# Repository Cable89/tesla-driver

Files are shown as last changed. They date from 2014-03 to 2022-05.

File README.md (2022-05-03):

# tesla-driver
Modular backplane based DRSSTC driver developed in my time as a student at Omega Verksted.

This is a mirror of a self hosted repo. (Sometimes unstable, or security settings change)
This mirror is not always up to date.
Original repo: https://git.omegav.no/teslakom/tesla-driver

Documentation: https://confluence.omegav.no/display/OV/Teslacoil
(Mostly in Norwegian, use google translate)

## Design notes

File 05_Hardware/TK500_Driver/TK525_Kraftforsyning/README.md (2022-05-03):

Ingen kretskort i dette prosjektet. Kun .PcbDoc for å kunne ha det med i multi board project

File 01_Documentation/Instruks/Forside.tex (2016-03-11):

\newgeometry{margin=2cm} %Sentrering av forside og tittelside
\begin{titlepage}
\thispagestyle{empty}
\centering
\textsc{\Huge Instruks for teslacoil} \\[3cm]

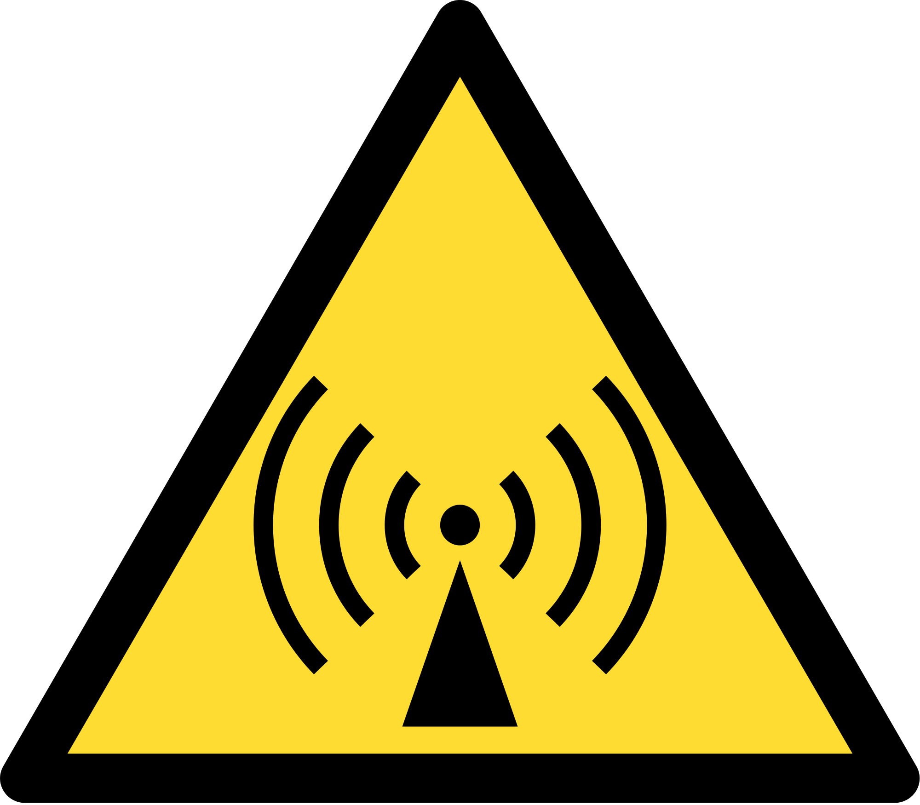
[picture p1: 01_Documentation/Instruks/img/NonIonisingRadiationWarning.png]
 \\[3cm]

\textsc{\Huge Teslakom} \\
\textsc{\Huge Omega Verksted} 

\end{titlepage}

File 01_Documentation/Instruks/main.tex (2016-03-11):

\documentclass[12pt,Norwegian,a4paper,twoside,openright,titlepage]{article}
\title{Autopilot}
\usepackage[utf8]{inputenc}
\usepackage[a4paper, bottom=4.0cm]{geometry}
\usepackage{amsmath,amsfonts,amssymb}
\usepackage{amsthm}                   
\usepackage{graphicx}  
\usepackage{subfig}         
\usepackage{listings}             
\usepackage{float}
\usepackage{lastpage}
\usepackage{fancyhdr}
\usepackage[]{natbib} %referanser
\usepackage{cleveref}
\pagestyle{fancy}
\usepackage{makeidx}  
\usepackage{ulem}
\usepackage{pdfpages}
\usepackage{url}
\usepackage[utf8]{inputenc}
\usepackage[T1]{fontenc}
\usepackage[english]{babel}
\usepackage{graphicx}			%Figurer
\usepackage{fancyhdr}			%Fancy headere
 
\makeindex
\fancyhf{}
\chead{Teslacoilinstruks}
\setlength{\oddsidemargin}{5mm}
\setlength{\evensidemargin}{5mm}

\begin{document}

  \input{forside}
  \cleardoublepage

  \cfoot{page \thepage}  
	\newpage
  \tableofcontents

  \newpage

  \pagenumbering{arabic}
  \cfoot{page \thepage\ of \pageref{LastPage}} 
  
  \input{overordnet}

  \newpage
  \bibliographystyle{plain}
  \bibliography{ref}

\end{document}

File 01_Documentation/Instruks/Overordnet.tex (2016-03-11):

Arbeidsoppgaver:
Overtesler
Hanskeholder
Fuckoperatør
Driveroperatør
Nødstopper
Vakter

I utgangspunktet en person pr. arbeidsoppgave, men overtesler kan ha to arbeidsoppgaver.

Overtesler skal ikke være samme person som Hanskeholder.

Overtesler velges først.

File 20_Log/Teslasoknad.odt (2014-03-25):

Søknad om penger til oppgradering av teslacoil

Omega Verksted søker med dette dokumentet om kr 6000,- til oppgradering av teslacoilen (til bruk blant annet på phaestum). Oppgraderingene består i å vikle ny sekundærspole, lage ny primærspole og stativ, og lage en ny driver og en reservedriver. Samt forbedre muligheter til input. Blant annet midi-inngang som muliggjør at Omega Bano kan spille gitar på teslacoil. Beløpet som søkes om er spesifisert i vedlagte busjett.

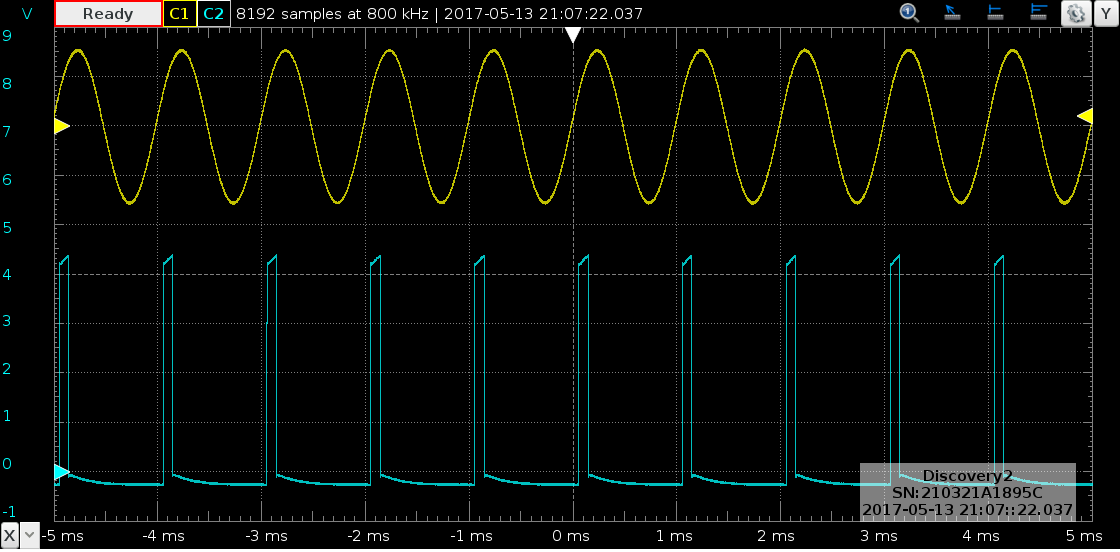
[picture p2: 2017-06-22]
01_Documentation/Målinger/Tesla/2017-05-13_X1-X2_2_1kHz.png

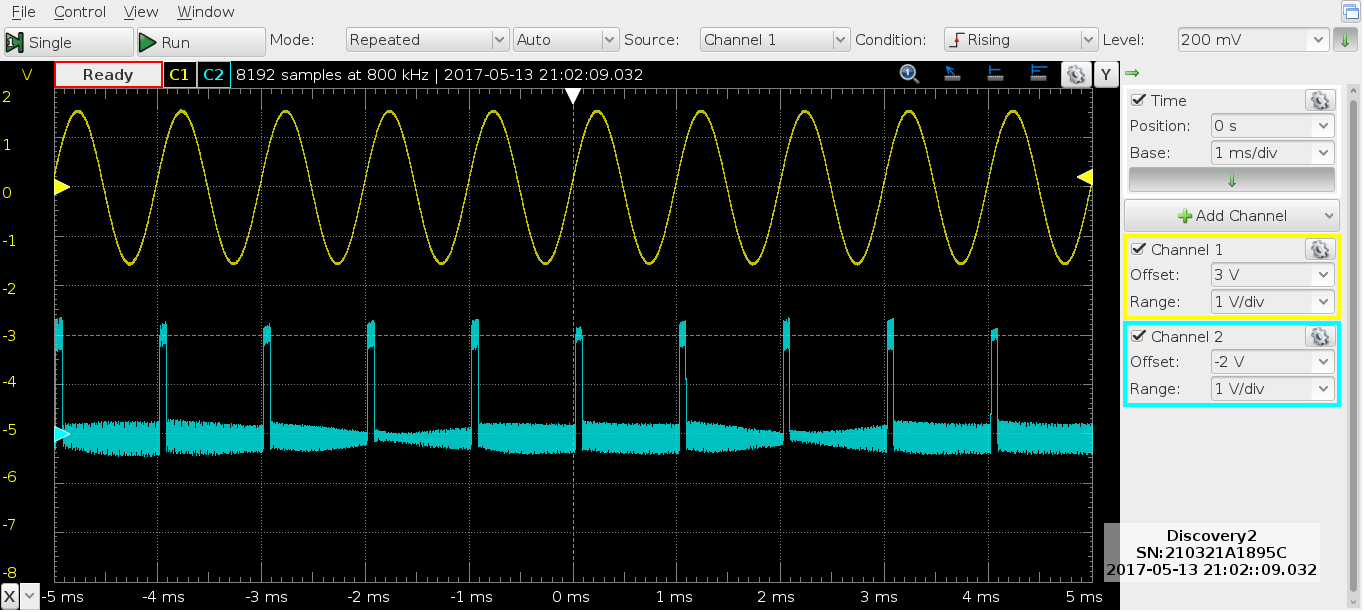
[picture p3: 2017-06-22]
01_Documentation/Målinger/Tesla/2017-05-13_X1-X2_1kHz.png

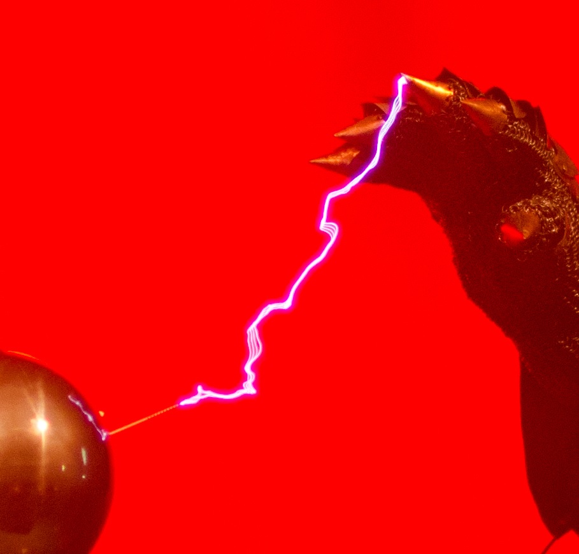
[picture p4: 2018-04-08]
01_Documentation/Figurer/Streamer.jpg

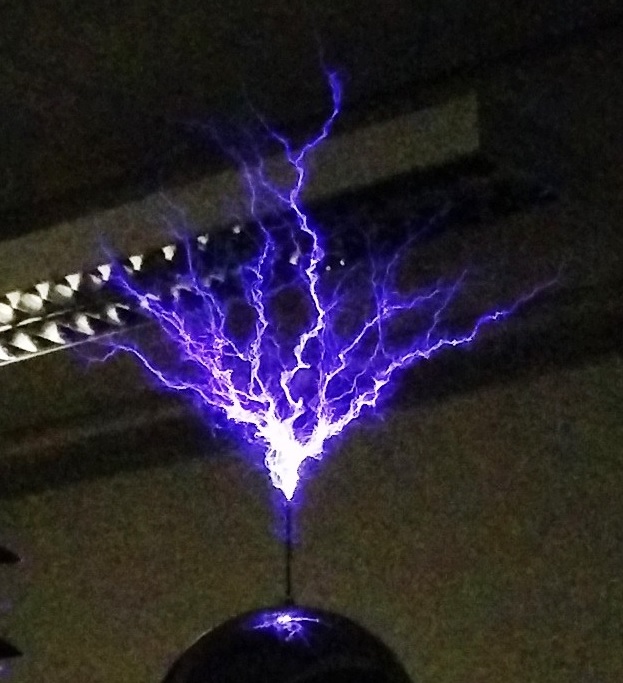
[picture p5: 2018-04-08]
01_Documentation/Figurer/Corona.jpg

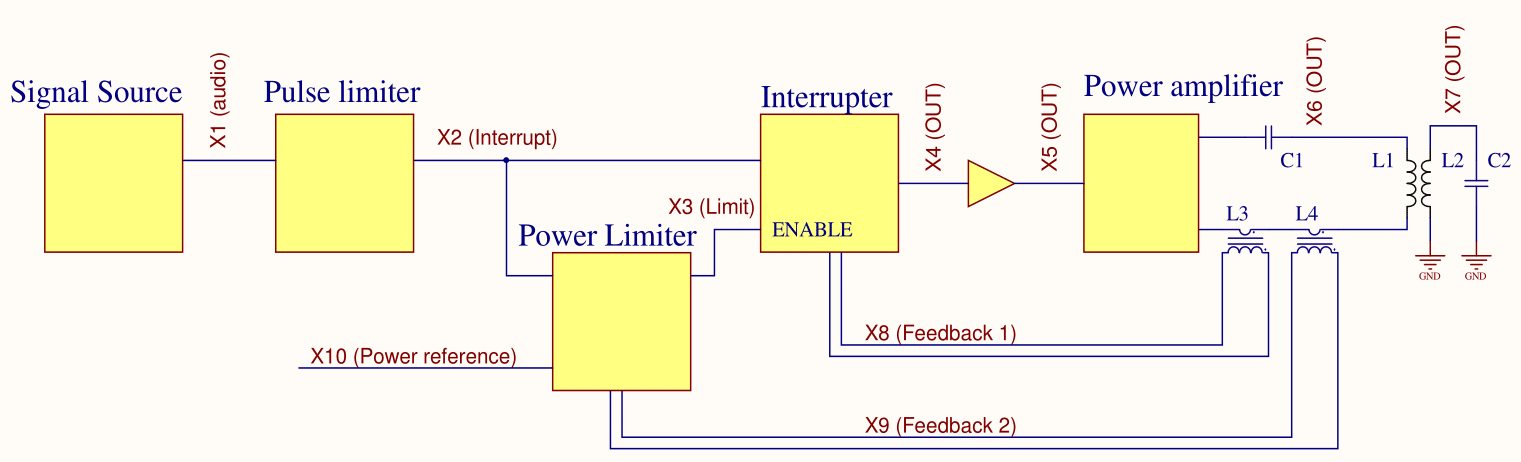
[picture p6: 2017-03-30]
01_Documentation/Figurer/FunksjonsBlokkskjema.png

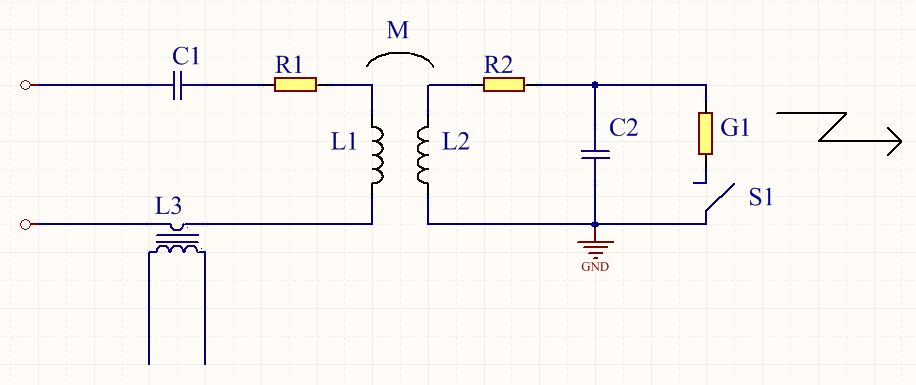
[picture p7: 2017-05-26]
01_Documentation/Forenklet skjema/Teslamodell_1.PNG

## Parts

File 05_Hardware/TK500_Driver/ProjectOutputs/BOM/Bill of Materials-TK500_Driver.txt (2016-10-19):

Designator	navn	beskrivelse	pris

"Q53002"	"TSM2314"	"N-Channel MOSFET"	"-1"
"Q53001"	"TSM2314"	"N-Channel MOSFET"	"-1"
"Q53000"	"TSM2314"	"N-Channel MOSFET"	"-1"
"Q51012"	"TSM2314"	"N-Channel MOSFET"	"-1"
"Q51008"	"TSM2314"	"N-Channel MOSFET"	"-1"
"Q51007"	"TSM2314"	"N-Channel MOSFET"	"-1"
"Q51006"	"TSM2314"	"N-Channel MOSFET"	"-1"
"Q51002"	"TSM2314"	"N-Channel MOSFET"	"-1"
"Q51001"	"TSM2314"	"N-Channel MOSFET"	"-1"
"Q51000"	"TSM2314"	"N-Channel MOSFET"	"-1"
"L52501"	"Skilletrafo 2:1"	""	"500"
"D53002"	"SMD LED Red"	"SMD"	"1"
"D53001"	"SMD LED Red"	"SMD"	"1"
"D53000"	"SMD LED Red"	"SMD"	"1"
"D52501"	"SMD LED Red"	""	"1"
"D51006"	"SMD LED Red"	"SMD"	"1"
"D51201"	"SMD LED Red"	"SMD"	"1"
"D51005"	"SMD LED Red"	"SMD"	"1"
"D51004"	"SMD LED Red"	"SMD"	"1"
"D51000"	"SMD LED Red"	"SMD"	"1"
"D51008"	"SMD LED Red"	"SMD"	"1"
"D51007"	"SMD LED Red"	"SMD"	"1"
"D53003"	"SMBJ5.0A-TR"	"Transient Voltage Suppressor, TVS, Transil SMBJ Series, Unidirectional, 5 V, SMD, 2, 6.4 V"	"1"
"M53100_TK531_2"	"SK-454-75-SA"	""	"14"
"M53100_TK531_1"	"SK-454-75-SA"	""	"14"
"T52001"	"SD250-3"	"Dual Gate Drive Transformer"	"-1"
"T52000"	"SD250-3"	"Dual Gate Drive Transformer"	"-1"
"D50213"	"Rød LED 5mm"	"LED, Red, 5mm, 643 nm, 1.8 V, 20 mA, 400 mcd"	"3"
"D50210"	"Rød LED 5mm"	"LED, Red, 5mm, 643 nm, 1.8 V, 20 mA, 400 mcd"	"3"
"D50207"	"Rød LED 5mm"	"LED, Red, 5mm, 643 nm, 1.8 V, 20 mA, 400 mcd"	"3"
"D50204"	"Rød LED 5mm"	"LED, Red, 5mm, 643 nm, 1.8 V, 20 mA, 400 mcd"	"3"
"D50201"	"Rød LED 5mm"	"LED, Red, 5mm, 643 nm, 1.8 V, 20 mA, 400 mcd"	"3"
"D50216"	"Rød LED 5mm"	"LED, Red, 5mm, 643 nm, 1.8 V, 20 mA, 400 mcd"	"3"
"J51400"	"PCIeX1-GF-2D-1000-1K-O36"	""	"0"
"J51100_TK511"	"PCIeX1-GF-2D-1000-1K-O36"	""	"0"
"J51100_TK511_2"	"PCIeX1-GF-2D-1000-1K-O36"	""	"0"
"J51005"	"PCI_Express-36P"	"PCI_Express-36P"	"16"
"J51004"	"PCI_Express-36P"	"PCI_Express-36P"	"16"
"J51003"	"PCI_Express-36P"	"PCI_Express-36P"	"16"
"J51002"	"PCI_Express-36P"	"PCI_Express-36P"	"16"
"J51001"	"PCI_Express-36P"	"PCI_Express-36P"	"16"
"J51000"	"PCI_Express-36P"	"PCI_Express-36P"	"16"
"J53100_TK531_1"	"MPTC-02-16-02-01-03-L-RA-SD"	""	"30"
"J53100_TK531_2"	"MPTC-02-16-02-01-03-L-RA-SD"	""	"30"
"J53002"	"MPSC-02-16-02-7.70-03-L-V-LC"	"SAMTEC Connector"	"30"
"J53001"	"MPSC-02-16-02-7.70-03-L-V-LC"	"SAMTEC Connector"	"30"
"J53000"	"MPSC-02-16-02-7.70-03-L-V-LC"	""	"30"
"U51000"	"MOCD207R2M"	""	"4"
"F53001"	"MC36214"	""	"2"
"F53000"	"MC36214"	""	"2"
"C52500"	"MAL209636222E3"	""	"340"
"L52501"	"Lampe"	""	"0"
"L52500"	"Lampe"	""	"0"
"M53005"	"KortStøtte"	"Støtter kort i bakplan"	"5"
"M53004"	"KortStøtte"	"Støtter kort i bakplan"	"5"
"M53003"	"KortStøtte"	"Støtter kort i bakplan"	"5"
"M53002"	"KortStøtte"	"Støtter kort i bakplan"	"5"
"M53001"	"KortStøtte"	"Støtter kort i bakplan"	"5"
"M53000"	"KortStøtte"	"Støtter kort i bakplan"	"5"
"M51017"	"KortStøtte"	"Støtter kort i bakplan"	"5"
"M51016"	"KortStøtte"	"Støtter kort i bakplan"	"5"
"M51015"	"KortStøtte"	"Støtter kort i bakplan"	"5"
"M51014"	"KortStøtte"	"Støtter kort i bakplan"	"5"
"M51013"	"KortStøtte"	"Støtter kort i bakplan"	"5"
"M51012"	"KortStøtte"	"Støtter kort i bakplan"	"5"
"M51011"	"KortStøtte"	"Støtter kort i bakplan"	"5"
"M51010"	"KortStøtte"	"Støtter kort i bakplan"	"5"
"M51009"	"KortStøtte"	"Støtter kort i bakplan"	"5"
"M51008"	"KortStøtte"	"Støtter kort i bakplan"	"5"
"M51007"	"KortStøtte"	"Støtter kort i bakplan"	"5"
"M51006"	"KortStøtte"	"Støtter kort i bakplan"	"5"
"M51005"	"KortStøtte"	"Støtter kort i bakplan"	"5"
"M51004"	"KortStøtte"	"Støtter kort i bakplan"	"5"
"M51003"	"KortStøtte"	"Støtter kort i bakplan"	"5"
"M51002"	"KortStøtte"	"Støtter kort i bakplan"	"5"
"M51001"	"KortStøtte"	"Støtter kort i bakplan"	"5"
"M51000"	"KortStøtte"	"Støtter kort i bakplan"	"5"
"K52501"	"Kontaktor"	""	"50"
"K52500"	"Kontaktor"	""	"50"
"K52500"	"Kontaktor"	""	"50"
"J53005"	"JST 4pin"	""	"2"
"J53004"	"JST 4pin"	""	"2"
"J53003"	"JST 4pin"	""	"2"
"J50203"	"JST 3pin"	""	"2"
"J50202"	"JST 3pin"	""	"2"
"J50201"	"JST 3pin"	""	"2"
"J50200"	"JST 3pin"	""	"2"
"J50205"	"JST 3pin"	""	"2"
"J50204"	"JST 3pin"	""	"2"
"J51025"	"JST 2pin"	"pris pr. stk."	"2"
"J51406"	"JST 2pin"	""	"2"
"J51017"	"JST 2pin"	"pris pr. stk."	"2"
"J51024"	"JST 2pin"	"pris pr. stk."	"2"
"J51023"	"JST 2pin"	"pris pr. stk."	"2"
"J51202"	"JST 2pin"	""	"2"
"J51201"	"JST 2pin"	""	"2"
"J51200"	"JST 2pin"	""	"2"
"J51016"	"JST 2pin"	"pris pr. stk."	"2"
"J51022"	"JST 2pin"	"pris pr. stk."	"2"
"J51021"	"JST 2pin"	"pris pr. stk."	"2"
"J51015"	"JST 2pin"	"pris pr. stk."	"2"
"J53006"	"JST 2pin"	""	"2"
"J51014"	"JST 2pin"	"pris pr. stk."	"2"
"J51013"	"JST 2pin"	"pris pr. stk."	"2"
"J51012"	"JST 2pin"	"pris pr. stk."	"2"
"J51006"	"JST 2pin"	""	"2"
"J51026"	"JST 2pin"	"pris pr. stk."	"2"
"J51203"	"JST 2pin"	""	"2"
"J51407"	"JST 2pin"	""	"2"
"J53008"	"JST 2pin"	""	"2"
"Q53005"	"IRLML6402"	"P-ch. MOSFET. -30V, -3.7A continuous,RDS(ON)=0.05Ohm@VGS=-4,5V, RDS(ON)=0.08Ohm@VGS=-2.5V"	"3"
"Q53004"	"IRLML6402"	"P-ch. MOSFET. -30V, -3.7A continuous,RDS(ON)=0.05Ohm@VGS=-4,5V, RDS(ON)=0.08Ohm@VGS=-2.5V"	"3"
"Q53003"	"IRLML6402"	"P-ch. MOSFET. -30V, -3.7A continuous,RDS(ON)=0.05Ohm@VGS=-4,5V, RDS(ON)=0.08Ohm@VGS=-2.5V"	"3"
"Q51011"	"IRLML6402"	"P-ch. MOSFET. -30V, -3.7A continuous,RDS(ON)=0.05Ohm@VGS=-4,5V, RDS(ON)=0.08Ohm@VGS=-2.5V"	"3"
"Q51010"	"IRLML6402"	"P-ch. MOSFET. -30V, -3.7A continuous,RDS(ON)=0.05Ohm@VGS=-4,5V, RDS(ON)=0.08Ohm@VGS=-2.5V"	"3"
"Q51009"	"IRLML6402"	"P-ch. MOSFET. -30V, -3.7A continuous,RDS(ON)=0.05Ohm@VGS=-4,5V, RDS(ON)=0.08Ohm@VGS=-2.5V"	"3"
"Q51005"	"IRLML6402"	"P-ch. MOSFET. -30V, -3.7A continuous,RDS(ON)=0.05Ohm@VGS=-4,5V, RDS(ON)=0.08Ohm@VGS=-2.5V"	"3"
"Q51004"	"IRLML6402"	"P-ch. MOSFET. -30V, -3.7A continuous,RDS(ON)=0.05Ohm@VGS=-4,5V, RDS(ON)=0.08Ohm@VGS=-2.5V"	"3"
"Q51003"	"IRLML6402"	"P-ch. MOSFET. -30V, -3.7A continuous,RDS(ON)=0.05Ohm@VGS=-4,5V, RDS(ON)=0.08Ohm@VGS=-2.5V"	"3"
"J51101_TK511_2"	"Header Shrouded 2X17P"	""	"10"
"J51027"	"Header Shrouded 2X17P"	""	"10"
"J50206"	"Header Shrouded 2X17P"	""	"10"
"J51101_TK511"	"Header Shrouded 2X17P"	""	"10"
"J51019"	"Header Shrouded 2X5P"	"Header"	"5"
"J51018"	"Header Shrouded 2X5P"	"Header"	"5"
"J53007"	"Header Shrouded 2X5P"	""	"5"
"J51011"	"Header Shrouded 2X5P"	"Header"	"5"
"J51010"	"Header Shrouded 2X5P"	"Header"	"5"
"J51009"	"Header Shrouded 2X5P"	"Header"	"5"
"J51020"	"Header Shrouded 2X5P"	"Header"	"5"
"J51106_TK511_2"	"Header 1x3"	""	"2"
"J51106_TK511"	"Header 1x3"	""	"2"
"J51105_TK511_2"	"Header 1x3"	""	"2"
"J51104_TK511"	"Header 1x3"	""	"2"
"J51105_TK511"	"Header 1x3"	""	"2"
"J51103_TK511_2"	"Header 1x3"	""	"2"
"J51104_TK511_2"	"Header 1x3"	""	"2"
"J51103_TK511"	"Header 1x3"	""	"2"
"J51102_TK511_2"	"Header 1x3"	""	"2"
"J51102_TK511"	"Header 1x3"	""	"2"
"D50212"	"Grønn LED 5mm"	"LED, Green, 5mm, 572 nm, 2.1 V, 20 mA, 150 mcd"	"3"
"D50211"	"Grønn LED 5mm"	"LED, Green, 5mm, 572 nm, 2.1 V, 20 mA, 150 mcd"	"3"
"D50209"	"Grønn LED 5mm"	"LED, Green, 5mm, 572 nm, 2.1 V, 20 mA, 150 mcd"	"3"
"D50208"	"Grønn LED 5mm"	"LED, Green, 5mm, 572 nm, 2.1 V, 20 mA, 150 mcd"	"3"
"D50206"	"Grønn LED 5mm"	"LED, Green, 5mm, 572 nm, 2.1 V, 20 mA, 150 mcd"	"3"
"D50205"	"Grønn LED 5mm"	"LED, Green, 5mm, 572 nm, 2.1 V, 20 mA, 150 mcd"	"3"
"D50203"	"Grønn LED 5mm"	"LED, Green, 5mm, 572 nm, 2.1 V, 20 mA, 150 mcd"	"3"
"D50202"	"Grønn LED 5mm"	"LED, Green, 5mm, 572 nm, 2.1 V, 20 mA, 150 mcd"	"3"
"D50200"	"Grønn LED 5mm"	"LED, Green, 5mm, 572 nm, 2.1 V, 20 mA, 150 mcd"	"3"
"D50217"	"Grønn LED 5mm"	"LED, Green, 5mm, 572 nm, 2.1 V, 20 mA, 150 mcd"	"3"
"D50215"	"Grønn LED 5mm"	"LED, Green, 5mm, 572 nm, 2.1 V, 20 mA, 150 mcd"	"3"
"D50214"	"Grønn LED 5mm"	"LED, Green, 5mm, 572 nm, 2.1 V, 20 mA, 150 mcd"	"3"
"U51200"	"GP1FAV50RK"	""	"12"
"D52500"	"GBJ2504"	""	"15"
"Q53101_TK531_2"	"G4PC50W"	""	"77"
"Q53101_TK531_1"	"G4PC50W"	""	"77"
"Q53100_TK531_2"	"G4PC50W"	""	"77"
"Q53100_TK531_1"	"G4PC50W"	""	"77"
"F52500"	"Automatsikring"	""	"0"
"S52512"	"Automasjonsbryter"	""	"0"
"S52504"	"Automasjonsbryter"	""	"0"
"S52503"	"Automasjonsbryter"	""	"0"
"S52502"	"Automasjonsbryter"	""	"0"
"S52501"	"Automasjonsbryter"	""	"0"
"S52500"	"Automasjonsbryter"	""	"0"
"R50223"	"330R"	""	"0"
"R50222"	"330R"	""	"0"
"R50221"	"330R"	""	"0"
"R50220"	"330R"	""	"0"
"R50219"	"330R"	""	"0"
"R50218"	"330R"	""	"0"
"R50215"	"330R"	""	"0"
"R50214"	"330R"	""	"0"
"R50213"	"330R"	""	"0"
"R50212"	"330R"	""	"0"
"R50211"	"330R"	""	"0"
"R50210"	"330R"	""	"0"
"R50207"	"330R"	""	"0"
"R50206"	"330R"	""	"0"
"R50205"	"330R"	""	"0"
"R50204"	"330R"	""	"0"
"R50203"	"330R"	""	"0"
"R50202"	"330R"	""	"0"
"R51200"	"300R"	""	"0"
"R52500"	"100 ohm"	""	"0"
"R1"	"100 ohm"	""	"0"
"C53000"	"100nF"	""	"1"
"R53006"	"100k"	""	"0"
"R53002"	"100k"	"100k 0.1W 5% Thick film resistor"	"0"
"R53001"	"100k"	"100k 0.1W 5% Thick film resistor"	"0"
"R53000"	"100k"	"100k 0.1W 5% Thick film resistor"	"0"
"R51040"	"100k"	"100k 0.1W 5% Thick film resistor"	"0"
"R51039"	"100k"	"100k 0.1W 5% Thick film resistor"	"0"
"R51038"	"100k"	"100k 0.1W 5% Thick film resistor"	"0"
"R51037"	"100k"	"100k 0.1W 5% Thick film resistor"	"0"
"R51036"	"100k"	"100k 0.1W 5% Thick film resistor"	"0"
"R51035"	"100k"	"100k 0.1W 5% Thick film resistor"	"0"
"R51034"	"100k"	"100k 0.1W 5% Thick film resistor"	"0"
"R51033"	"100k"	"100k 0.1W 5% Thick film resistor"	"0"
"R51032"	"100k"	"100k 0.1W 5% Thick film resistor"	"0"
"R51031"	"100k"	"100k 0.1W 5% Thick film resistor"	"0"
"R51030"	"100k"	"100k 0.1W 5% Thick film resistor"	"0"
"R51029"	"100k"	"100k 0.1W 5% Thick film resistor"	"0"
"R51028"	"100k"	"100k 0.1W 5% Thick film resistor"	"0"
"R51027"	"100k"	"100k 0.1W 5% Thick film resistor"	"0"
"R51026"	"100k"	"100k 0.1W 5% Thick film resistor"	"0"
"R51025"	"100k"	"100k 0.1W 5% Thick film resistor"	"0"
"R51024"	"100k"	"100k 0.1W 5% Thick film resistor"	"0"
"R51023"	"100k"	"100k 0.1W 5% Thick film resistor"	"0"
"R51022"	"100k"	"100k 0.1W 5% Thick film resistor"	"0"
"R51021"	"100k"	"100k 0.1W 5% Thick film resistor"	"0"
"R51017"	"100k"	"100k 0.1W 5% Thick film resistor"	"0"
"R51016"	"100k"	"100k 0.1W 5% Thick film resistor"	"0"
"R51015"	"100k"	"100k 0.1W 5% Thick film resistor"	"0"
"R51014"	"100k"	"100k 0.1W 5% Thick film resistor"	"0"
"R51013"	"100k"	"100k 0.1W 5% Thick film resistor"	"0"
"R51012"	"100k"	"100k 0.1W 5% Thick film resistor"	"0"
"R51011"	"100k"	"100k 0.1W 5% Thick film resistor"	"0"
"R51010"	"100k"	"100k 0.1W 5% Thick film resistor"	"0"
"R51006"	"100k"	"100k 0.1W 5% Thick film resistor"	"0"
"R51005"	"100k"	"100k 0.1W 5% Thick film resistor"	"0"
"R51004"	"100k"	"100k 0.1W 5% Thick film resistor"	"0"
"R51003"	"100k"	"100k 0.1W 5% Thick film resistor"	"0"
"R51002"	"100k"	"100k 0.1W 5% Thick film resistor"	"0"
"R51001"	"100k"	"100k 0.1W 5% Thick film resistor"	"0"
"R51000"	"100k"	"100k 0.1W 5% Thick film resistor"	"0"
"U51201"	"74HC14"	"Hex Schmitt trigger"	"4"
"R53005"	"47R"	"47R 0.1W 5% Thick film resistor"	"0"
"R53004"	"47R"	"47R 0.1W 5% Thick film resistor"	"0"
"R53003"	"47R"	"47R 0.1W 5% Thick film resistor"	"0"
"R51205"	"47R"	"47R 0.1W 5% Thick film resistor"	"0"
"R51020"	"47R"	"47R 0.1W 5% Thick film resistor"	"0"
"R51019"	"47R"	"47R 0.1W 5% Thick film resistor"	"0"
"R51018"	"47R"	"47R 0.1W 5% Thick film resistor"	"0"
"R51009"	"47R"	"47R 0.1W 5% Thick film resistor"	"0"
"R51008"	"47R"	"47R 0.1W 5% Thick film resistor"	"0"
"R51007"	"47R"	"47R 0.1W 5% Thick film resistor"	"0"
"R52502"	"16k"	""	"0"
"D53105_TK531_2"	"15ETX06"	"DIODE, HYPERFAST, 15A, 600V"	"26"
"D53105_TK531_1"	"15ETX06"	"DIODE, HYPERFAST, 15A, 600V"	"26"
"D53101_TK531_2"	"15ETX06"	"DIODE, HYPERFAST, 15A, 600V"	"26"
"D53101_TK531_1"	"15ETX06"	"DIODE, HYPERFAST, 15A, 600V"	"26"
"R50217"	"10k"	""	"0"
"R50216"	"10k"	""	"0"
"R50209"	"10k"	""	"0"
"R50208"	"10k"	""	"0"
"R50201"	"10k"	""	"0"
"R50200"	"10k"	""	"0"
"R53101_TK531_2"	"10"	""	"0"
"R53101_TK531_1"	"10"	""	"0"
"R53100_TK531_2"	"10"	""	"0"
"R53100_TK531_1"	"10"	""	"0"
"D53100_TK531_2"	"1V5KE400A"	"TVSdiode,  400V, 1500W"	"7"
"D53100_TK531_1"	"1V5KE400A"	"TVSdiode,  400V, 1500W"	"7"
"D53104_TK531_2"	"1V5KE400A"	"TVSdiode,  400V, 1500W"	"7"
"D53104_TK531_1"	"1V5KE400A"	"TVSdiode,  400V, 1500W"	"7"
"D53103_TK531_2"	"1N4744A"	"Zenerdiode 15V 1.3W"	"2"
"D53103_TK531_1"	"1N4744A"	"Zenerdiode 15V 1.3W"	"2"
"D53102_TK531_2"	"1N4744A"	"Zenerdiode 15V 1.3W"	"2"
"D53102_TK531_1"	"1N4744A"	"Zenerdiode 15V 1.3W"	"2"
"D53107_TK531_2"	"1N4744A"	"Zenerdiode 15V 1.3W"	"2"
"D53107_TK531_1"	"1N4744A"	"Zenerdiode 15V 1.3W"	"2"
"D53106_TK531_2"	"1N4744A"	"Zenerdiode 15V 1.3W"	"2"
"D53106_TK531_1"	"1N4744A"	"Zenerdiode 15V 1.3W"	"2"
"R50229"	"0R"	""	"0"
"R50228"	"0R"	""	"0"
"R50227"	"0R"	""	"0"
"R50226"	"0R"	""	"0"
"R50225"	"0R"	""	"0"
"R50224"	"0R"	""	"0"
"U51406"	""	""	""
"U51404"	""	""	""
"U51403"	""	""	""
"U51402"	""	""	""
"U51401"	""	""	""
"U51400"	""	""	""
"U51303"	""	""	""
"U51302"	""	""	""
"U51301"	""	""	""
"U51300"	""	""	""
"U51201"	""	""	""
"R51406"	""	""	""
"R51401"	""	""	""
"R51400"	""	""	""
"R51306"	""	""	""
"R51305"	""	""	""
"R51304"	""	""	""
"R51303"	""	""	""
"R51302"	""	""	""
"R51301"	""	""	""
"R51300"	""	""	""
"R51204"	""	""	""
"R51203"	""	""	""
"R51202"	""	""	""
"R51201"	""	""	""
"L51200"	""	""	""
"D51400"	""	""	""
"J51305"	""	""	""
"J51304"	""	""	""
"J51303"	""	""	""
"D51406"	""	""	""
"D51405"	""	""	""
"J51302"	""	""	""
"D51404"	""	""	""
"D51403"	""	""	""
"C51415"	""	""	""
"D51303"	""	""	""
"J51301"	""	""	""
"J51300"	""	""	""
"D51302"	""	""	""
"C51414"	""	""	""
"C51413"	""	""	""
"C51412"	""	""	""
"C51411"	""	""	""
"C51410"	""	""	""
"C51409"	""	""	""
"C51408"	""	""	""
"C51407"	""	""	""
"C51406"	""	""	""
"C51405"	""	""	""
"C51404"	""	""	""
"C51403"	""	""	""
"C51402"	""	""	""
"C51401"	""	""	""
"C51400"	""	""	""
"C51305"	""	""	""
"D51401"	""	""	""
"C51304"	""	""	""
"C51303"	""	""	""
"C51302"	""	""	""
"C51301"	""	""	""
"C51300"	""	""	""
"C51205"	""	""	""
"C51204"	""	""	""
"C51203"	""	""	""
"D51402"	""	""	""
"J52002"	""	""	""
"J52001"	""	""	""
"C51202"	""	""	""
"C51201"	""	""	""
"J52000"	""	""	""
"D51200"	""	""	""
"D51301"	""	""	""
"D51300"	""	""	""
"C51200"	""	""	""

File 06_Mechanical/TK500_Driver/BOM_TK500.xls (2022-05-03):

ITEM NO. | Filename | QTY.
1 | HFS5-2020-500 | 4
2 | HFS5-2020-135 | 8
3 | HFS5-2020-400 | 11
4 | HBLFSNF5_b | 40
5 | HFS5-2020-60 | 1
6 | Front | 1
7 | 3SU1000-1HB20-0AA0 | 1
8 | 3SU1000-0AB20-0AA0 | 1
9 | 3SU1002-2BF60-0AA0 | 1
10 | 19mm_vandal_alu | 6
11 | TK530_Kraftbakplan | 1
12 | TK531_Utgangstrinn | 2
13 | TK532_Kondensatorkort | 1
14 | 3SU1000-0AB40-0AA0 | 2
15 | NAC3MPB-1 | 1
16 | Innerbunn | 1
17 | Bakside | 1
18 | IEC-C14 | 1
19 | TK521_Optisk-plugg | 1
20 | Optical_bracket | 2
21 | TK510_Signalbakplan | 1
22 | TK511_Blindkort | 3
23 | TK512_Optisk_Mottaker | 1
24 | TK514_Interrupter | 1
25 | TK513_Limiter | 1
26 | TK520_GDT-Trafo | 1
27 | 1182N117 | 1
28 | TK502_Frontpanel_LEDs | 1
29 | Bottom | 1
30 | 3590P-1-103L | 1
31 | 22S-2D | 1
32 | DIN-Rail_180mm | 1
33 | DIN-Rail_220mm | 1
34 | WH100-100RJI | 2
35 | DIN-Rele | 1
36 | ABB Circuit Breaker | 2
37 | G_NSB0_XX_90459V | 1

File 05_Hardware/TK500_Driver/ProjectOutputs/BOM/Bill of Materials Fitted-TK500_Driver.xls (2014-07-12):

Designator | Quantity | Value | Description
C51200, C51400, C51402 | 3 | 10uF | CAP 10uF 25V ±10% 1206 (3216 Metric) Thickness 1.9mm SMD
C51201, C51202, C51203, C51205, C51404, C51405, C51406, C51407, C51409, C51410, C51412, C51413 | 12 | 100nF | CAP 100nF 25V ±5% 0805 (2012 Metric) Thickness 1.45mm SMD
C51204, C51303, C51408, C51415 | 4
C51300, C51301 | 2 | 100nF | CAP 100nF 50V ±5% 0805 (2012 Metric) Thickness 1mm SMD
C51302, C51304, C51305 | 3 | 100nF | CAP 100nF 50V ±5% 0805 (2012 Metric) Thickness 1mm SMD
C51401 | 1 | 100nF | CAP 100nF 25V ±10% 0805 (2012 Metric) Thickness 1.45mm SMD
C51403 | 1 | 22nF | CAP 22nF 25V ±5% 0805 (2012 Metric) Thickness 1.45mm SMD
C51411, C51414 | 2 | 1uF | CAP 1uF 25V ±5% 0805 (2012 Metric) Thickness 1.45mm SMD
D51000, D51001, D51002, D51003, D51004, D51005, D51006, D51007, D51008, D51009, D51010, D51011 | 12
D51200, D51400, D51403, D51406 | 4
D51300, D51301, D51302, D51303, D51402, D51405 | 6
D51401, D51404 | 2
D53100_TK531_1, D53100_TK531_2, D53104_TK531_1, D53104_TK531_2 | 4
D53101_TK531_1, D53101_TK531_2, D53105_TK531_1, D53105_TK531_2 | 4
D53102_TK531_1, D53102_TK531_2, D53103_TK531_1, D53103_TK531_2, D53106_TK531_1, D53106_TK531_2, D53107_TK531_1, D53107_TK531_2 | 8
J51000, J51001, J51002, J51003, J51004, J51005, J51006, J51007, J51008 | 9 |  | Board-to-Board Connector, PTH, Vertical, Pitch 1.00mm, 36-Position
J51009, J51010, J51011, J51018, J51019, J51020 | 6
J51012, J51013, J51014, J51015, J51016, J51017, J51021, J51022, J51023, J51024, J51025, J51026 | 12
J51027 | 1
J51028, J51029, J51030 | 3
J51200, J51201, J51202, J51203, J51300, J51301, J51302, J51304, J51305, J51400, J51401, J51402, J51403, J51404, J51405, J51406, J51407, J52001 | 18
J51303 | 1
J52000, J52002 | 2
L51200 | 1 | 15u
M1, M2, M3, M4, M5, M6, M7, M8, M9, M10, M11, M12, M13, M14, M15, M16, M17, M18 | 18
Q51000, Q51001, Q51002, Q51006, Q51007, Q51008, Q51012, Q51013, Q51014 | 9
Q51003, Q51004, Q51005, Q51009, Q51010, Q51011, Q51015, Q51016, Q51017 | 9
Q53100_TK531_1, Q53100_TK531_2, Q53101_TK531_1, Q53101_TK531_2 | 4
R51000, R51001, R51005, R51006, R51010, R51011, R51015, R51016, R51017, R51021 | 10
R51002, R51003, R51004, R51012, R51013, R51014, R51022, R51023, R51024 | 9
R51007, R51008, R51009, R51018, R51019, R51020, R51025, R51026, R51027, R51028, R51029, R51030 | 12
R51200, R51201, R51202, R51203, R51204 | 5 | 330.00 Ohm | 330R 0.125W 5% 0805 (2012 Metric) SMD
R51300, R51302 | 2 | 1K | 330R 0.125W 5% 0805 (2012 Metric) SMD
R51301 | 1 | 10R | 330R 0.125W 5% 0805 (2012 Metric) SMD
R51303, R51305, R51405, R51408, R51410 | 5 | 330R | 330R 0.125W 5% 0805 (2012 Metric) SMD
R51304, R51402, R51404, R51407, R51409 | 5 | 1k | 1K 0.125W 5% 0805 (2012 Metric) SMD
R51306 | 1 | 100k | 330R 0.125W 5% 0805 (2012 Metric) SMD
R51400 | 1 | 1k | 1K 0.125W 1% 0805 (2012 Metric) SMD
R51401 | 1 | 10R | 10R 0.125W 5% 0805 (2012 Metric) SMD
R51403 | 1 | 330R | 330R 0.125W 5% 0805 (2012 Metric) SMD
R51406 | 1 | 20k | 20K 0.125W 1% 0805 (2012 Metric) SMD
R53100_TK531_1, R53100_TK531_2, R53101_TK531_1, R53101_TK531_2 | 4 | 10R
T52000, T52001 | 2
U51200 | 1
U51201, U51302, U51401, U51406 | 4
U51300, U51404 | 2
U51301 | 1
U51303, U51405, U51407 | 3
U51400, U51403 | 2
U51402 | 1

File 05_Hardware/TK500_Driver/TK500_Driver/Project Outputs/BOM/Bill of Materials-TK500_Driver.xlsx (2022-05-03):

Line # | id | navn | Description | Designator | ModuleAssembly | Quantity | produsent | leverandor | leverandor_varenr | Manufacturer 1 | Manufacturer Part Number 1 | Manufacturer Lifecycle 1 | Supplier 1 | Supplier Part Number 1 | Supplier Unit Price 1 | Supplier Subtotal 1
 | 4153 | 100nF | 2kV(kanskje) polypropylene film capacitor, D22, L50 | C1, C2, C3, C4 | TK532_Kondensatorkort.PcbDoc | 4 | Cornell Dubilier | Farnell | 2347676
 | 5152 | 100nF | X7R 50V 5% | C1, C2, C3, C4, C5, C6, C7, C8, C9, C10, C11, C12, C53000 | TK513_Limiter.PcbDoc, TK514_Interrupter.PcbDoc, TK516_LINREG-PSU.PcbDoc, TK512_Optisk_Mottaker.PcbDoc, TK530_Kraftbakplan.PcbDoc | 22 | Multicomp | Farnell | 1759122
 | 3290 | 330uF | 25V elektrolytt | C1, C6 | TK516_LINREG-PSU.PcbDoc | 6 | Rubycon | Farnell | 2346202
 | 3687 | 1nF | X7R 50V 5% | C2, C3, C4 | TK513_Limiter.PcbDoc, TK512_Optisk_Mottaker.PcbDoc | 3 | Multicomp | Farnell | 2310598
 | 3316 | 220nF | X7R 25V 10% | C2, C8 | TK516_LINREG-PSU.PcbDoc | 6 | Samsung | Farnell | 3013426
 | 5154 | 1uF | X7R 50V | C2, C10, C11 | TK512_Optisk_Mottaker.PcbDoc, TK514_Interrupter.PcbDoc | 3 | Multicomp | Farnell | 1759454
 | 5155 | 47pF | NP0 50V 5% | C3 | TK512_Optisk_Mottaker.PcbDoc | 1 | WALSIN | Farnell | 2496905
 | 4164 | 4.7uF | X5R 10V 10% | C4 | TK516_LINREG-PSU.PcbDoc | 3 | Samsung | Farnell | 3013462
 | 3114 | 10uF | X5R 6.3V 10% | C5 | TK516_LINREG-PSU.PcbDoc | 3 |  | Farnell | 2320852
 | 5303 | 1uF | X7R 50V 10% | C5 | TK512_Optisk_Mottaker.PcbDoc | 1 | Murata | Farnell | 1735541
 | 4858 | 100uF | 25V 2.5mm pitch | C6 | TK512_Optisk_Mottaker.PcbDoc, TK513_Limiter.PcbDoc | 2 | Panasonic | Farnell | 1848439
 | 4844 | 2200uF | 6.3V, Elektrolytt, 5mm lead spacing | C7 | TK516_LINREG-PSU.PcbDoc | 3 | Multicomp | Farnell | 2627680
 | 5192 | 22uF | 10V 10% Tantalum | C7 | TK512_Optisk_Mottaker.PcbDoc, TK513_Limiter.PcbDoc | 2 | Kemet | Farnell | 1457420
 | 5059 | 10uF | X5R 50V 10% | C13, C14 | TK514_Interrupter.PcbDoc | 2 | Murata | Farnell | 2672214
 | 3491 | 22nF | X7R 50V | C15 | TK514_Interrupter.PcbDoc | 1 | Multicomp | Farnell | 1414682
 | 3076 | MAL209636222E3 | CAP, ALU ELEC, 2200UF, 400V | C52500 | dummy.PcbDoc | 1 | Vishay | Farnell | 2342176 | Vishay BCcomponents | MAL209636222E3 | Volume Production | Farnell | 2342176 | 59.86 | 59.86
 | 4891 | 15ETX06 | DIODE, HYPERFAST, 15A, 600V | D1, D2 | TK531_Utgangstrinn.PcbDoc | 4 | Vishay | Farnell | 8656991 | Vishay Semiconductors | 15ETX06 | Obsolete
 | 5238 | 1N5819 | Schottkydiode, 1A, 40V | D1, D2, D3, D4, D6 | TK513_Limiter.PcbDoc, TK514_Interrupter.PcbDoc | 6 | Multicomp | Farnell | 7429304, 1336533 | Multicomp | 1N5819 | Volume Production
 | 4485 | 1N4148 SMD | SMD signaldiode | D1, D2, D7 | TK514_Interrupter.PcbDoc, TK512_Optisk_Mottaker.PcbDoc | 4 | Taiwan Semiconductor | Farnell | 8150206
 | 5138 | Grønn LED 5mm | LED, Green, 5mm, 572 nm, 2.1 V, 20 mA, 150 mcd | D1, D3, D4, D6, D7, D9, D10, D12, D13, D15, D16, D18 | TK502_Frontpanel_LEDs.PcbDoc | 12 | Multicomp | Farnell | 2112108
 | 5143 | SMD LED Red | SMD | D1, D3, D51000, D51001, D51002, D51003, D51004, D51005, D51006, D51007, D51008, D51009, D51010, D53000, D53001, D53002 | TK512_Optisk_Mottaker.PcbDoc, TK516_LINREG-PSU.PcbDoc, TK510_Signalbakplan.PcbDoc, TK530_Kraftbakplan.PcbDoc | 19 | Avago | Farnell | 8554641
 | 5305 | Rød LED 5mm | LED, Red, 5mm, 643 nm, 1.8 V, 20 mA, 400 mcd | D2, D5, D8, D11, D14, D17 | TK502_Frontpanel_LEDs.PcbDoc | 6 | Multicomp | Farnell | 2112111
 | 3261 | 1V5KE400A | TVS diode, 400V, 1500W | D3, D4 | TK531_Utgangstrinn.PcbDoc | 4 | Fairchild | Farnell | 1017630 | ON Semiconductor / Fairchild | 1V5KE400A | Volume Production
 | 3264 | 1N5337 | Zenerdiode 4.7V 5W | D4, D5 | TK514_Interrupter.PcbDoc | 2 | ON Semiconductor | Farnell | 9557946
 | 4876 | 1N4744A | Zenerdiode 15V 1.3W | D5, D6, D7, D8 | TK531_Utgangstrinn.PcbDoc | 8 | Vishay | Farnell | 1612369 | Vishay Semiconductors | 1N4744A | Volume Production | Farnell | 1612368 | 0.12722 | 1.02
 | 3322 | GBJ2504 | diodebro/Likeretterbro 400V 25A | D52500 | dummy.PcbDoc | 1 |  | Farnell | 1651042
 | 3117 | LED Rød | Farget LED, 5mm | D52501 | dummy.PcbDoc | 1 | -
 | 5314 | SMBJ5.0A-TR | Transient Voltage Suppressor, TVS, Transil SMBJ Series, Unidirectional, 5 V, SMD, 2, 6.4 V | D53003 | TK530_Kraftbakplan.PcbDoc | 1 | ST Microelectronics | Farnell | 9886311 | STMicroelectronics | SMBJ5.0A-TR | Volume Production | Farnell | 9886311 | 0.52175 | 2.61
 | 2977 | Automatsikring | 2-Pol | F1 | dummy.PcbDoc | 1 | ABB | Farnell | 2492800
 | 5311 | MC36214 | FUSE, PTC RESET, SMD, 16V, 500MA | F53000, F53001 | TK530_Kraftbakplan.PcbDoc | 2 | Multicomp | Farnell | 1861181 | Multicomp | MC36214 | Volume Production
 | 3037 | PCIeX1-GF-2D-1000-1K-O36 | PCI express PCB kortkankonnektor | J1 | TK511_Blindkort.PcbDoc, TK512_Optisk_Mottaker.PcbDoc, TK513_Limiter.PcbDoc, TK514_Interrupter.PcbDoc, TK516_LINREG-PSU.PcbDoc | 8 | PCB feature
 | 3221 | MPTC-02-16-02-01-03-L-RA-SD | SAMTEC Connector | J1 | TK531_Utgangstrinn.PcbDoc, TK532_Kondensatorkort.PcbDoc | 3 | SAMTEC | Mouser | MPTC-02-16-02-01-03-L-RA-SD | Samtec | MPTC-02-16-02-01-03-L-RA-SD |  | Mouser | 200-MPTC0216213LRASD | 8.62 | 25.86
 | 4473 | B3B-XH-A (LF)(SN) | JST 3pin (pris pr. stk.) | J1, J2, J3, J4, J5, J6 | TK502_Frontpanel_LEDs.PcbDoc | 6 | JST | Farnell | 1516277 | JST | B3B-XH-A(LF)(SN) | Volume Production | RSComponents | 8201557 | 0.388 | 2.33
 | 3259 | Header 2X17 Shrouded | Header | J2, J7, J51027 | TK511_Blindkort.PcbDoc, TK502_Frontpanel_LEDs.PcbDoc, TK510_Signalbakplan.PcbDoc | 4 | Amphenol | Farnell | 2215313
 | 5095 | Header 1x3 | 2,54mm pitch | J3, J4, J5, J6, J7 | TK511_Blindkort.PcbDoc | 10 | SAMTEC | Farnell | 3690124
 | 3222 | PCI_Express-36P | PCI_Express-36P | J51000, J51001, J51002, J51003, J51004, J51005, J51007, J51008, J51028 | TK510_Signalbakplan.PcbDoc | 9 | FCI | Farnell | 1144435
 | 4043 | B2B-XH-A (LF)(SN) | JST 2pin (pris pr. stk.) | J51006, J51012, J51013, J51014, J51015, J51016, J51017, J51021, J51022, J51023, J51024, J51025, J51026, J51029, J51030, J51031, J51032, J51033, J51034, J51035, J51036, J51037, J51038, J51039, J51040, J51041, J51042, J51043, J51044, J51045, J51046, J51047, J51048, J51049, J51050, J52001, J53006, J53008 | TK510_Signalbakplan.PcbDoc, TK520_GDT-Trafo.PcbDoc, TK530_Kraftbakplan.PcbDoc | 38 | JST | Farnell | 1516276 | JST | B2B-XH-A(LF)(SN) | Volume Production | RSComponents | 8201554 | 0.204 | 7.75
 | 3224 | Header 2X5 Shrouded | Header | J51009, J51010, J51011, J51018, J51019, J51020, J53007 | TK510_Signalbakplan.PcbDoc, TK530_Kraftbakplan.PcbDoc | 7 | Amphenol | Farnell | 2215304
 | 3046 | B4B-XH-A (LF)(SN) | JST 4pin (pris pr. stk.) | J52000, J52002, J53003, J53004, J53005 | TK520_GDT-Trafo.PcbDoc, TK530_Kraftbakplan.PcbDoc | 5 | JST | Farnell | 1516278 | JST | B4B-XH-A -LF-SN
 | 3220 | MPSC-02-16-02-7.70-03-L-V-LC | SAMTEC Connector | J53000, J53001, J53002 | TK530_Kraftbakplan.PcbDoc | 3 | SAMTEC | Mouser | MPSC-02-16-02-7.70-03-L-V-LC | Samtec | MPSC-02-16-02-7.70-03-L-V-LC |  | Mouser | 200-C02160277003LVLC | 9.91 | 29.73
 | 3646 | 0R | 0.1W 1% Thick film resistor, Jumper | JP1, R3, R4, R13, R14, R23, R24 | TK516_LINREG-PSU.PcbDoc, TK502_Frontpanel_LEDs.PcbDoc, TK512_Optisk_Mottaker.PcbDoc | 10 | multicomp | Farnell | 2447060
 | 3272 | DIN-Rele 5V | Coil: 5VDC, Contact: 250VAC 6A, DIN mount | K1, K52501 | dummy.PcbDoc | 2 | ABB | Farnell | 1895933
 | 2948 | Kontaktor | Industriellt rele | K2 | dummy.PcbDoc | 1 | IMO | Farnell | 9940480
 | 6201 | Spole 15H | Wirewound Inductor, 15 µH, 2.8 ohm, 20 MHz, 130 mA | L1 | TK512_Optisk_Mottaker.PcbDoc, TK514_Interrupter.PcbDoc | 2 | TDK | Farnell | 2747875
 | 3842 | Skilletrafo 2:1 | Skilletrafo Ringkjerne | L52501 | dummy.PcbDoc | 1 | Hammond | Farnell | 2546942
 | 4718 | SK-454-75-SA | Heatsink | M1 | TK531_Utgangstrinn.PcbDoc | 2 | FischerElektronik | Farnell | 1850030
 | 3273 | Lask til 2.5mm2 Rekkeklemme 10way | Jumper (Busbar), Cross Jumper, DIN Rail Screw Clamp Terminal Blocks, 10 Ways | M1, M2 | dummy.PcbDoc | 2 | Multicomp | Farnell | 2061384
 | 6258 | Automasjonsbryter holder | Assembly Hardware, Siemens 3-Way Modules, Holder, SIRIUS ACT 3SU Series | M3, M4, M5, M6, M7 | dummy.PcbDoc | 5 | Siemens | Farnell | 2695729
 | 3242 | KortStøtte 84mm | Støtter kort i bakplan | M51000, M51001, M51002, M51003, M51004, M51005, M51006, M51007, M51008, M51009, M51010, M51011, M51012, M51013, M51014, M51015, M51016, M51017 | TK510_Signalbakplan.PcbDoc | 18
 | 4028 | KortStøtte 50mm | Støtter kort i bakplan | M53000, M53001, M53002, M53003, M53004, M53005 | TK530_Kraftbakplan.PcbDoc | 6
 | 4877 | G4PC50W | IGBT, 600V, 55A | Q1, Q2 | TK531_Utgangstrinn.PcbDoc | 4 | International Rectifier | Farnell | 8650632 | International Rectifier | G4PC50W
 | 3085 | BSH201 | P-Channel MOSFET 300mA | Q1, Q2, Q3, Q5, Q51003, Q51004, Q51005, Q51009, Q51010, Q51011, Q51016, Q51017, Q51018, Q51020, Q51021, Q53003, Q53004, Q53005 | TK514_Interrupter.PcbDoc, TK513_Limiter.PcbDoc, TK512_Optisk_Mottaker.PcbDoc, TK510_Signalbakplan.PcbDoc, TK530_Kraftbakplan.PcbDoc | 19 | NXP Semiconductors | Farnell | 1758073 | NXP Semiconductors | BSH201
 | 3075 | 2N7002 | N-Channel MOSFET 300mA | Q1, Q4, Q51000, Q51001, Q51002, Q51006, Q51007, Q51008, Q51012, Q51013, Q51014, Q51015, Q51019, Q53000, Q53001, Q53002 | TK513_Limiter.PcbDoc, TK512_Optisk_Mottaker.PcbDoc, TK510_Signalbakplan.PcbDoc, TK530_Kraftbakplan.PcbDoc | 16 | Nexperia, [NoParam] | Farnell | 1829184 | NXP Semiconductors | 2N7002
 | 5228 | 560R | 0.1W 1% Thick film resistor | R1 | TK516_LINREG-PSU.PcbDoc | 3 | Multicomp | Farnell | 2447397
 | 3890 | 10 | 0.25W 1% Generic resistor | R1, R2 | TK531_Utgangstrinn.PcbDoc | 4 | Multicomp | Farnell | 9341145
 | 6251 | 100R | 100 Ohm, 100W Resistor, Solder Lug, Wirewound +-5% 1.9kV | R1, R2 | dummy.PcbDoc | 2 | TT electronics | Farnell | 1768214
 | 5264 | 10k | 0.1W 1% Thick film resistor | R1, R2, R11, R12, R21, R22, R51000, R51001, R51002, R51003, R51004, R51005, R51006, R51010, R51011, R51012, R51013, R51014, R51015, R51016, R51017, R51021, R51022, R51023, R51024, R51025, R51026, R51027, R51028, R51029, R51030, R51031, R51032, R51033, R51034, R51035, R51036, R51037, R51038, R51039, R51040, R51041, R51042, R51043, R53000, R53001, R53002, R53006 | TK502_Frontpanel_LEDs.PcbDoc, TK512_Optisk_Mottaker.PcbDoc, TK510_Signalbakplan.PcbDoc, TK530_Kraftbakplan.PcbDoc | 49 | Multicomp | Farnell | 2447230
 | 5339 | 1k | 0.1W 1% Thick film resistor | R1, R3 | TK513_Limiter.PcbDoc, TK514_Interrupter.PcbDoc | 3 | Multicomp | Farnell | 2447272
 | 5040 | 10R | 0.1W 1% Thick film resistor | R2 | TK514_Interrupter.PcbDoc | 1 | Multicomp | Farnell | 2447556
 | 5657 | 10R | 0.1W 1% Thick film resistor | R2 | TK513_Limiter.PcbDoc | 1 | Multicomp | Farnell | 2447233
 | 5343 | 330R | 0.1W 1% Thick film resistor | R2, R5, R6, R7, R8, R9, R10, R15, R16, R17, R18, R19, R20, R25, R26, R27, R28, R29, R30, R51007, R51008, R51009, R51018, R51019, R51020, R51044, R51045, R51046, R51047, R51048, R51049 | TK512_Optisk_Mottaker.PcbDoc, TK502_Frontpanel_LEDs.PcbDoc, TK510_Signalbakplan.PcbDoc | 32 | Multicomp | Farnell | 2447339
 | 5336 | 910R | 0.1W 1% Thick film resistor | R3 | TK512_Optisk_Mottaker.PcbDoc | 1 | Multicomp | Farnell | 2447448
 | 5340 | 1M | 0.1W 1% Thick film resistor | R3, R4, R6, R7, R8, R9 | TK531_Utgangstrinn.PcbDoc, TK514_Interrupter.PcbDoc | 8 | Multicomp | Farnell | 2073358
 | 5357 | 20k | 0.1W 1% Thick film resistor | R3, R6 | TK514_Interrupter.PcbDoc, TK512_Optisk_Mottaker.PcbDoc | 2 | Multicomp | Farnell | 2447293
 | 3778 | 100k | 0.1W 1% Thick film resistor | R4 | TK513_Limiter.PcbDoc | 1 | Multicomp | Farnell | 2447226
 | 3823 | Trimmepot 100ohm | 15 turn, horizontal | R4, R5 | TK514_Interrupter.PcbDoc, TK513_Limiter.PcbDoc | 2 | Bourns | Farnell | 9352279
 | 5347 | 15k | 0.1W 1% Thick film resistor | R5 | TK512_Optisk_Mottaker.PcbDoc | 1 | Multicomp | Farnell | 2447226
 | 3759 | 16k | 0.25W 1% Generic resistor | R52502 | dummy.PcbDoc | 1
 | 4889 | 47R | 0.1W 1% Thick film resistor | R53003, R53004, R53005 | TK530_Kraftbakplan.PcbDoc | 3 | Multicomp | Farnell | 2447378
 | 6252 | Automasjonsvelger Grønn | Switch Actuator, Siemens 22mm Pushbutton Switches | S1, S3 | dummy.PcbDoc | 2 | Siemens | Farnell | 2695623
 | 6257 | Automasjonsbryter NO | Contact Block, SPST-NO, 10 A, 500 V, 1 Pole, 3SU Series, Screw | S1, S3, S3B, S3C | dummy.PcbDoc | 4 | Siemens | Farnell | 2695771
 | 6253 | Automasjonsvelger Rød | Switch Actuator, Siemens 22mm Pushbutton Switches | S2 | dummy.PcbDoc | 1 | Siemens | Farnell | 2695622
 | 6256 | Automasjonsbryter NC | Contact Block, SPST-NC, 10 A, 500 V, 1 Pole, 3SU Series, Screw | S2, S3B, S4, S4B, S5, S5B | dummy.PcbDoc | 6 | Siemens | Farnell | 2695772
 | 6255 | Automasjonsvelger Nødstopp | Switch Actuator, Siemens 22mm Emergency Stop Mushroom Pushbutton Switches | S4 | dummy.PcbDoc | 1 | Siemens | Farnell | 2695631
 | 6254 | Automasjonsvelger Vrider bistabil | Switch Actuator, Siemens 22mm Selector Switches | S5 | dummy.PcbDoc | 1 | Siemens | Farnell | 2695653
 | 3215 | SD250-3 | Dual gate drive transformer | T52000, T52001 | TK520_GDT-Trafo.PcbDoc | 2 | Coilcraft |  |  | Coilcraft | SD250-3
 | 5093 | Header 1x1 | 2,54mm pitch | TP1, TP2, TP3, TP4, TP5, TP6, TP7, TP8 | TK512_Optisk_Mottaker.PcbDoc, TK513_Limiter.PcbDoc, TK514_Interrupter.PcbDoc | 19
 | 3211 | 74HC74 | Dual D flip flop | U1 | TK513_Limiter.PcbDoc, TK514_Interrupter.PcbDoc | 2 | Texas Instruments | Farnell | 9591680 | Texas Instruments | 74HC74
 | 4338 | LM7812 | Voltage Regulator | U1 | TK516_LINREG-PSU.PcbDoc | 3 | Fairchild | Farnell | 1467365
 | 4400 | 74HC14 | Hex Schmitt trigger | U1, U2, U7 | TK512_Optisk_Mottaker.PcbDoc, TK514_Interrupter.PcbDoc | 3 | ON Semiconductor | Farnell | 1607772
 | 3241 | LM311 | Comparator, High Speed | U2 | TK513_Limiter.PcbDoc | 1 | Texas Instruments | Farnell | 2293183 | Texas Instruments | LM311 | Volume Production
 | 3342 | LM78L05 | Voltage Regulator | U2 | TK516_LINREG-PSU.PcbDoc | 3 | Onsemi | Farnell | 9666095
 | 3665 | 74HCT1G125GW-Q100H | Buffer / Line Driver, 74HCT1G125, 4.5 V to 5.5 V, TSSOP-5 | U2, U3 | TK512_Optisk_Mottaker.PcbDoc | 2 | NXP Semiconductors | Farnell | 1105927 | Nexperia | 74HCT1G125GW-Q100H |  | Mouser | 77174HCT1G125GWQ100H | 0.47 | 0.94
 | 6202 | DBLS207G RDG | Bridge Rectifier, Dual-In-Line, Single Phase, 1 kV, 2 A | U3 | TK516_LINREG-PSU.PcbDoc | 3 | Taiwan Semiconductor | Farnell | 3519283 | Taiwan Semiconductor | DBLS207G RDG |  | Farnell | 3519283 | 1.09 | 3.27
 | 3238 | 74HC08 | Quad And Gate | U3, U4 | TK514_Interrupter.PcbDoc | 2 | Toshiba | Farnell | 9590986 | Toshiba | 74HC08
 | 3223 | MIC4422YM | Mosfet Driver | U5, U6 | TK514_Interrupter.PcbDoc | 2 | Microchip | Farnell | 2510119 | Microchip | MIC4422YM | Volume Production | RSComponents | 1770411 | 1.96 | 186.58
 | 3444 | MOCD207R2M | Dual Optocoupler | U51000 | TK510_Signalbakplan.PcbDoc | 1 | Fairchild | Farnell | 1086672 | ON Semiconductor / Fairchild | MOCD207R2M | Volume Production
 | 3304 | Rekkeklemme 2.5mm2 | DIN Rail mount terminal block | X1.1, X1.10, X1.11, X1.12, X1.13, X1.14, X1.15, X1.16, X1.17, X1.18, X1.19, X1.2, X1.20, X1.21, X1.22, X1.26, X1.27, X1.3, X1.4, X1.5, X1.6, X1.7, X1.8, X1.9 | dummy.PcbDoc | 24 | Multicomp | Farnell | 2061376

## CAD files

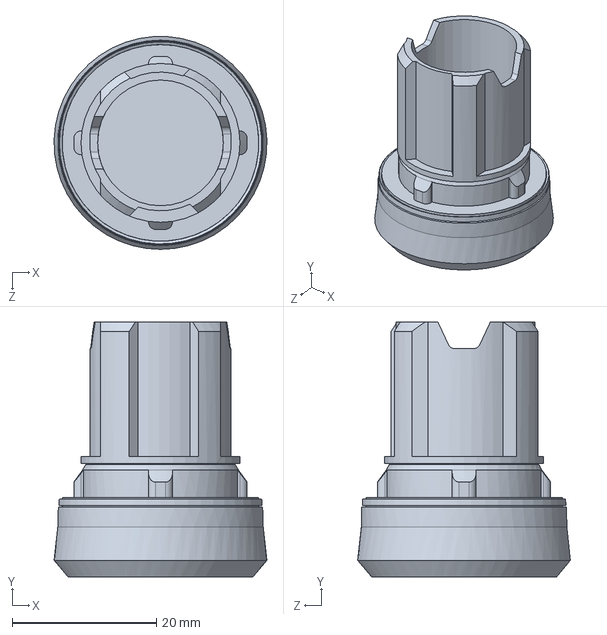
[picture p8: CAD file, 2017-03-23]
06_Mechanical/TK500_Driver/Siemens/3SU1000-0AB40-0AA0.SLDASM
29.5 x 35.3 x 29.5 mm

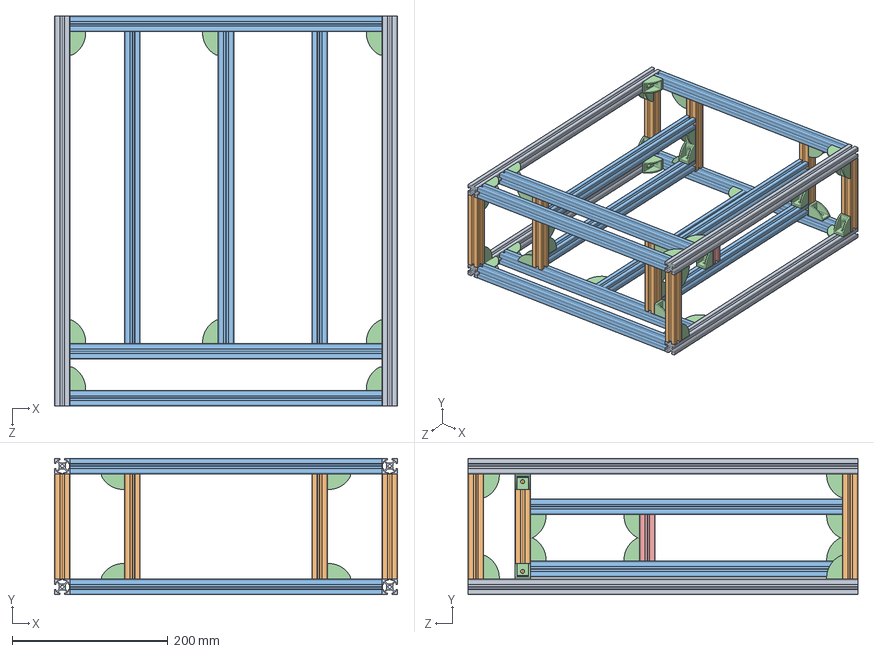
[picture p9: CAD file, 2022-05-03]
06_Mechanical/TK500_Driver/Chassis.SLDASM
440.0 x 175.0 x 500.0 mm
HFS5-2020-500 x 4
HFS5-2020-135 x 8
HFS5-2020-400 x 11
HBLFSNF5_b x 40
HFS5-2020-60

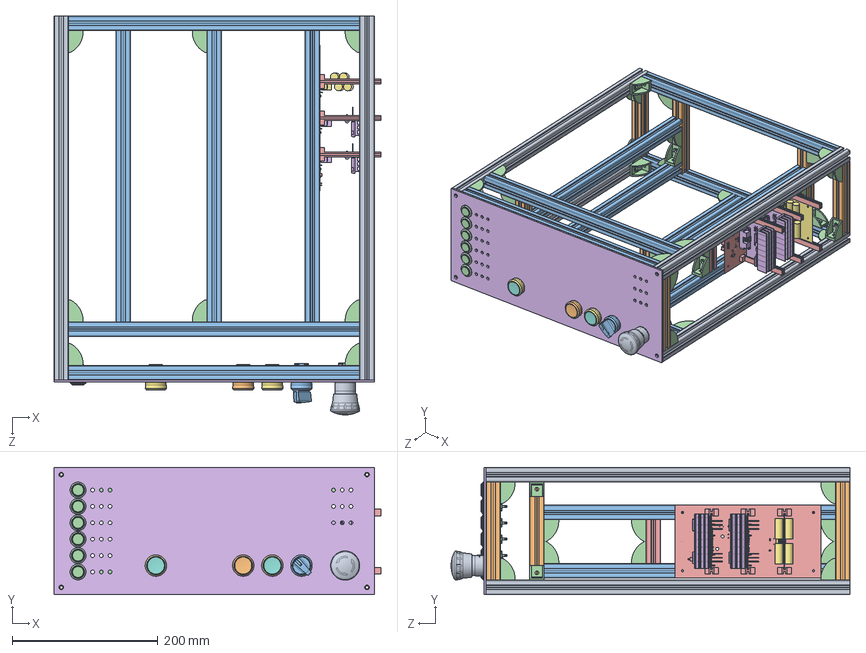
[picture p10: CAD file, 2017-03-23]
06_Mechanical/TK500_Driver/TK500.SLDASM
449.2 x 175.0 x 548.0 mm
HFS5-2020-500 x 4
HFS5-2020-135 x 8
HFS5-2020-400 x 11
HBLFSNF5_b x 40
HFS5-2020-60
Front
3SU1000-1HB20-0AA0
3SU1000-0AB20-0AA0
3SU1002-2BF60-0AA0
19mm_vandal_alu x 6
TK530_Kraftbakplan
TK531_Utgangstrinn x 2
TK532_Kondensatorkort

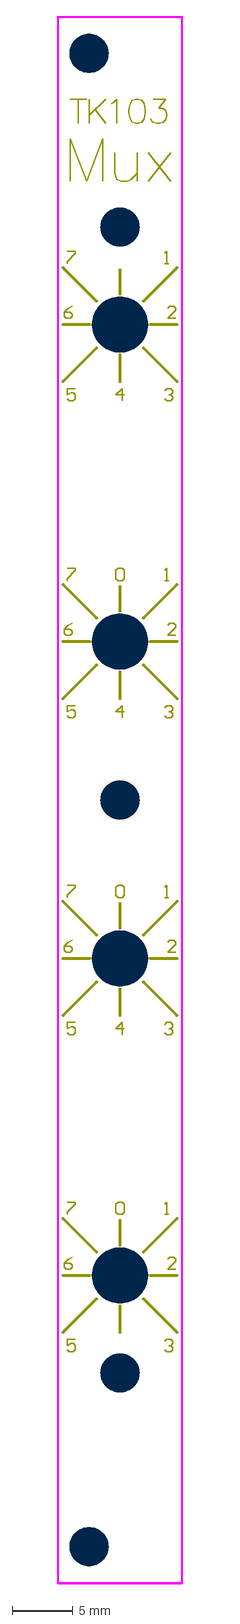
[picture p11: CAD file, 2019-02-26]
05_Hardware/TK100_Tonegenerator/TK103_Multiplexer/Project Outputs/TK103_Multiplexer_frontpanel.DXF
10.3 x 128.6 mm

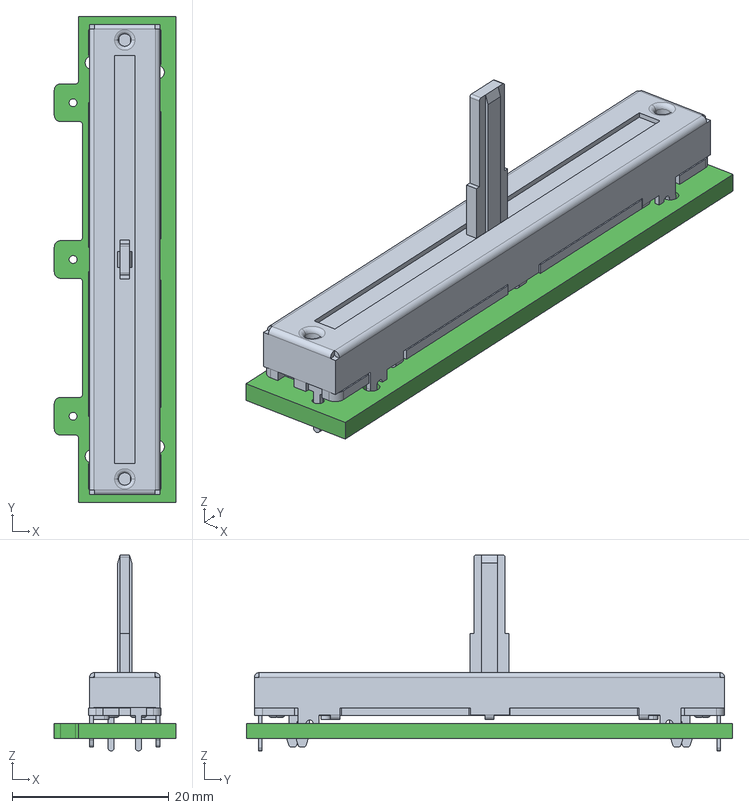
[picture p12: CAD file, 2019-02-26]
05_Hardware/TK100_Tonegenerator/TK104_Pulsbegrenser_Eurorack/TK104_Pulsbegrenser_Eurorack_faderboard.step
15.5 x 62.0 x 25.0 mm
Board
User_Library-pta4543-2x15cpxxxx

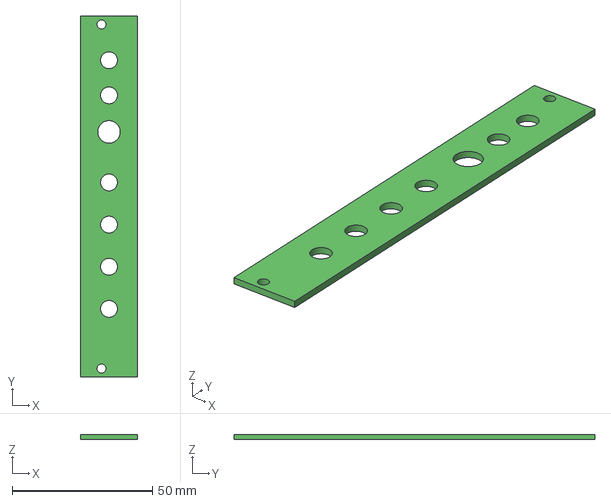
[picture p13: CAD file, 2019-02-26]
05_Hardware/TK100_Tonegenerator/TK105_Hodetelefonforsterker/TK105_Frontpanel.step
20.3 x 128.5 x 1.89 mm

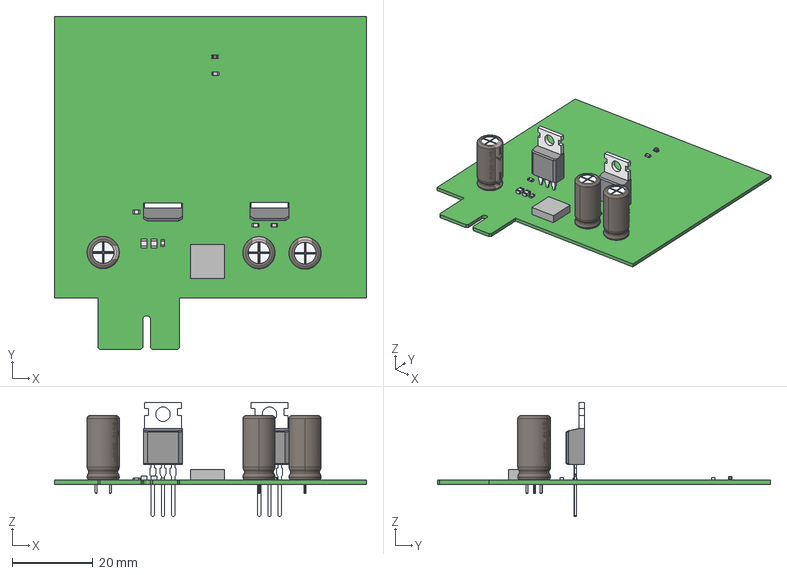
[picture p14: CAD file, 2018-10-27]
05_Hardware/TK500_Driver/TK516_LINREG-PSU/Project Outputs/TK516_LINREG-PSU.step
77.5 x 82.8 x 28.4 mm
Board
Extruded x 22
User_Library-LTST-C190EKT_Pad
User_Library-LTST-C190EKT_Pad005
User_Library-LTST-C190EKT_Pad001
User_Library-LTST-C190EKT_Pad004
User_Library-LTST-C190EKT_Pad003
User_Library-LTST-C190EKT_Lens
User_Library-Cap-EL(8x16-3_5) x 3
User_Library-POWER_MOSFET__NON-SURFACE-MOUNT x 2

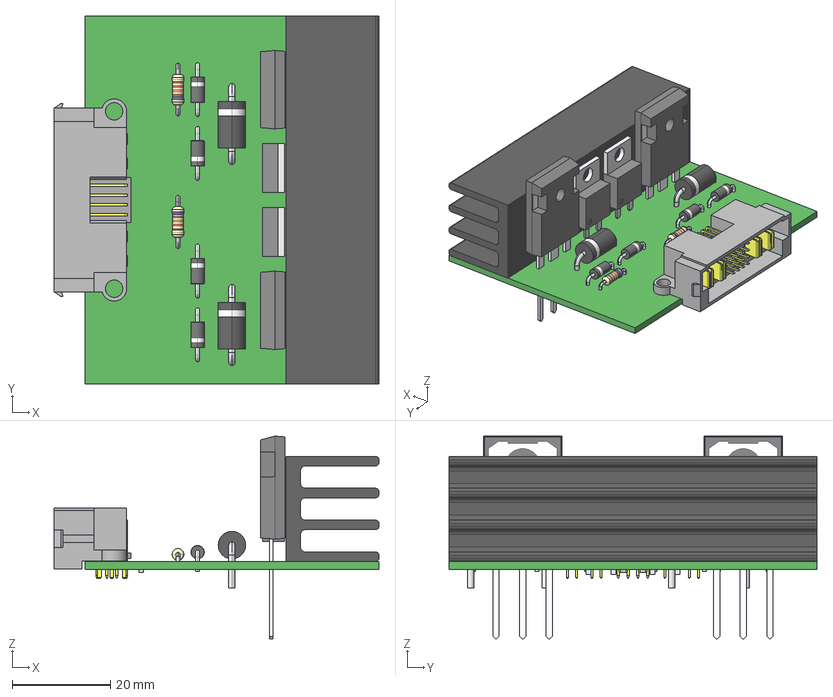
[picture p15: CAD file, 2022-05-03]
05_Hardware/TK500_Driver/TK531_Utgangstrinn/Project Outputs/ExportSTEP/TK531_Utgangstrinn.step
66.3 x 75.0 x 41.4 mm
Extruded x 6
User_Library-TO220-2_V-S_Fusion x 2
User_Library-TO220-2_V-S_TO220_3_V_S004 x 2
User_Library-AXIAL_RESISTOR(0_25W) x 2
User_Library-DO-201AD_Cylinder x 2
User_Library-DO-201AD_Cylinder001 x 2
User_Library-DO-201AD_Cylinder002 x 2
User_Library-DO-201AD_Cylinder003 x 2
User_Library-DO-201AD_Torus x 2
User_Library-DO-201AD_Cylinder004 x 2
User_Library-DO-201AD_Torus001 x 2
User_Library-DO-201AD_Cylinder005 x 2
User_Library-DO-201AD_Cylinder006 x 2
User_Library-TO-247_CASE_340L-02_Vertical_1 x 2
User_Library-TO-247_CASE_340L-02_Vertical_2 x 2
User_Library-TO-247_CASE_340L-02_Vertical_3 x 2
User_Library-TO-247_CASE_340L-02_Vertical_4 x 2
User_Library-DO-41-2 x 4
_MPTC_02_16_02_01_RA_SD_t_2
_MPTC_02_16_02_01_03_L_RA_p_4
_MPTC_16_plate_6
_MPTC_03_RA_pp_8 x 4
SK-454-75-SA

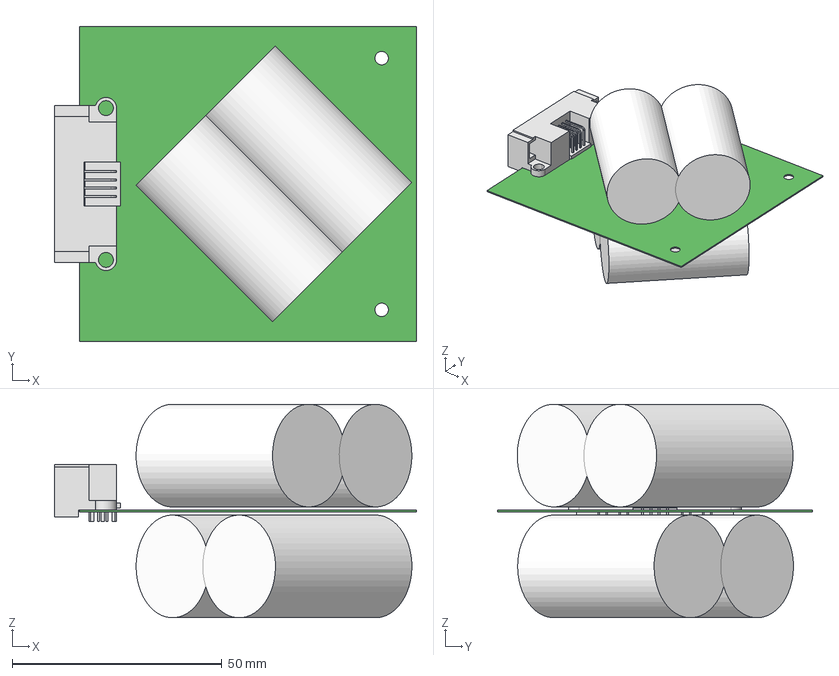
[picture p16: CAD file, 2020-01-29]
05_Hardware/TK500_Driver/TK532_Kondensatorkort/Project Outputs/ExportSTEP/TK532_Kondensatorkort.step
86.3 x 75.0 x 50.9 mm
Board
Samtec-MPTC-02-16-02-01-01-L-RA-SD

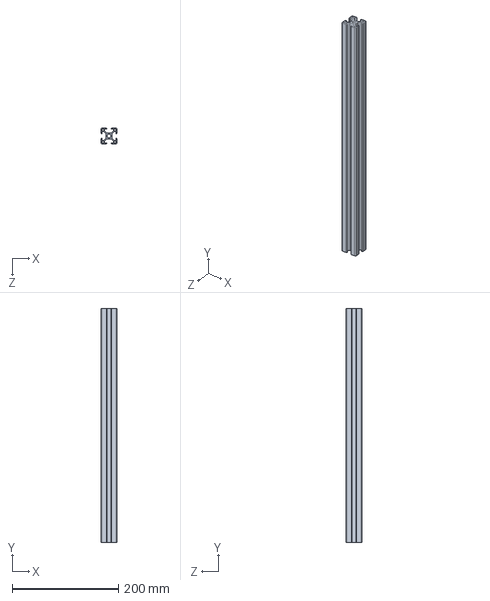
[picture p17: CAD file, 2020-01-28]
06_Mechanical/3030_Profile.SLDPRT
30.0 x 440.0 x 30.0 mm

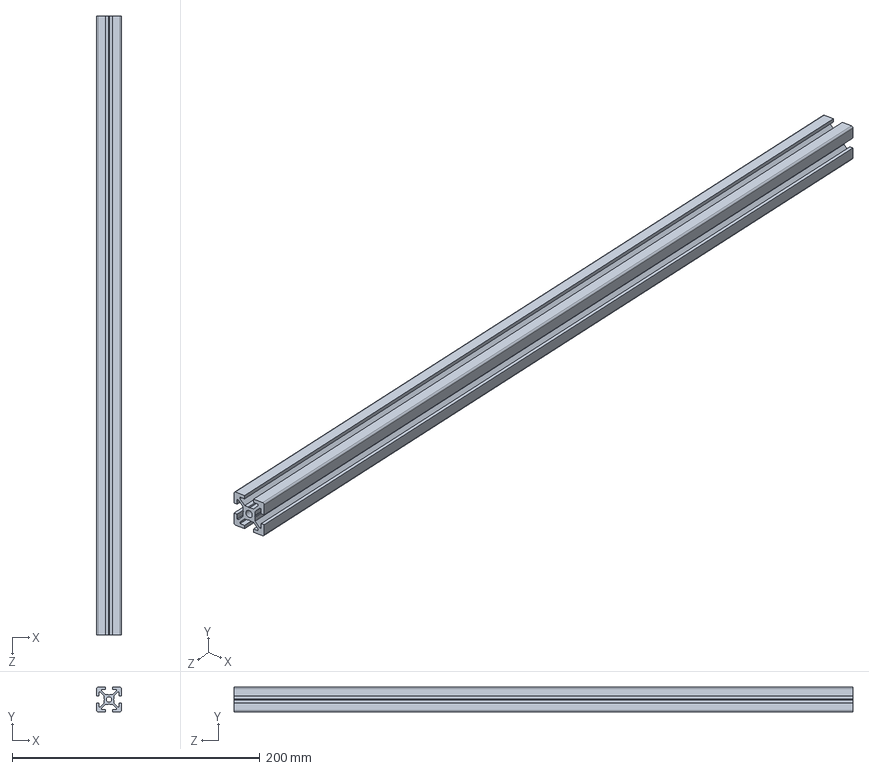
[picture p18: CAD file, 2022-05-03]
06_Mechanical/TK500_Driver/HFS5-2020-500.sldprt
20.0 x 20.0 x 500.0 mm

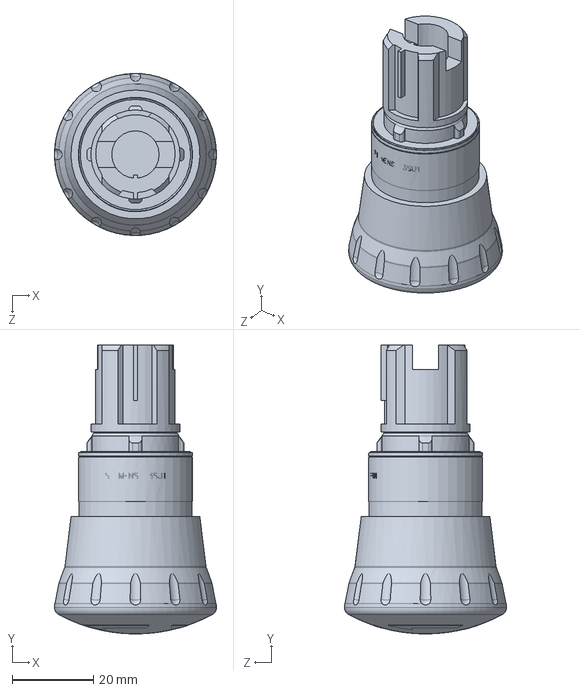
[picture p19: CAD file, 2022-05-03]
06_Mechanical/TK500_Driver/Siemens/3SU1000-1HB20-0AA0.SLDPRT
40.0 x 71.3 x 40.0 mm

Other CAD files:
06_Mechanical/TK500_Driver/Siemens/3SU1000-0AB20-0AA0.SLDASM
05_Hardware/TK1000_Spolerigg/Spolekasse/Kortende.SLDPRT
05_Hardware/TK500_Driver/TK510_Signalbakplan/Project Outputs/AutoCAD PCB/TK510_Signalbakplan.DWG
05_Hardware/TK500_Driver/TK510_Signalbakplan/Project Outputs/TK510.dwg
05_Hardware/TK500_Driver/TK530_Kraftbakplan/Project Outputs/TK530.dwg
06_Mechanical/TK100_Tonegenerator/3U-2HP_Blind.SLDPRT
05_Hardware/TK1000_Spolerigg/Spolekasse/Kortende.DXF
05_Hardware/TK1000_Spolerigg/Spolekasse/Spoleholder.DXF
05_Hardware/TK1000_Spolerigg/Spolekasse/Spoleholder.SLDPRT
05_Hardware/TK100_Tonegenerator/TK104_Pulsbegrenser_Eurorack/19885.stp
05_Hardware/TK100_Tonegenerator/TK104_Pulsbegrenser_Eurorack/PTA4543-PANEL.DWG
05_Hardware/TK100_Tonegenerator/TK104_Pulsbegrenser_Eurorack/PTA4543-PANEL.DXF
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

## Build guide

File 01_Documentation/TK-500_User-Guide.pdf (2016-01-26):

# TK500 Teslacoildriver

# Features

## - Input voltage 230VAC - 160VDC output - Optical input (Toslink connector)

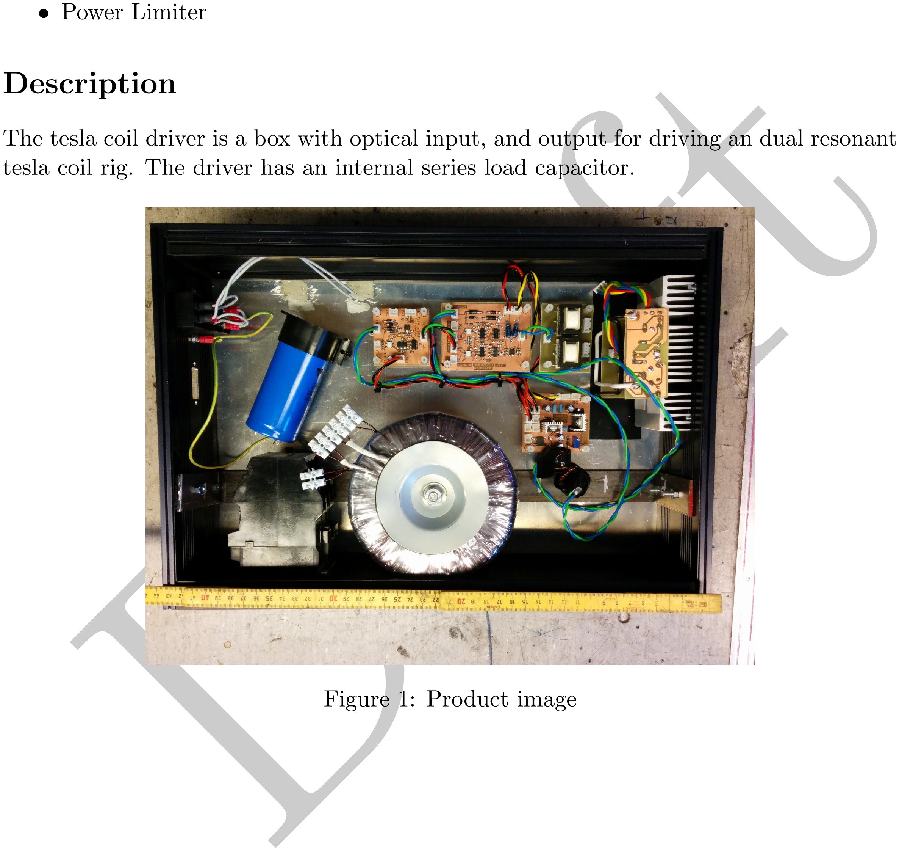
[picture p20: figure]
Draft; • Power Limiter; Description; Figure 1: Product image

The tesla coil driver is a box with optical input, and output for driving an dual resonant tesla coil rig. The driver has an internal series load capacitor.

## Teslakom 2014 Omega Verksted

# Draft

## TK500 User Guide

# Contents

1 Connections | 3
2 Powersupplies | 5
3 Schematics | 6

## page 2

# Draft

## TK500 User Guide

# 1 Connections

Table 1 contains an overview of the available connections on the controller card.

Designator | Connector name | Description
J500XX | AC in | Connector for 230V in.
J500XX | Tesla out 2 | Connector for connecting coil rig.
J500XX | Optical | Connector for input control signal.

## Table 1: Connections on controller card

# 1.1 Optical interface

The tesla coil driver has a optical connector (TOSLINK) for the input control signal.

The input control signal should be pulse width modulated (PWM) with a 2MHz carrier wave. The signal should have an maximal pulse width (high) of 680µS. The tesla coil fires as long as the control signal is active. To adjust the length of the spark the pulse width can be adjusted. Shorter pulse width equals shorter spark. See fig. 2 for a graphical representation. In the figure ’CW’ is the clock signal, ’Control Signal’ is the control signal, and ’PWM’ is the signal on the optical cable. Note that the aspects and pulse widths are not exact. A pulse widht of 80% for active and 10% for inactive should

be sufficent.

## CW (2MHz)

## Control Signal

## PWM

## Figure 2: Control signal timing diagram

# 1.2 Tesla out

## The tesla out connector connects to the coil rig. The coil rig schematic is shown in

fig. 3. C1 is physically small and contained inside the driver enclosure. L1 is physically large and encloses L2 with a large air gap in between. L2 is physically large and contains

significantly more windings than L1 (typ. 1000 times more). C2 is a capacitor consisting of the top load, and the enviroment around the top load. One plate can i.e. be a steel sphere, and the other plate can be the walls, roof, and floor of the room. Or something closer like a chain mail glove. The relationships between C1, L1, L2, C2 is given by

eq. (1) and eq. (1). f0 should be around 120kHz.

f0 =

1
√
L1 · C1

(1)

f0 =

1
√
L2 · C2

(2)

## page 3 of 25

## TK500 User Guide

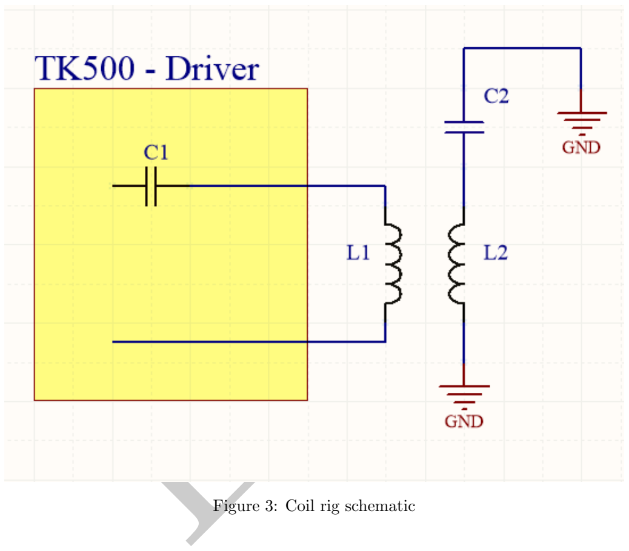
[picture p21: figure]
Draft; Figure 3: Coil rig schematic

## page 4 of 25

# Draft

## TK500 User Guide

# 2 Powersupplies

2.1 5V

## page 5 of 25

# Draft

## TK500 User Guide

# 3 Schematics

This page is intentionally left (almost) blank.

## page 6 of 25

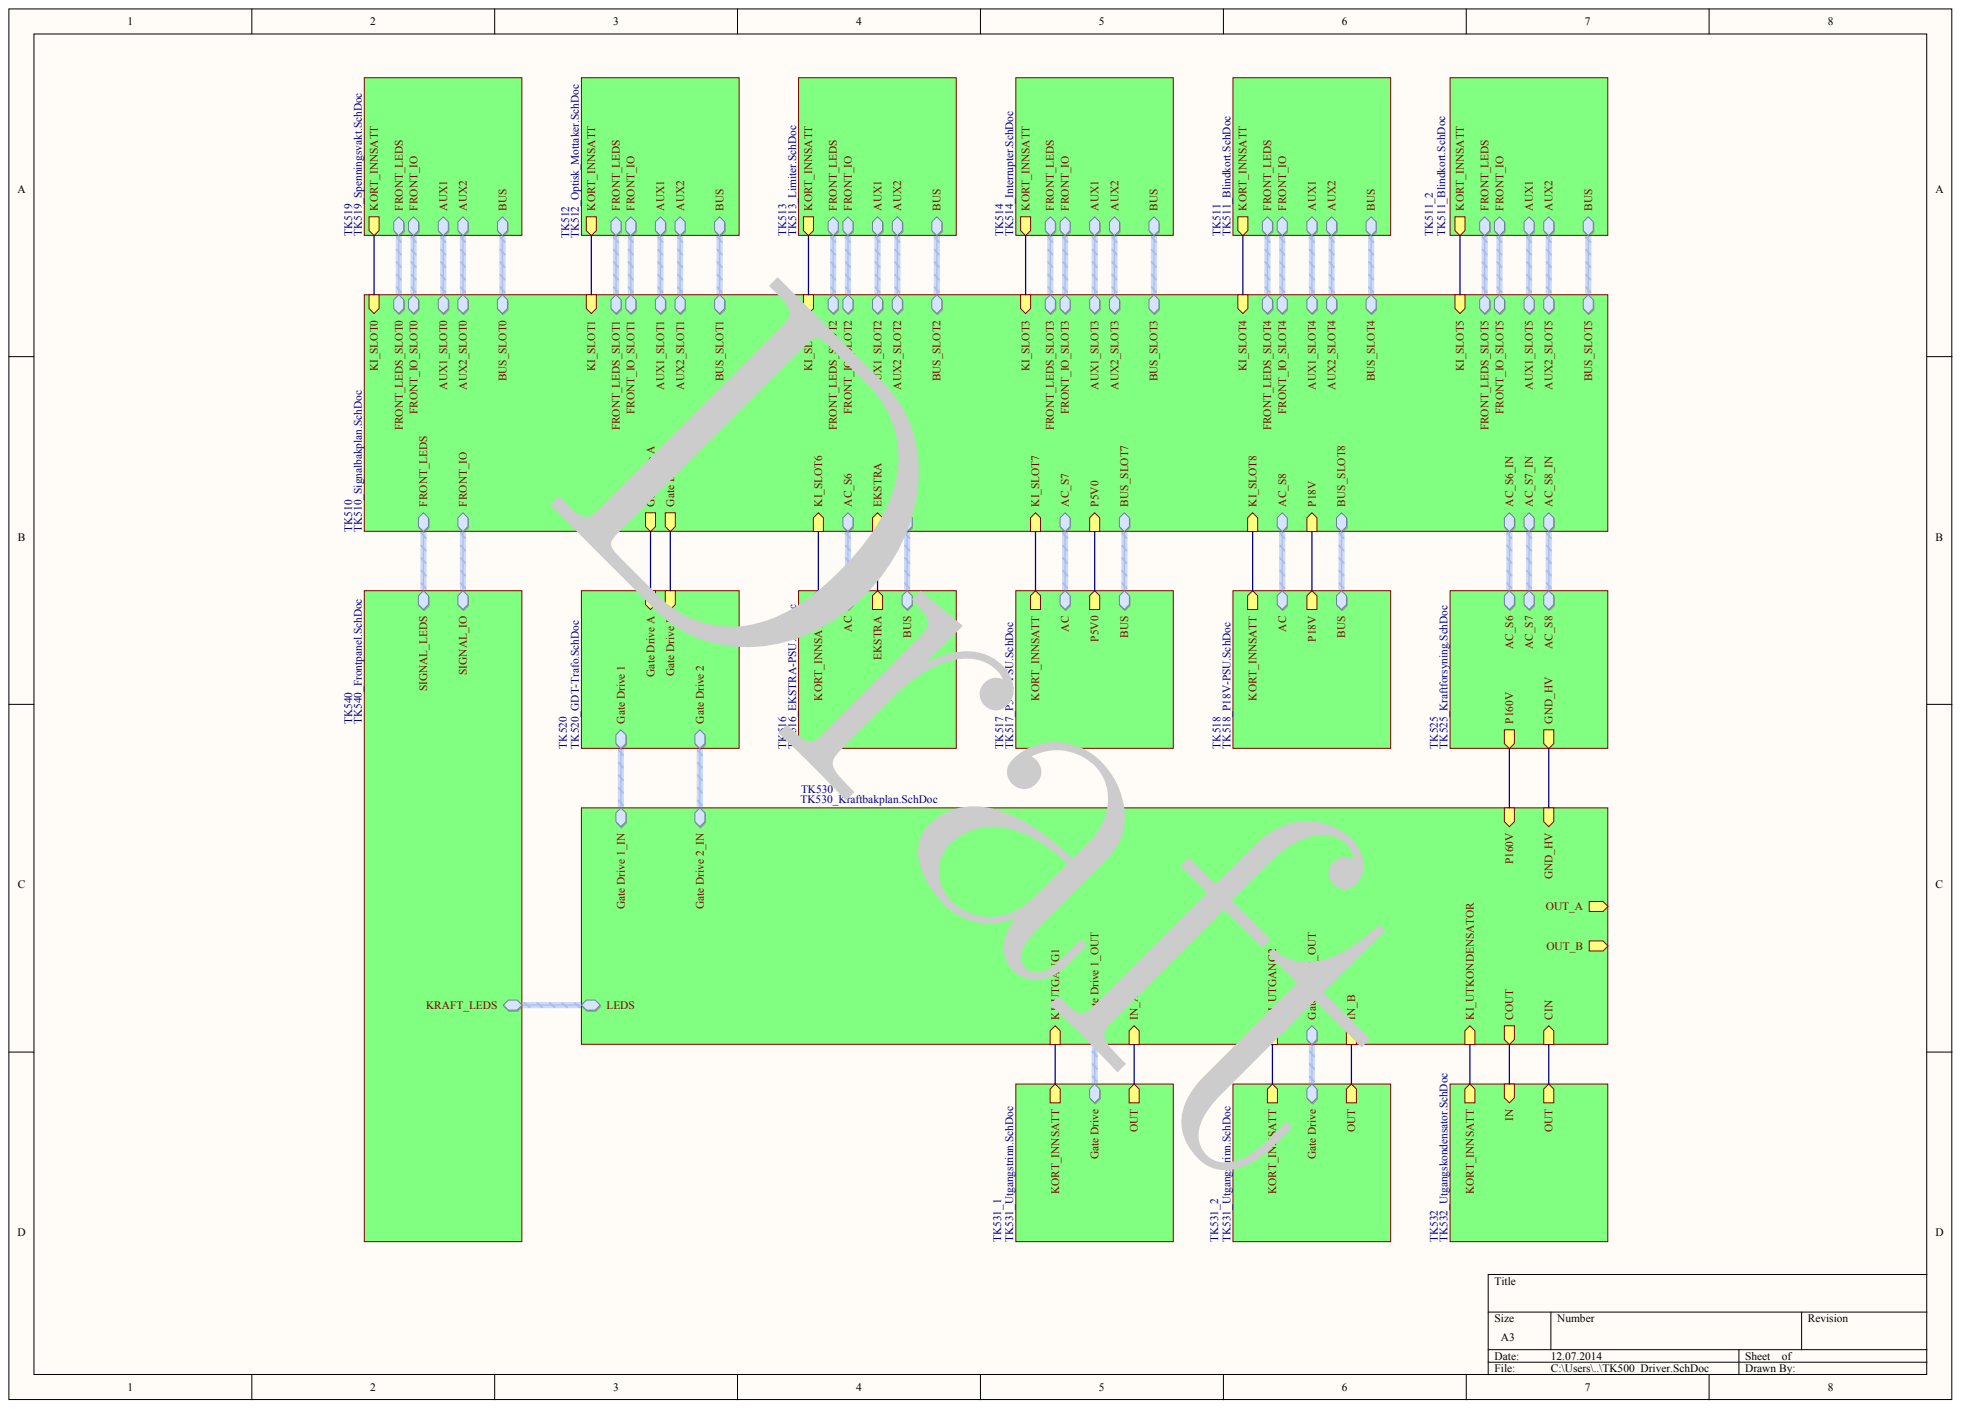
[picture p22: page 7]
Title; Size; Number; Revision; Date:; Sheet of; File:; C:\Users\..\TK500_Driver.SchDoc; Drawn By:; FRONT_LEDS_SLOT0; AUX2_SLOT0; AUX1_SLOT0; FRONT_IO_SLOT0; BUS_SLOT0; FRONT_LEDS_SLOT1; AUX2_SLOT1; AUX1_SLOT1; FRONT_IO_SLOT1; BUS_SLOT1; FRONT_LEDS_SLOT2; AUX2_SLOT2; AUX1_SLOT2; FRONT_IO_SLOT2; BUS_SLOT2; FRONT_LEDS_SLOT3; AUX2_SLOT3; AUX1_SLOT3; FRONT_IO_SLOT3; BUS_SLOT3; FRONT_LEDS_SLOT4; AUX2_SLOT4; AUX1_SLOT4; FRONT_IO_SLOT4; BUS_SLOT4; FRONT_LEDS_SLOT5; AUX2_SLOT5; AUX1_SLOT5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

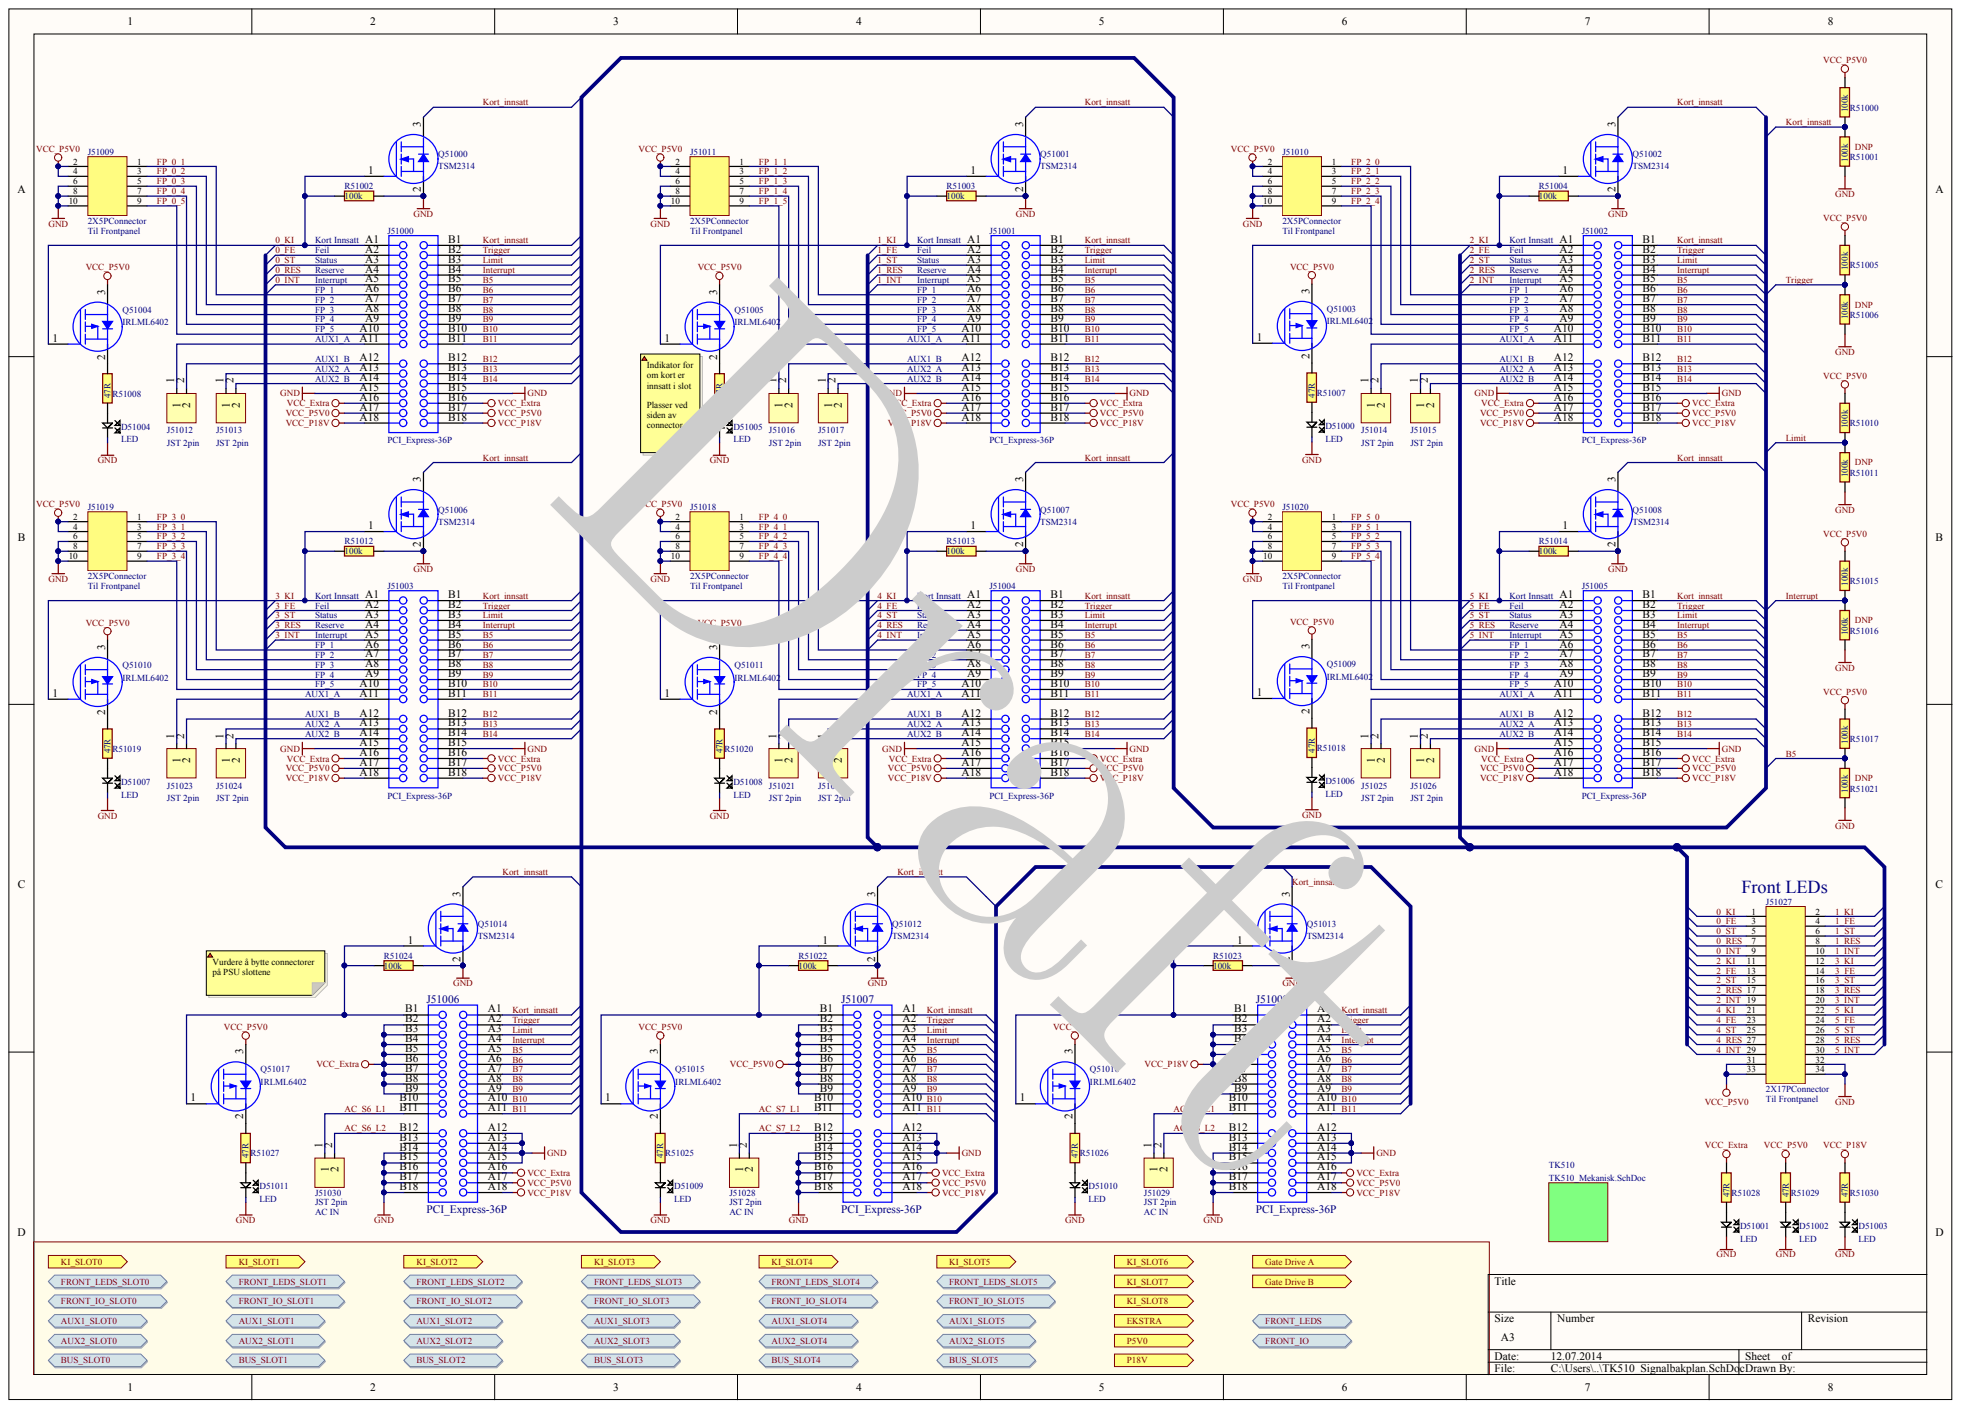
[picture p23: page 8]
Title; Size; Number; Revision; File:; C:\Users\..\TK510_Signalbakplan.SchDocDrawn By:; LED; VCC_P5V0; VCC_P18V; GND; FRONT_IO; KI_SLOT6; KI_SLOT7; FRONT_LEDS; Gate Drive B; EKSTRA; Gate Drive A; KI_SLOT8; PCI_Express-36P; VCC_Extra; BUS_SLOT0; FRONT_IO_SLOT5; BUS_SLOT1; BUS_SLOT3; FRONT_LEDS_SLOT0; AUX2_SLOT0; AUX2_SLOT2; FRONT_LEDS_SLOT3; KI_SLOT1; AUX2_SLOT4; FRONT_IO_SLOT4; AUX1_SLOT5; AUX2_SLOT5; FRONT_IO_SLOT0; KI_SLOT2; FRONT_IO_SLOT1; FRONT_LEDS_SLOT1; FRONT_LEDS_SLOT2; AUX1_SLOT1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

Indikator for
om kort er
innsatt i slot

Vurdere å bytte connectorer
på PSU slottene

D | D
C | C
B | B
A | A

Title

Size | Number | Revision

A3

File: | C:\Users\..\TK510_Mekanisk.SchDoc | Drawn By:

M1

CardHolder

M2

CardHolder

M3

CardHolder

M4

CardHolder

M14

CardHolder

M15

CardHolder

M10

CardHolder

M11

CardHolder

M12

CardHolder

M13

CardHolder

M17

CardHolder

M8

CardHolder

M5

CardHolder

M6

CardHolder

M7

CardHolder

M9

CardHolder

M18

CardHolder

M16

CardHolder

COM1 | COM2 | COM3 | COM4 | COM5 | COM6 | COM7 | COM8 | COM9
COM10 | COM11 | COM12 | COM13 | COM14 | COM15 | COM16 | COM17 | COM18

# Draft

### POA8

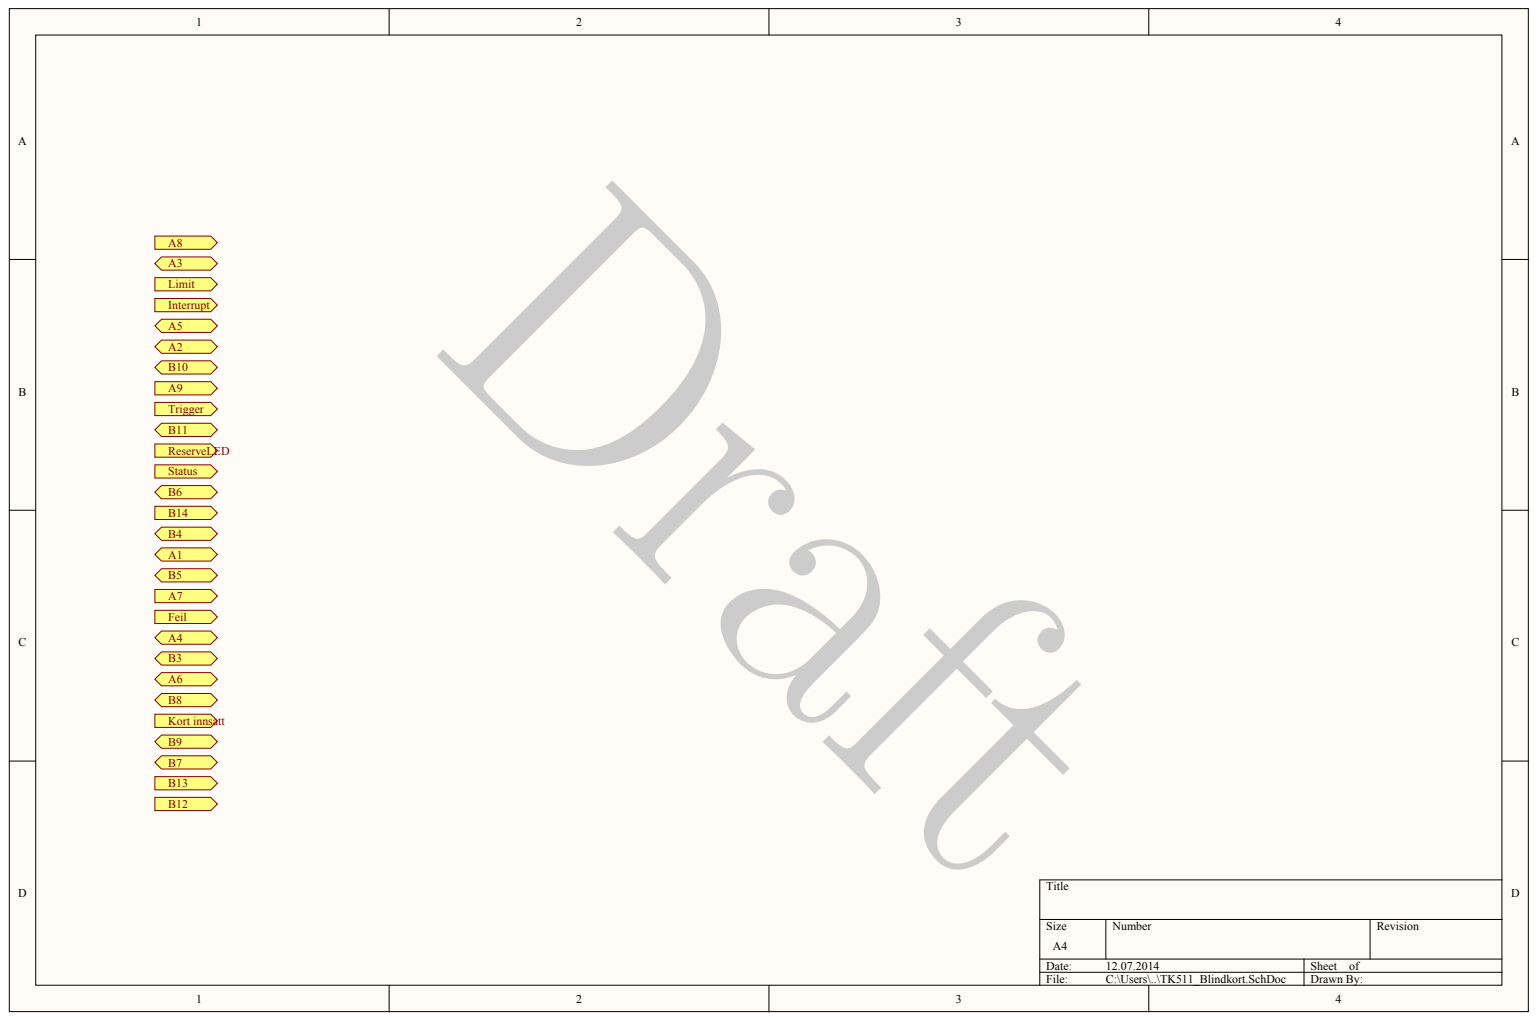
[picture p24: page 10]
Title; Size; Number; Revision; File:; C:\Users\..\TK511_Blindkort.SchDoc; Drawn By:; Kort innsatt; Feil; Status; ReserveLED; Trigger; Interrupt; Limit; POA1; POA2; POA3; POA4; POA5; POA6; POA7; POA9; POB3; POB4; POB5; POB6; POB7; POB8; POB9; POB10; POB11; POB12; POB13; POB14; POFEIL; POINTERRUPT; POKORT INNSATT; POLIMIT; PORESERVELED POSTATUS; POTRIGGER; Draft

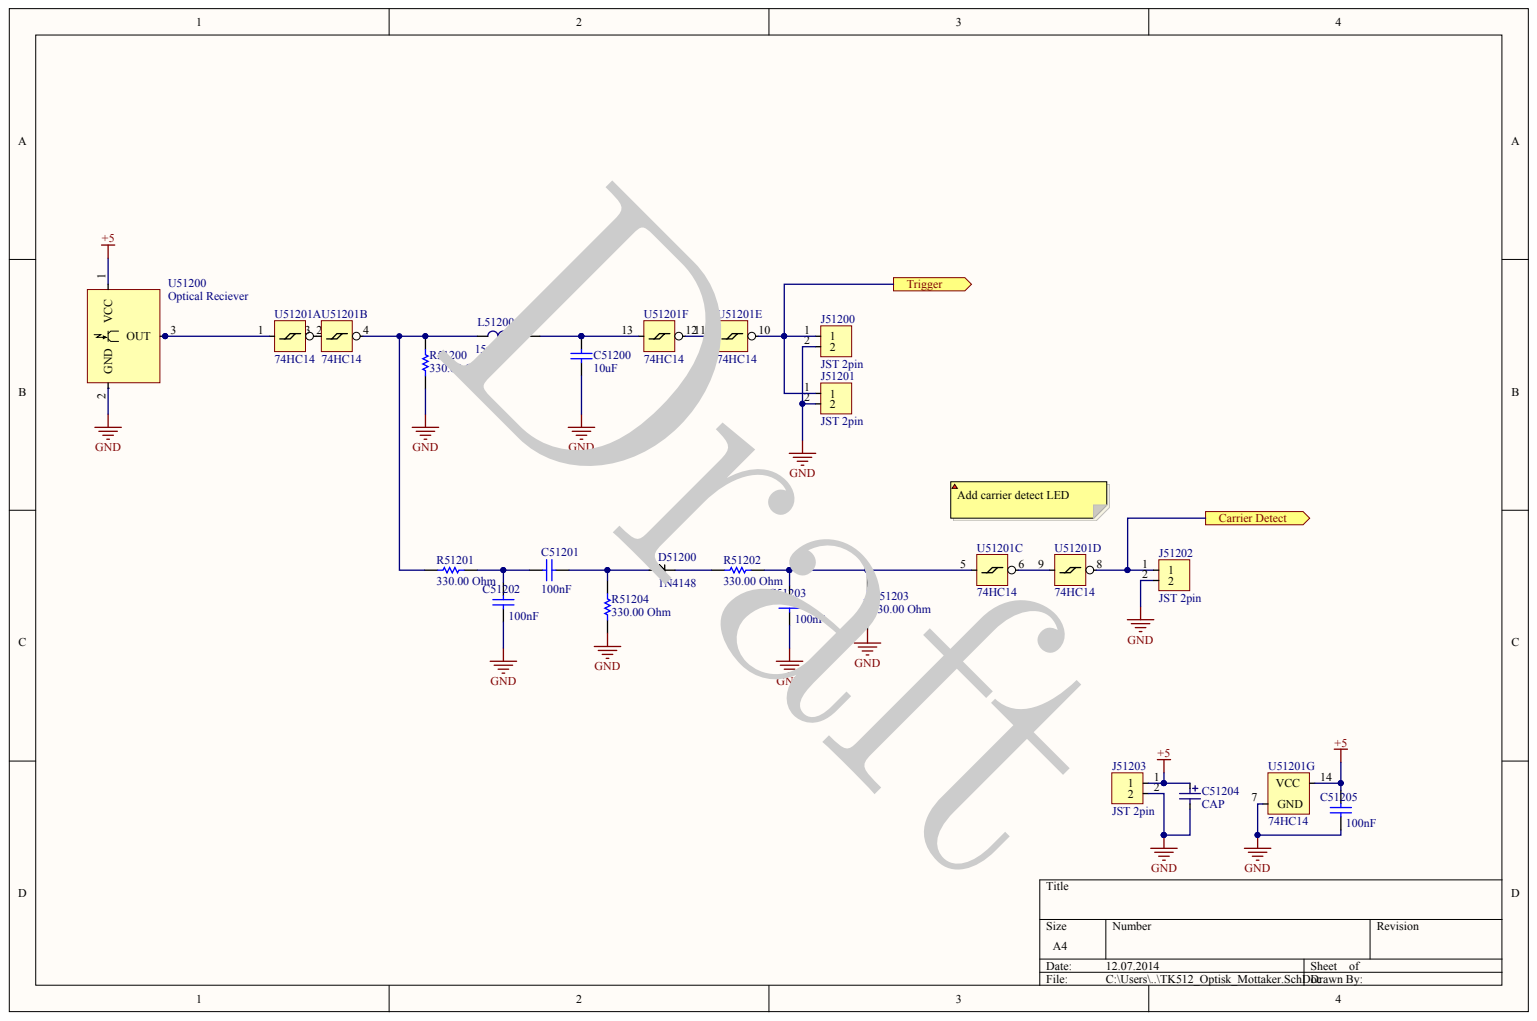
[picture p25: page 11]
Title; Size; Number; Revision; File:; C:\Users\..\TK512_Optisk_Mottaker.SchDocDrawn By:; 330.00 Ohm; GND 7; VCC; GND; C51204 CAP; JST 2pin; GND 2 VCC 1; OUT; U51200 Optical Reciever; Trigger; Carrier Detect; Draft

Add carrier detect LED

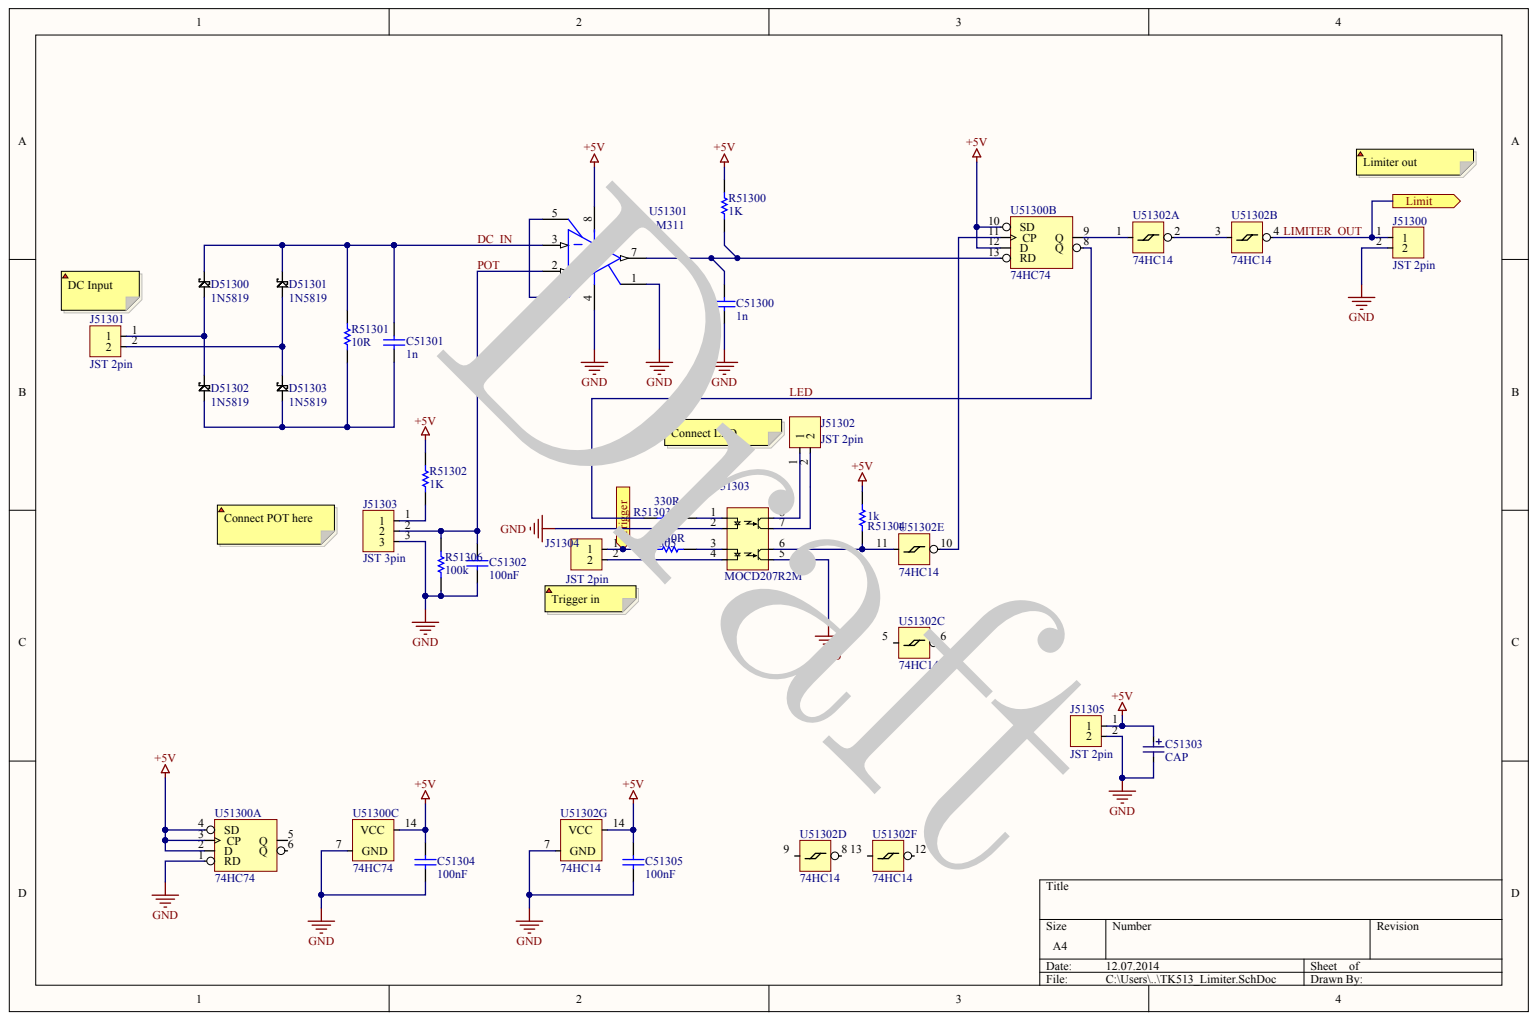
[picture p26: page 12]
Title; Size; Number; Revision; File:; C:\Users\..\TK513_Limiter.SchDoc; Drawn By:; JST 2pin; GND; JST 3pin; GND 7; VCC; MOCD207R2M; J51302 JST 2pin; POT; LIMITER_OUT; LED; C51303 CAP; Limit; Trigger; Connect LED; Trigger in; Limiter out; DC Input; Draft

Connect POT here

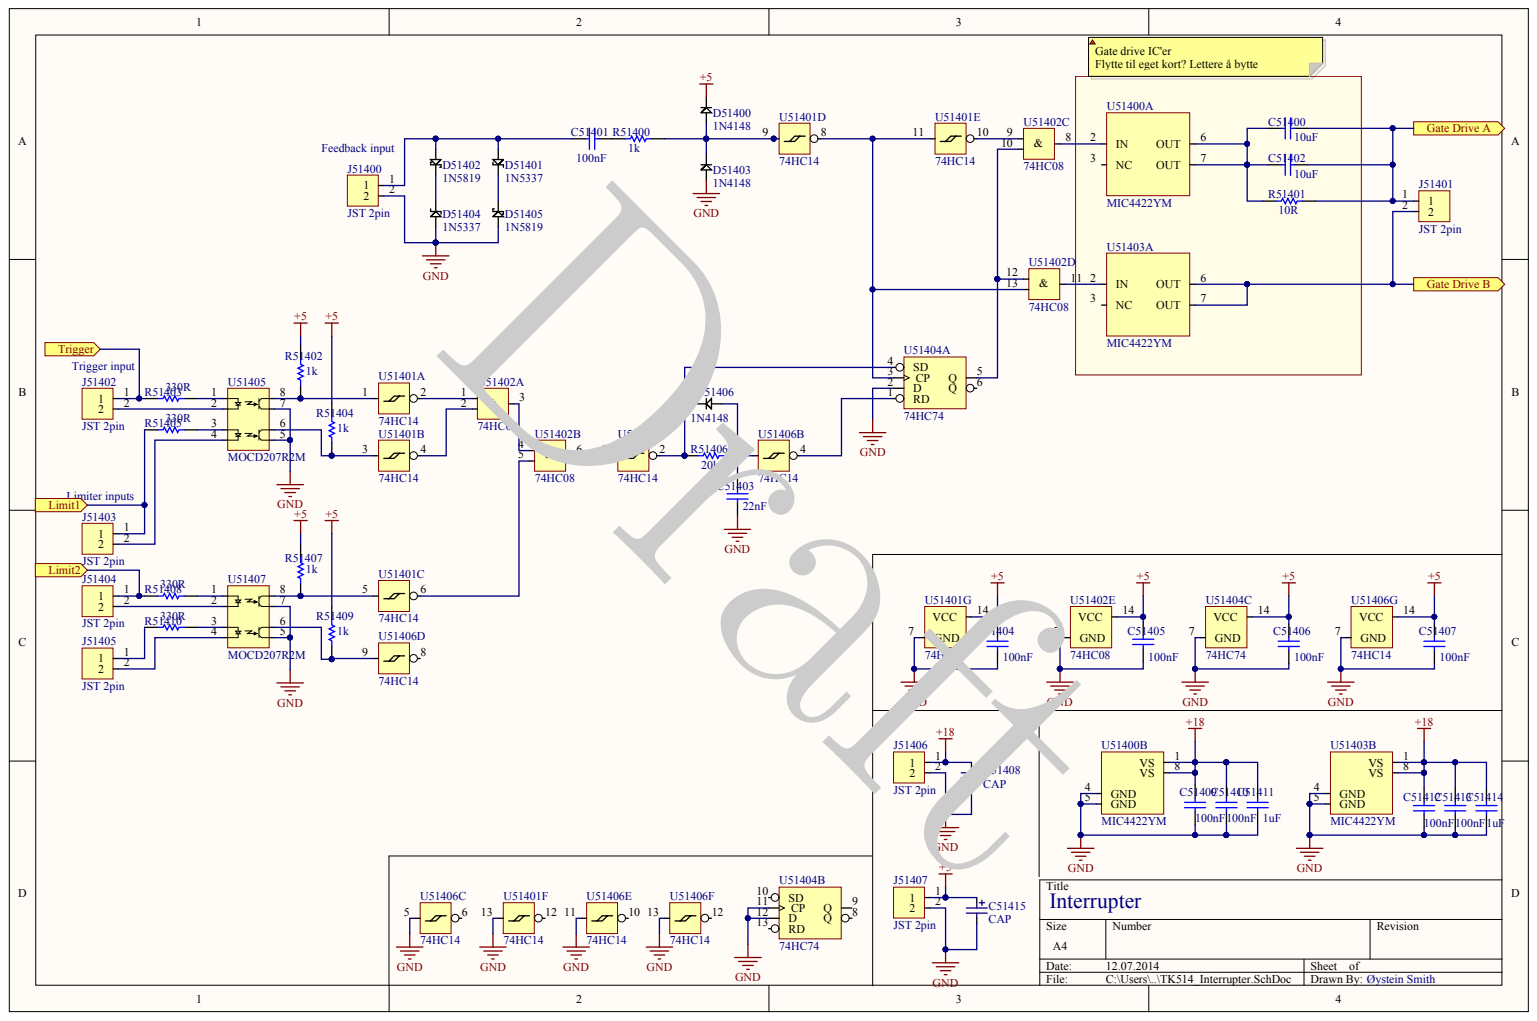
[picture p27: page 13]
Title; Size; Number; Revision; File:; C:\Users\..\TK514_Interrupter.SchDoc; Drawn By:; GND 7; VCC; JST 2pin; GND; MOCD207R2M; OUT; MIC4422YM; GND 5; GND 4; Feedback input; Trigger input; Limiter inputs; Interrupter; Øystein Smith; C51408 CAP; C51415 CAP; Limit1; Limit2; Trigger; Gate Drive A; Gate Drive B; Draft

Gate drive IC'er
Flytte til eget kort? Lettere å bytte

D | D
C | C
B | B
A | A

Title

Size | Number | Revision

A4

File: | C:\Users\..\TK516_EKSTRA-PSU.SchDocDrawn By:

# Draft

D | D
C | C
B | B
A | A

Title

Size | Number | Revision

A4

File: | C:\Users\..\TK517_P5V0-PSU.SchDoc | Drawn By:

# Draft

D | D
C | C
B | B
A | A

Title

Size | Number | Revision

A4

File: | C:\Users\..\TK518_P18V-PSU.SchDoc | Drawn By:

# Draft

D | D
C | C
B | B
A | A

Title

Size | Number | Revision

A4

File: | C:\Users\..\TK519_Spenningsvakt.SchDocDrawn By:

# Draft

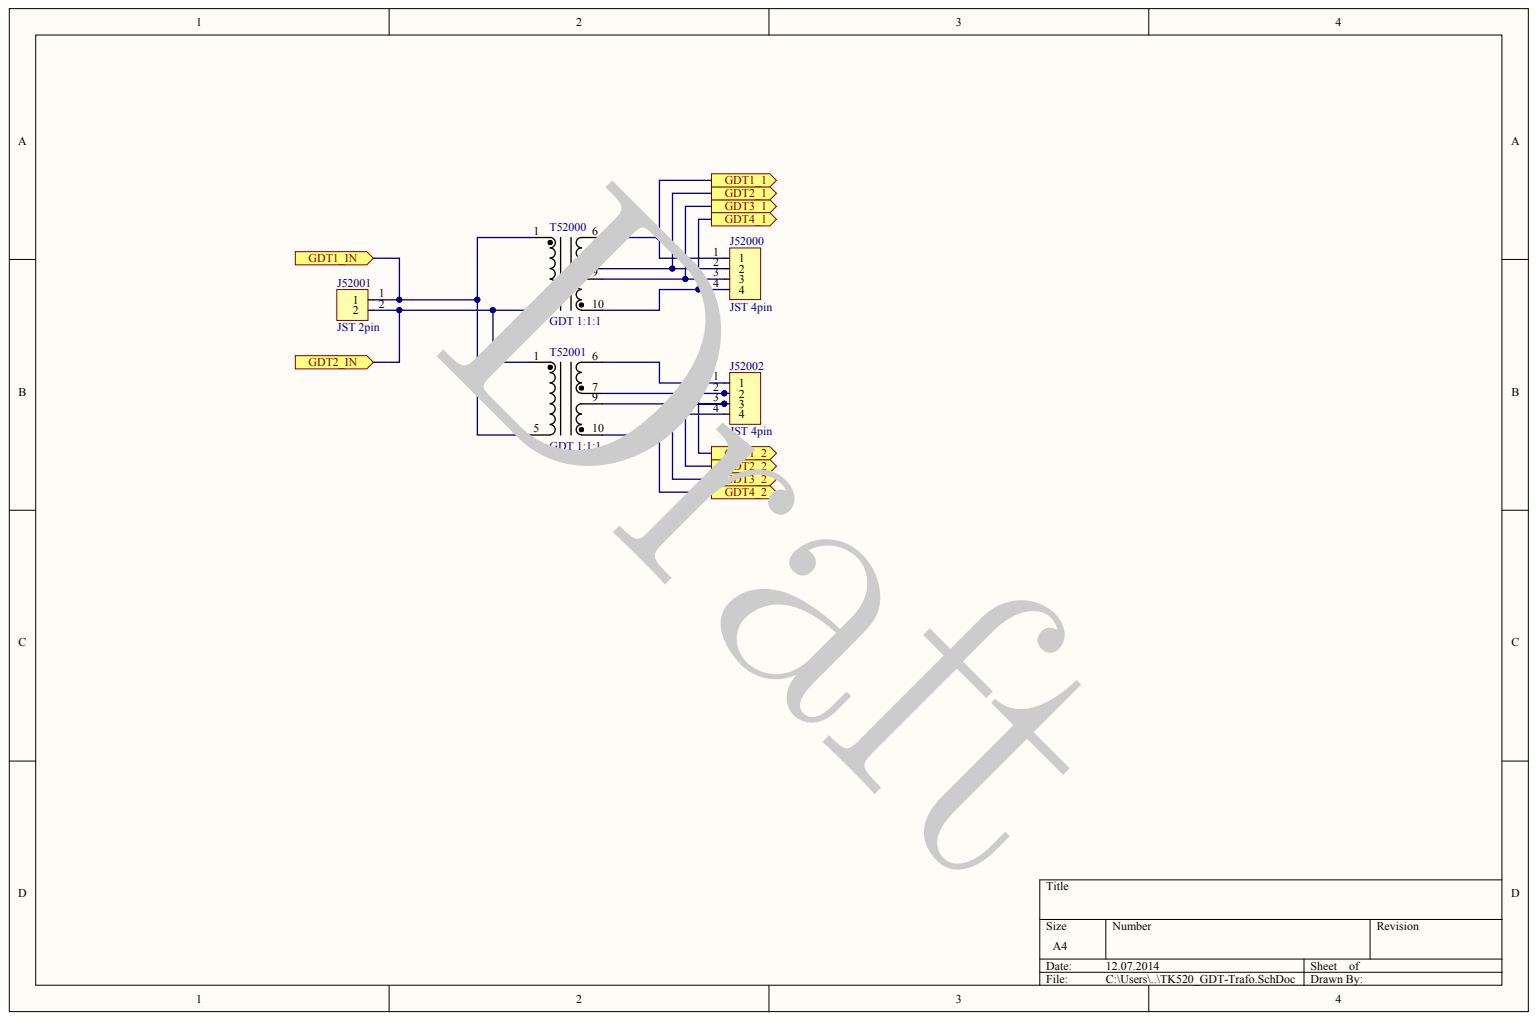
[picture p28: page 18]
Title; Size; Number; Revision; File:; C:\Users\..\TK520_GDT-Trafo.SchDoc; Drawn By:; JST 2pin; JST 4pin; GDT 1:1:1; GDT4_2; GDT3_2; GDT1_IN; GDT2_IN; GDT2_2; GDT3_1; GDT2_1; GDT1_2; GDT4_1; GDT1_1; Draft

D | D
C | C
B | B
A | A

Title

Size | Number | Revision

A4

File: | C:\Users\..\TK525_Kraftforsyning.SchDocDrawn By:

# Draft

### POGDT101

### POGDT102

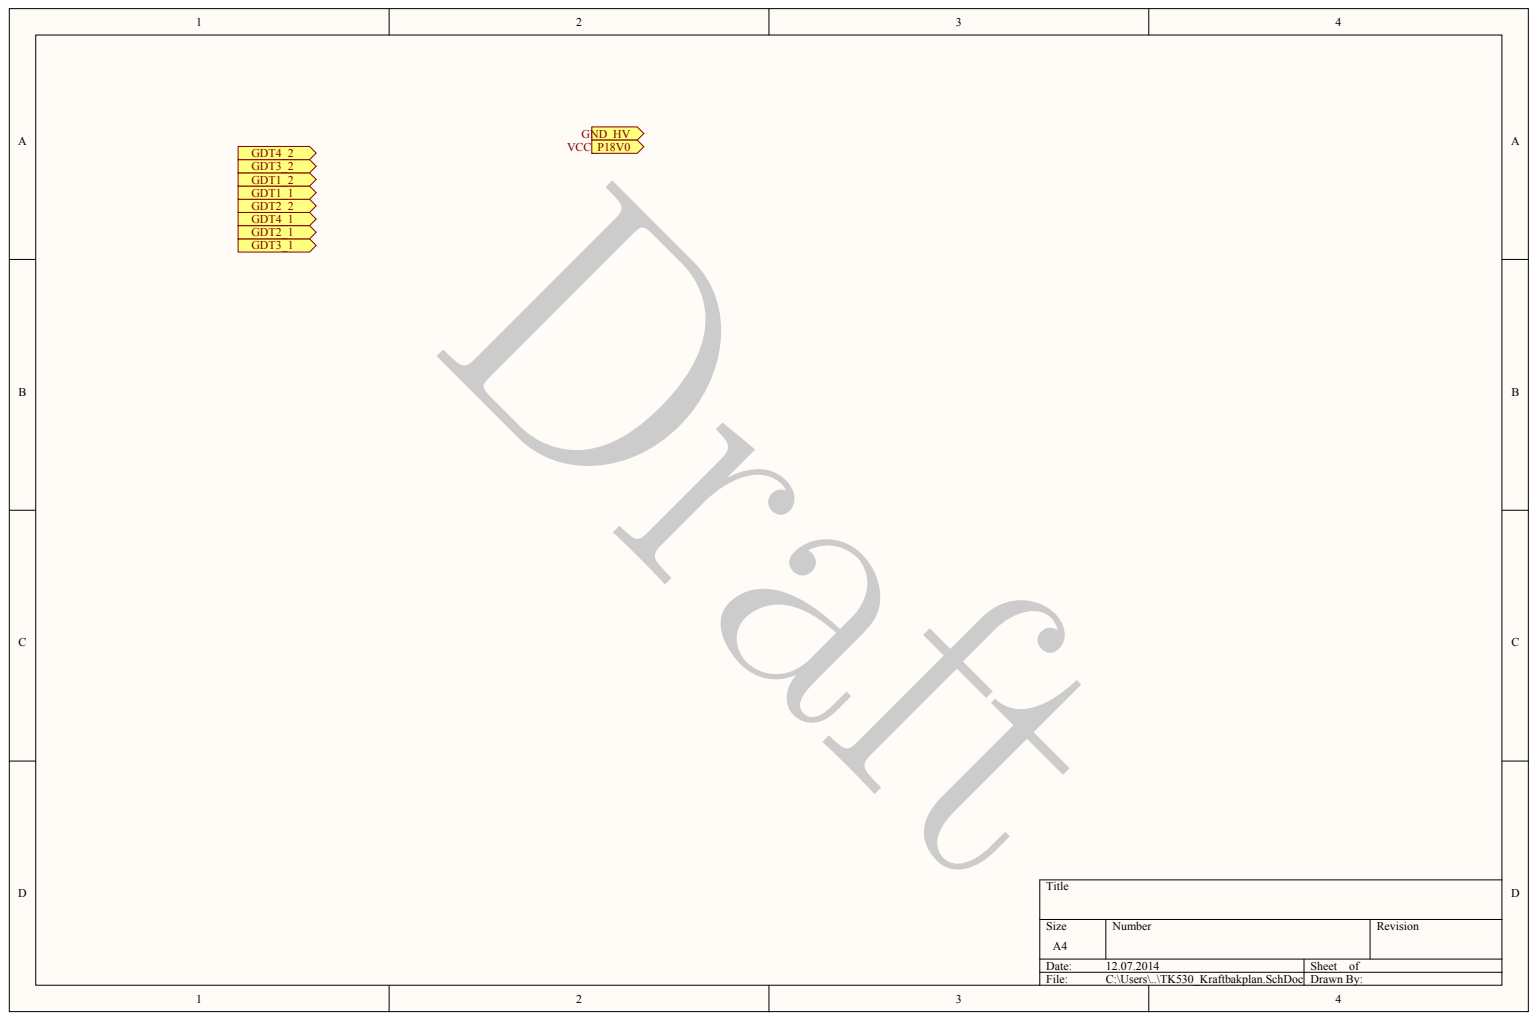
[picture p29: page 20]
Title; Size; Number; Revision; File:; C:\Users\..\TK530_Kraftbakplan.SchDoc; Drawn By:; GDT3_1; GDT2_1; GDT4_1; GDT2_2; GDT1_1; GDT1_2; GDT3_2; GDT4_2; GND_HV VCC_P18V0; POGDT201; POGDT202; POGDT301; POGDT302; POGDT401; POGDT402; POGND0HV POVCC0P18V0 Draft

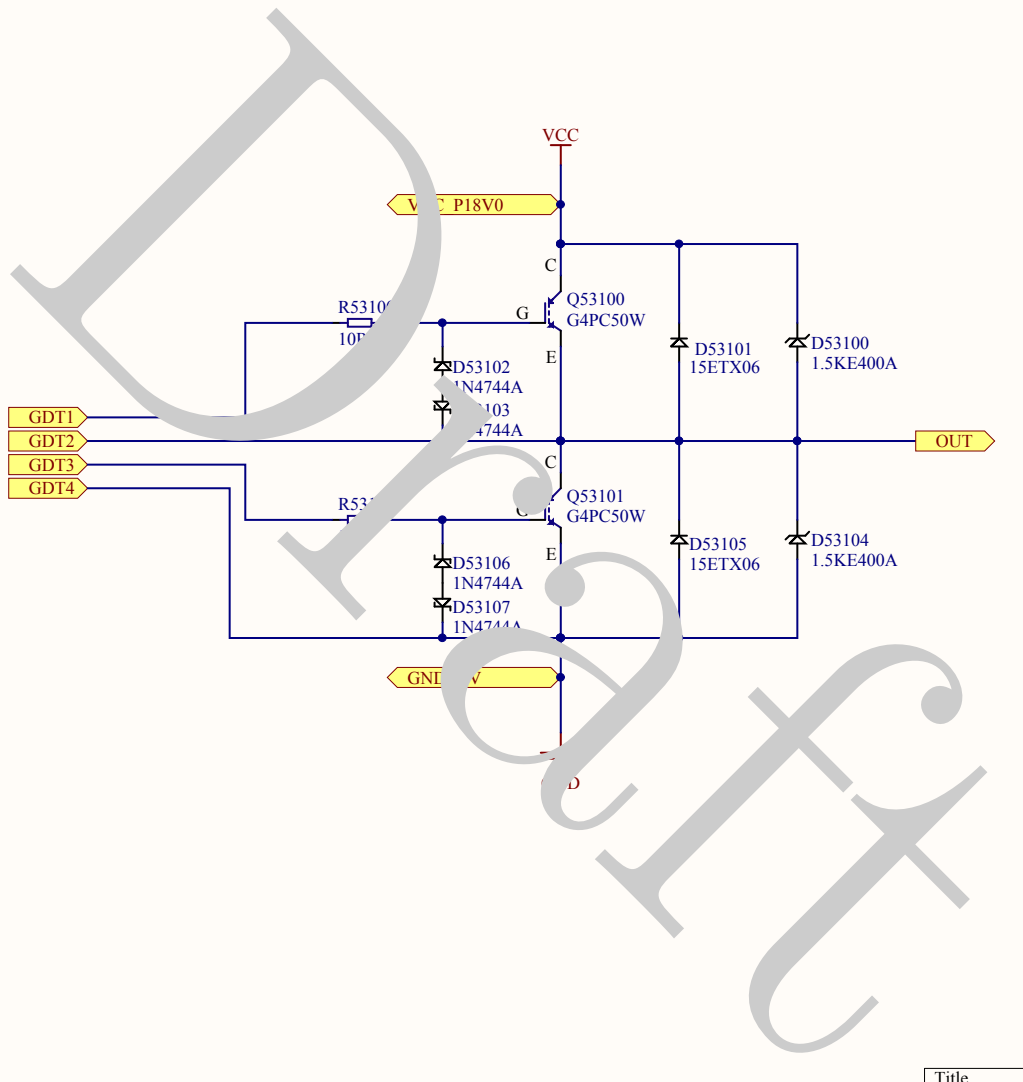
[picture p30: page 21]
Title; Size; Number; Revision; File:; C:\Users\..\TK531_Utgangstrinn.SchDoc; Drawn By:; VCC; GND; D53101 15ETX06; D53105 15ETX06; GDT4; GDT2; GDT1; GDT3; VCC_P18V0; OUT; GND_HV; Draft

D | D
C | C
B | B
A | A

Title

Size | Number | Revision

A4

File: | C:\Users\..\TK532_Utgangskondensator.SchDoc Drawn By:

# Draft

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
TK540_Frontpanel.SchDoc

12.07.2014 | 23:24:03 | 17 | 17

*

ATMEL Norway

Vestre Rosten 79

N-7075 TILLER

NORWAY

PAGE: | of

TITLE:

Document number: | Revision: A

Date:

*

*

*

# Draft

Designator | Quantity | Value | Description
C51200, C51400, C51402 | 3 10uF | | CAP 10uF 25V ±10% 1206 (3216 Metric) Thickness 1.9mm SMD C51201, C51202, C51203, C51205,
C51404, C51405, C51406, C51407, C51409, C51410, C51412, C51413 | 12 100nF | | CAP 100nF 25V ±5% 0805 (2012 Metric) Thickness 1.45mm SMD
C51204, C51303, C51408, C51415 | 4
C51300, C51301 | 2 100nF | | CAP 100nF 50V ±5% 0805 (2012 Metric) Thickness 1mm SMD
C51302, C51304, C51305 | 3 100nF | | CAP 100nF 50V ±5% 0805 (2012 Metric) Thickness 1mm SMD
C51401 | 1 100nF | | CAP 100nF 25V ±10% 0805 (2012 Metric) Thickness 1.45mm SMD
C51403 | 1 22nF | | CAP 22nF 25V ±5% 0805 (2012 Metric) Thickness 1.45mm SMD
C51411, C51414 | 2 1uF | | CAP 1uF 25V ±5% 0805 (2012 Metric) Thickness 1.45mm SMD D51000, D51001, D51002, D51003,
D51004, D51005, D51006, D51007, D51008, D51009, D51010, D51011 | 12
D51200, D51400, D51403, D51406 | 4
D51300, D51301, D51302, D51303, D51402, D51405 | 6
D51401, D51404 | 2
D53100_TK531_1, D53100_TK531_2, D53104_TK531_1, D53104_TK531_2 | 4
D53101_TK531_1, D53101_TK531_2, D53105_TK531_1, D53105_TK531_2 | 4 D53102_TK531_1, D53102_TK531_2,
D53103_TK531_1, D53103_TK531_2, D53106_TK531_1, D53106_TK531_2, D53107_TK531_1, D53107_TK531_2 | 8
J51000, J51001, J51002, J51003, J51004, J51005, J51006, J51007, J51008 | 9 | | Pitch 1.00mm, 36-Position
J51009, J51010, J51011, J51018, J51019, J51020 | 6 J51012, J51013, J51014, J51015, J51016,
J51017, J51021, J51022, J51023, J51024, J51025, J51026 | 12
J51027 | 1
J51028, J51029, J51030 | 3
J51200, J51201, J51202, J51203, J51300, J51301, J51302, J51304, J51305, J51400, J51401, J51402, J51403, J51404, J51405, J51406, J51407, J52001 | 18
J51303 | 1
J52000, J52002 | 2
L51200 | 1 15u M1, M2, M3, M4, M5, M6, M7, M8, M9,
M10, M11, M12, M13, M14, M15, M16, M17, M18 | 18 Q51000, Q51001, Q51002, Q51006,
Q51007, Q51008, Q51012, Q51013, Q51014 | 9 Q51003, Q51004, Q51005, Q51009,
Q51010, Q51011, Q51015, Q51016, Q51017 | 9
Q53100_TK531_1, Q53100_TK531_2, Q53101_TK531_1, Q53101_TK531_2 | 4 R51000, R51001, R51005, R51006,
R51010, R51011, R51015, R51016, R51017, R51021 | 10
R51002, R51003, R51004, R51012, R51013, R51014, R51022, R51023, R51024 | 9 R51007, R51008, R51009, R51018,
R51019, R51020, R51025, R51026, R51027, R51028, R51029, R51030 | 12
R51200, R51201, R51202, R51203, R51204 | 5 330.00 Ohm | | 330R 0.125W 5% 0805 (2012 Metric) SMD
R51300, R51302 | 2 1K | | 330R 0.125W 5% 0805 (2012 Metric) SMD
R51301 | 1 10R | | 330R 0.125W 5% 0805 (2012 Metric) SMD
R51303, R51305, R51405, R51408, R51410 | 5 330R | | 330R 0.125W 5% 0805 (2012 Metric) SMD

Board-to-Board Connector, PTH, Vertical,

R51304, R51402, R51404, R51407, R51409 | 5 1k | 1K 0.125W 5% 0805 (2012 Metric) SMD
R51306 | 1 100k | 330R 0.125W 5% 0805 (2012 Metric) SMD
R51400 | 1 1k | 1K 0.125W 1% 0805 (2012 Metric) SMD
R51401 | 1 10R | 10R 0.125W 5% 0805 (2012 Metric) SMD
R51403 | 1 330R | 330R 0.125W 5% 0805 (2012 Metric) SMD
R51406 | 1 20k | 20K 0.125W 1% 0805 (2012 Metric) SMD
R53100_TK531_1, R53100_TK531_2, R53101_TK531_1, R53101_TK531_2 | 4 10R
T52000, T52001 | 2
U51200 | 1
U51201, U51302, U51401, U51406 | 4
U51300, U51404 | 2
U51301 | 1
U51303, U51405, U51407 | 3
U51400, U51403 | 2
U51402 | 1

# Draft

# Draft

## TK500 User Guide

# References

## page 25 of 25

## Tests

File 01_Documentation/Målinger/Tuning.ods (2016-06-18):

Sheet: Primærspole
Karakterisering av primærspole
 | 11 | [nF] | 22 | [nF] | 30 | [nF] | 44 | [nF]
Målt | Målt | Beregnet | Målt | Beregnet | Målt | Beregnet | Målt | Beregnet | Beregnet snitt | 2,71
viklinger | f0 [kHz] | Induktans [µH] | f0 [kHz] | Induktans [µH] | f0 [kHz] | Induktans [µH] | f0 [kHz] | Induktans [µH] | Induktans [µH] | [µH/vikling] | Estimert Induktans [µH] | Estimeringsfeil[%]
2,50 |  | #DIV/0! | 415 | 6,69 |  | #DIV/0! |  | #DIV/0! | 6,69 | 2,67 | 6,77 | 1,3
3,00 |  | #DIV/0! | 391 | 7,53 |  | #DIV/0! |  | #DIV/0! | 7,53 | 2,51 | 8,13 | 7,3
3,50 |  | #DIV/0! | 361 | 8,83 | 313 | 8,62 | 267 | 8,08 | 8,51 | 2,43 | 9,48 | 10,2
4,00 |  | #DIV/0! |  | #DIV/0! | 295 | 9,70 | 250 | 9,21 | 9,46 | 2,36 | 10,84 | 12,7
4,50 | 451 | 11,32 | 320 | 11,24 | 274 | 11,25 | 230 | 10,88 | 11,17 | 2,48 | 12,19 | 8,3
5,00 | 422 | 12,93 | 300 | 12,79 | 259 | 12,59 | 216 | 12,34 | 12,66 | 2,53 | 13,54 | 6,5
5,25 | 408 | 13,83 |  | #DIV/0! |  | #DIV/0! |  | #DIV/0! | 13,83 | 2,63 | 14,22 | 2,7
5,33 | 403 | 14,18 |  | #DIV/0! |  | #DIV/0! |  | #DIV/0! | 14,18 | 2,66 | 14,44 | 1,8
5,4 | 396 | 14,68 |  | #DIV/0! |  | #DIV/0! |  | #DIV/0! | 14,68 | 2,72 | 14,63 | -0,4
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

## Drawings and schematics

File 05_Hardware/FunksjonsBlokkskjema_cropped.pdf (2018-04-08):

## Power amplifier Interrupter Signal Source Pulse shaper

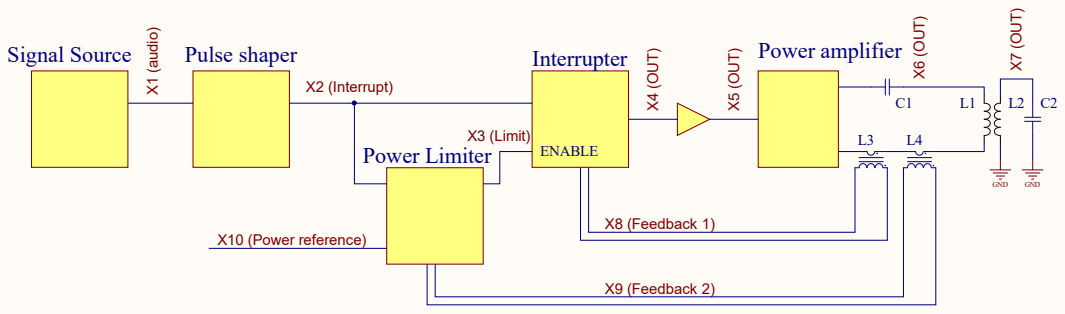
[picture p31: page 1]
GND; Power Limiter; ENABLE; X1 (audio); X2 (Interrupt); X3 (Limit); X4 (OUT); X5 (OUT); X6 (OUT); X8 (Feedback 1); X9 (Feedback 2); X7 (OUT); X10 (Power reference)

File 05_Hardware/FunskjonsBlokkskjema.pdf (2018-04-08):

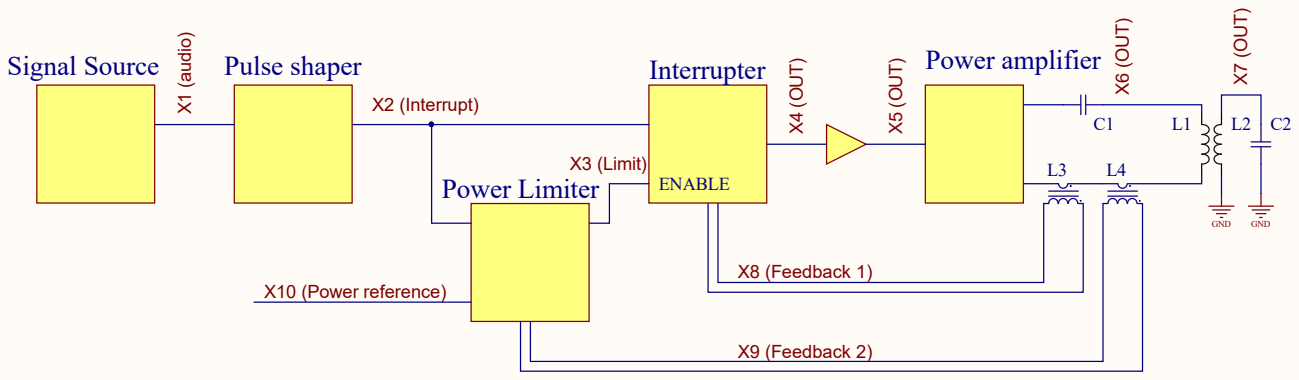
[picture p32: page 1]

Title: *

Size: A3 | Revision: * | Author: *

Date: 29.06.2017 | Sheet * of * | *

C:\git\tesla-driver\05_Hardware\FunskjonsBlokkskjema.SchDoc
File:

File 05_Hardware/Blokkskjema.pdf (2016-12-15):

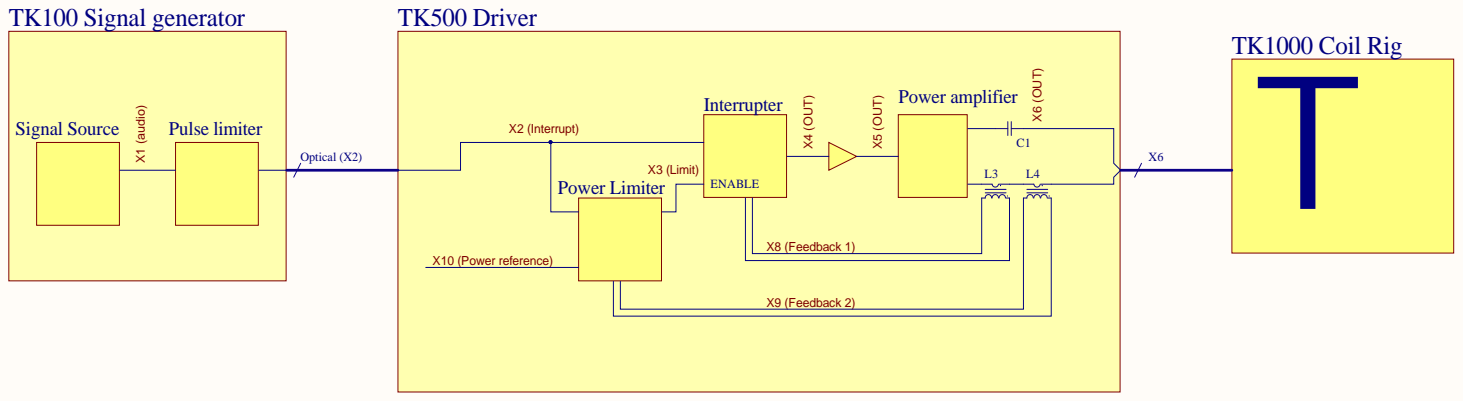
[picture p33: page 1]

* Title | * * * * *

Size: A2 | Number: * | Revision: *

Date: 15.12.2016 Time: 18.46.19 | | Sheet * of *

C:\git\tesla-driver\05_Hardware\Blokkskjema.SchDoc

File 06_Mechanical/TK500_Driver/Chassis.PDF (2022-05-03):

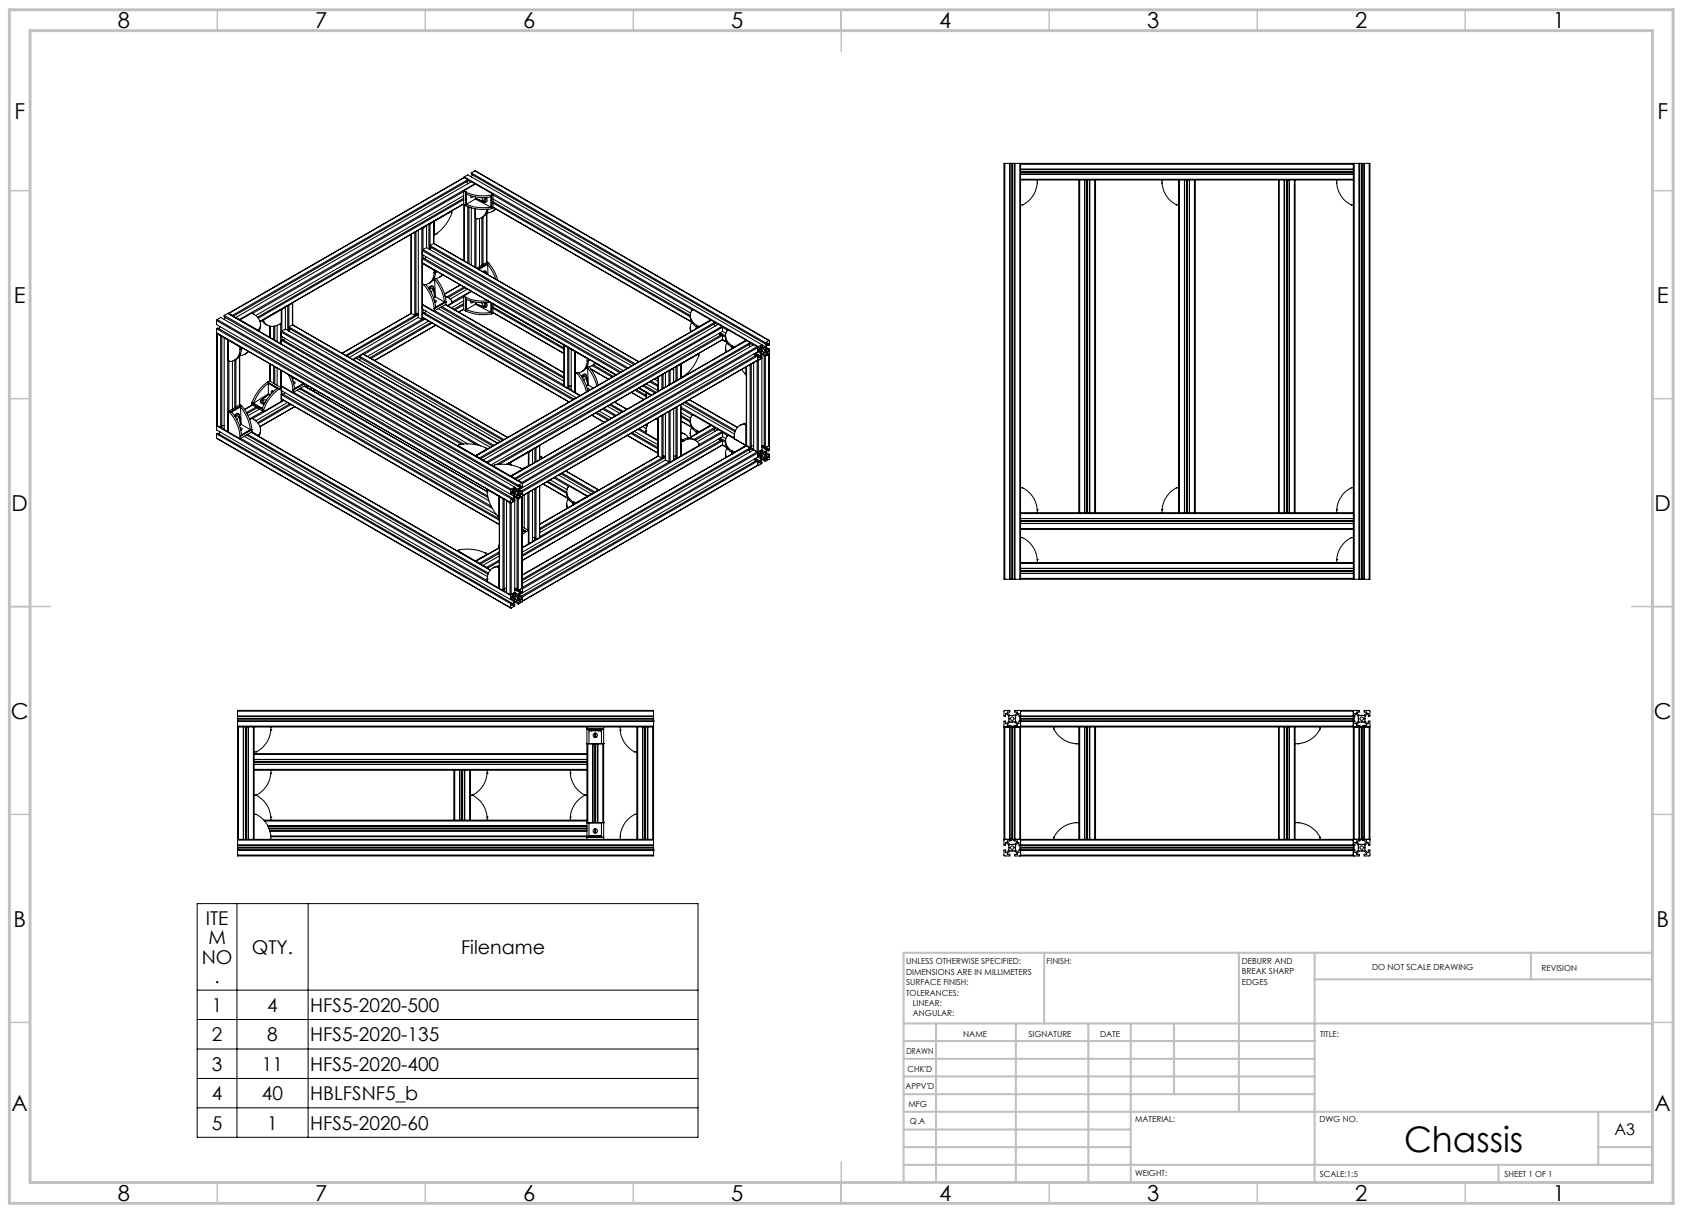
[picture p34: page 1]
FINISH:; DEBURR AND; BREAK SHARP; DO NOT SCALE DRAWING; REVISION; DWG NO.; SCALE:1:5; SHEET 1 OF 1

ITE M NO . | QTY. | Filename

UNLESS OTHERWISE SPECIFIED:
DIMENSIONS ARE IN MILLIMETERS
SURFACE FINISH:
TOLERANCES:
LINEAR:
ANGULAR:

1 | 4 | HFS5-2020-500
2 | 8 | HFS5-2020-135
3 | 11 | HFS5-2020-400

NAME | SIGNATURE | DATE | TITLE:

DRAWN
CHK'D

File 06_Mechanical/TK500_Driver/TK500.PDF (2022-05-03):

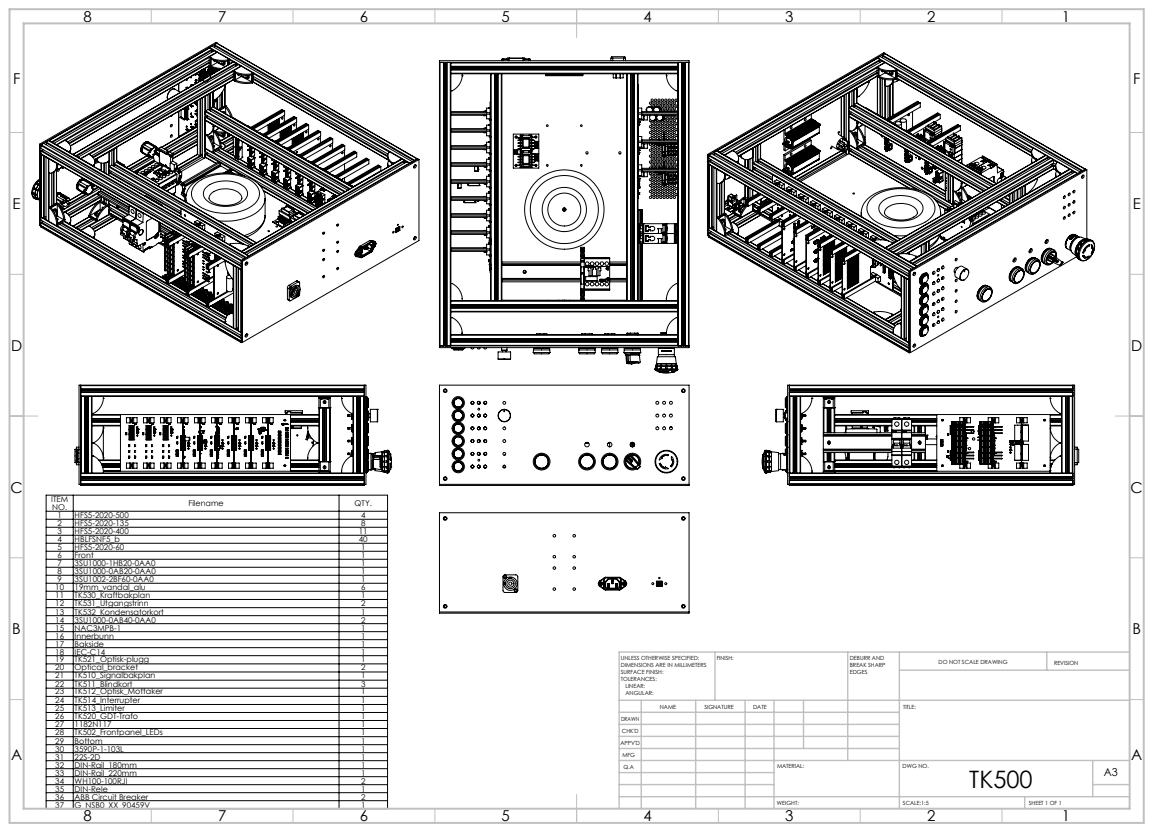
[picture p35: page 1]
DWG NO.

ITEM NO. | Filename | QTY.
1 | HFS5-2020-500 | 4
2 | HFS5-2020-135 | 8
3 | HFS5-2020-400 | 11
4 | HBLFSNF5_b | 40
5 | HFS5-2020-60 | 1
6 | Front | 1
8 | 3SU1000-0AB20-0AA0 | 1
9 | 3SU1002-2BF60-0AA0 | 1
10 | 19mm_vandal_alu | 6
11 | TK530_Kraftbakplan | 1
12 | TK531_Utgangstrinn | 2
13 | TK532_Kondensatorkort | 1
14 | 3SU1000-0AB40-0AA0 | 2
15 | NAC3MPB-1 | 1
16 | Innerbunn | 1
17 | Bakside | 1
18 | IEC-C14 | 1
19 | TK521_Optisk-plugg | 1
20 | Optical_bracket | 2
21 | TK510_Signalbakplan | 1
22 | TK511_Blindkort | 3
23 | TK512_Optisk_Mottaker | 1
24 | TK514_Interrupter | 1
25 | TK513_Limiter | 1
27 | 1182N117 | 1
28 | TK502_Frontpanel_LEDs | 1
30 | 3590P-1-103L | 1
31 | 22S-2D | 1
33 | DIN-Rail_220mm | 1
34 | WH100-100RJI | 2
35 | DIN-Rele | 1
36 | ABB Circuit Breaker | 2
37 | G_NSB0_XX_90459V | 1

UNLESS OTHERWISE SPECIFIED: DIMENSIONS ARE IN MILLIMETERS SURFACE FINISH: TOLERANCES: LINEAR: ANGULAR: | FINISH: | DEBURR AND BREAK SHARP EDGES | DO NOT SCALE DRAWING | REVISION

NAME | SIGNATURE | DATE | TITLE:

CHK'D

MFG

WEIGHT: | SCALE:1:5 | SHEET 1 OF 1

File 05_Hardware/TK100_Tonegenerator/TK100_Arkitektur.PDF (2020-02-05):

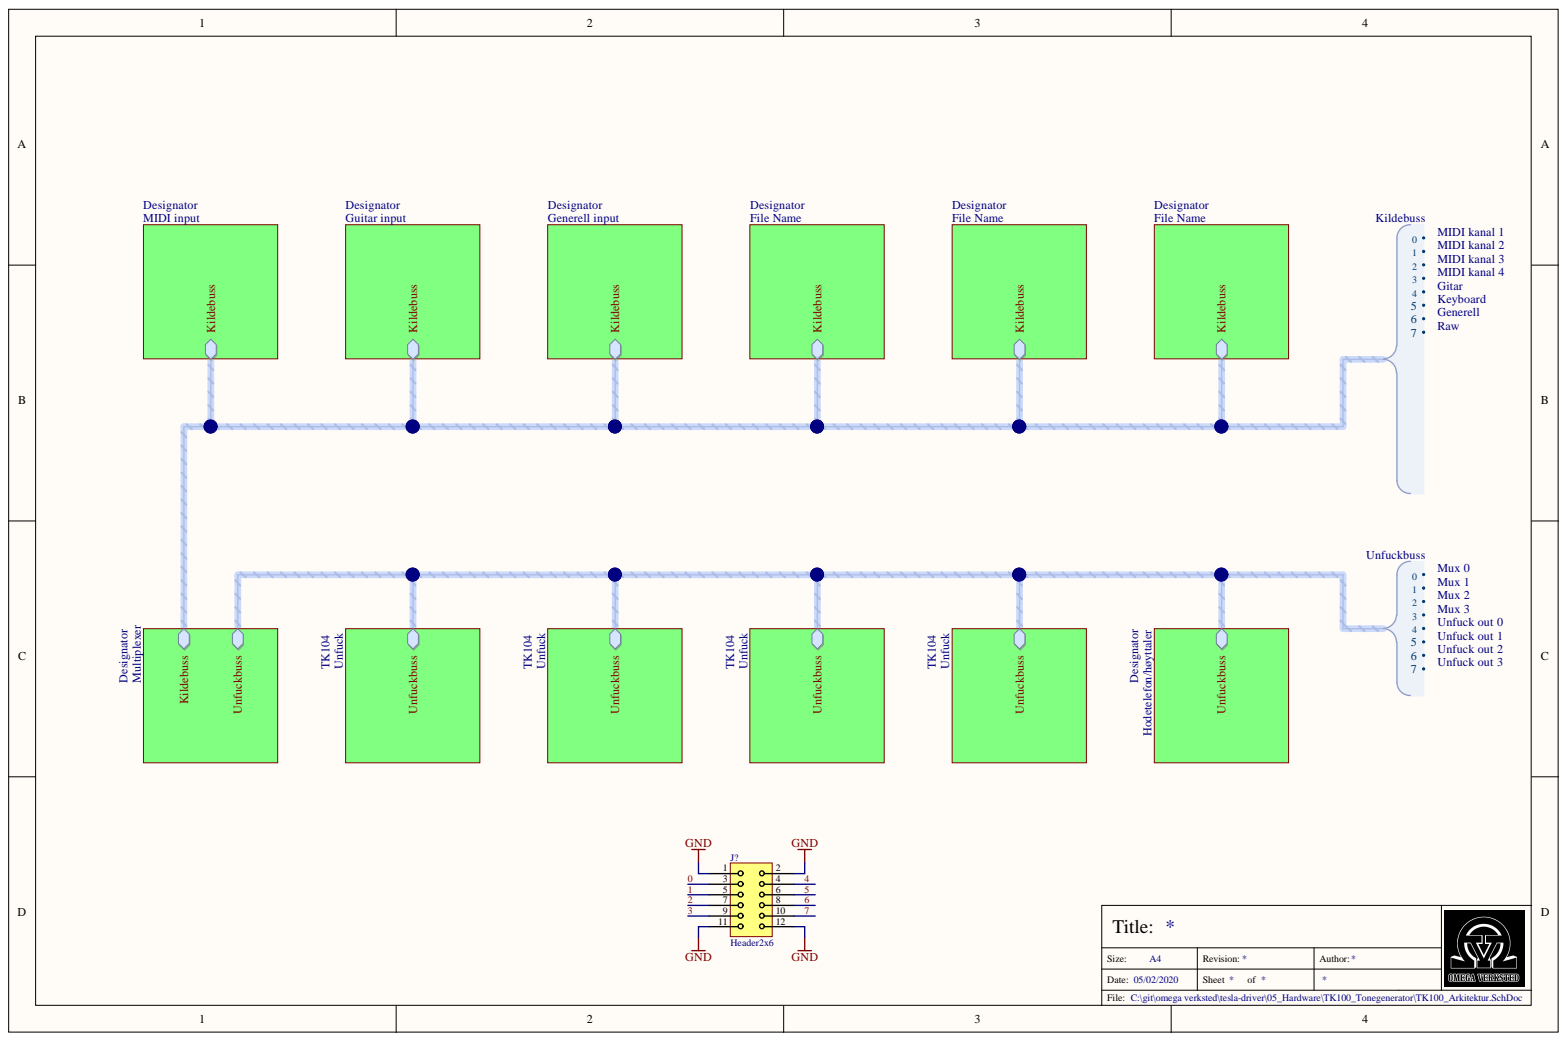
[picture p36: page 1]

Title: *

Size: A4 | Revision: * | Author: *

Date: 05/02/2020 | Sheet * of * | *

C:\git\omega verksted\tesla-driver\05_Hardware\TK100_Tonegenerator\TK100_Arkitektur.SchDoc

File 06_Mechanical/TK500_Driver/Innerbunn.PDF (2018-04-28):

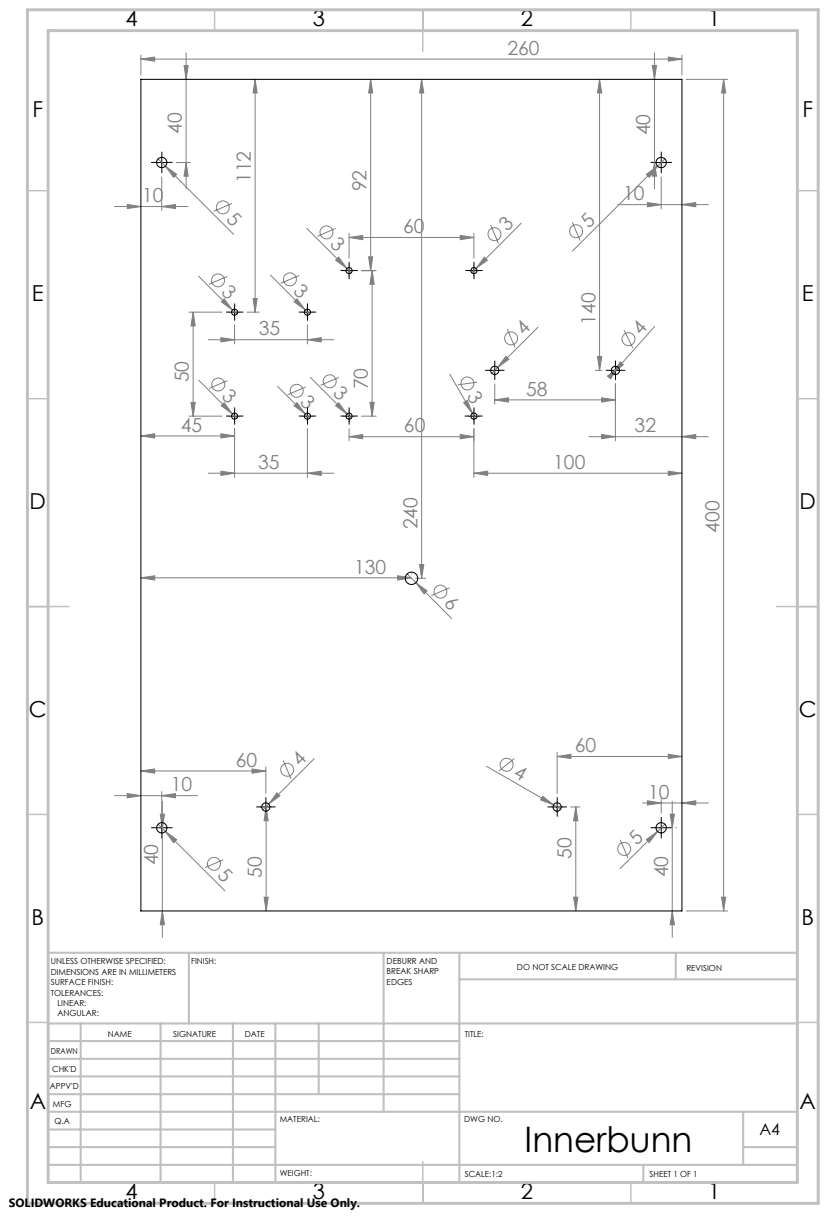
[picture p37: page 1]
FINISH:; DEBURR AND; BREAK SHARP; DO NOT SCALE DRAWING; REVISION; SCALE:1:2; SHEET 1 OF 1

UNLESS OTHERWISE SPECIFIED:
DIMENSIONS ARE IN MILLIMETERS
SURFACE FINISH:
TOLERANCES:
LINEAR:
ANGULAR:

NAME | SIGNATURE | DATE | | | | TITLE:

DRAWN
CHK'D
APPV'D
MFG
Q.A | | | | MATERIAL: | DWG NO. Innerbunn | A4

SOLIDWORKS Educational Product. For Instructional Use Only.

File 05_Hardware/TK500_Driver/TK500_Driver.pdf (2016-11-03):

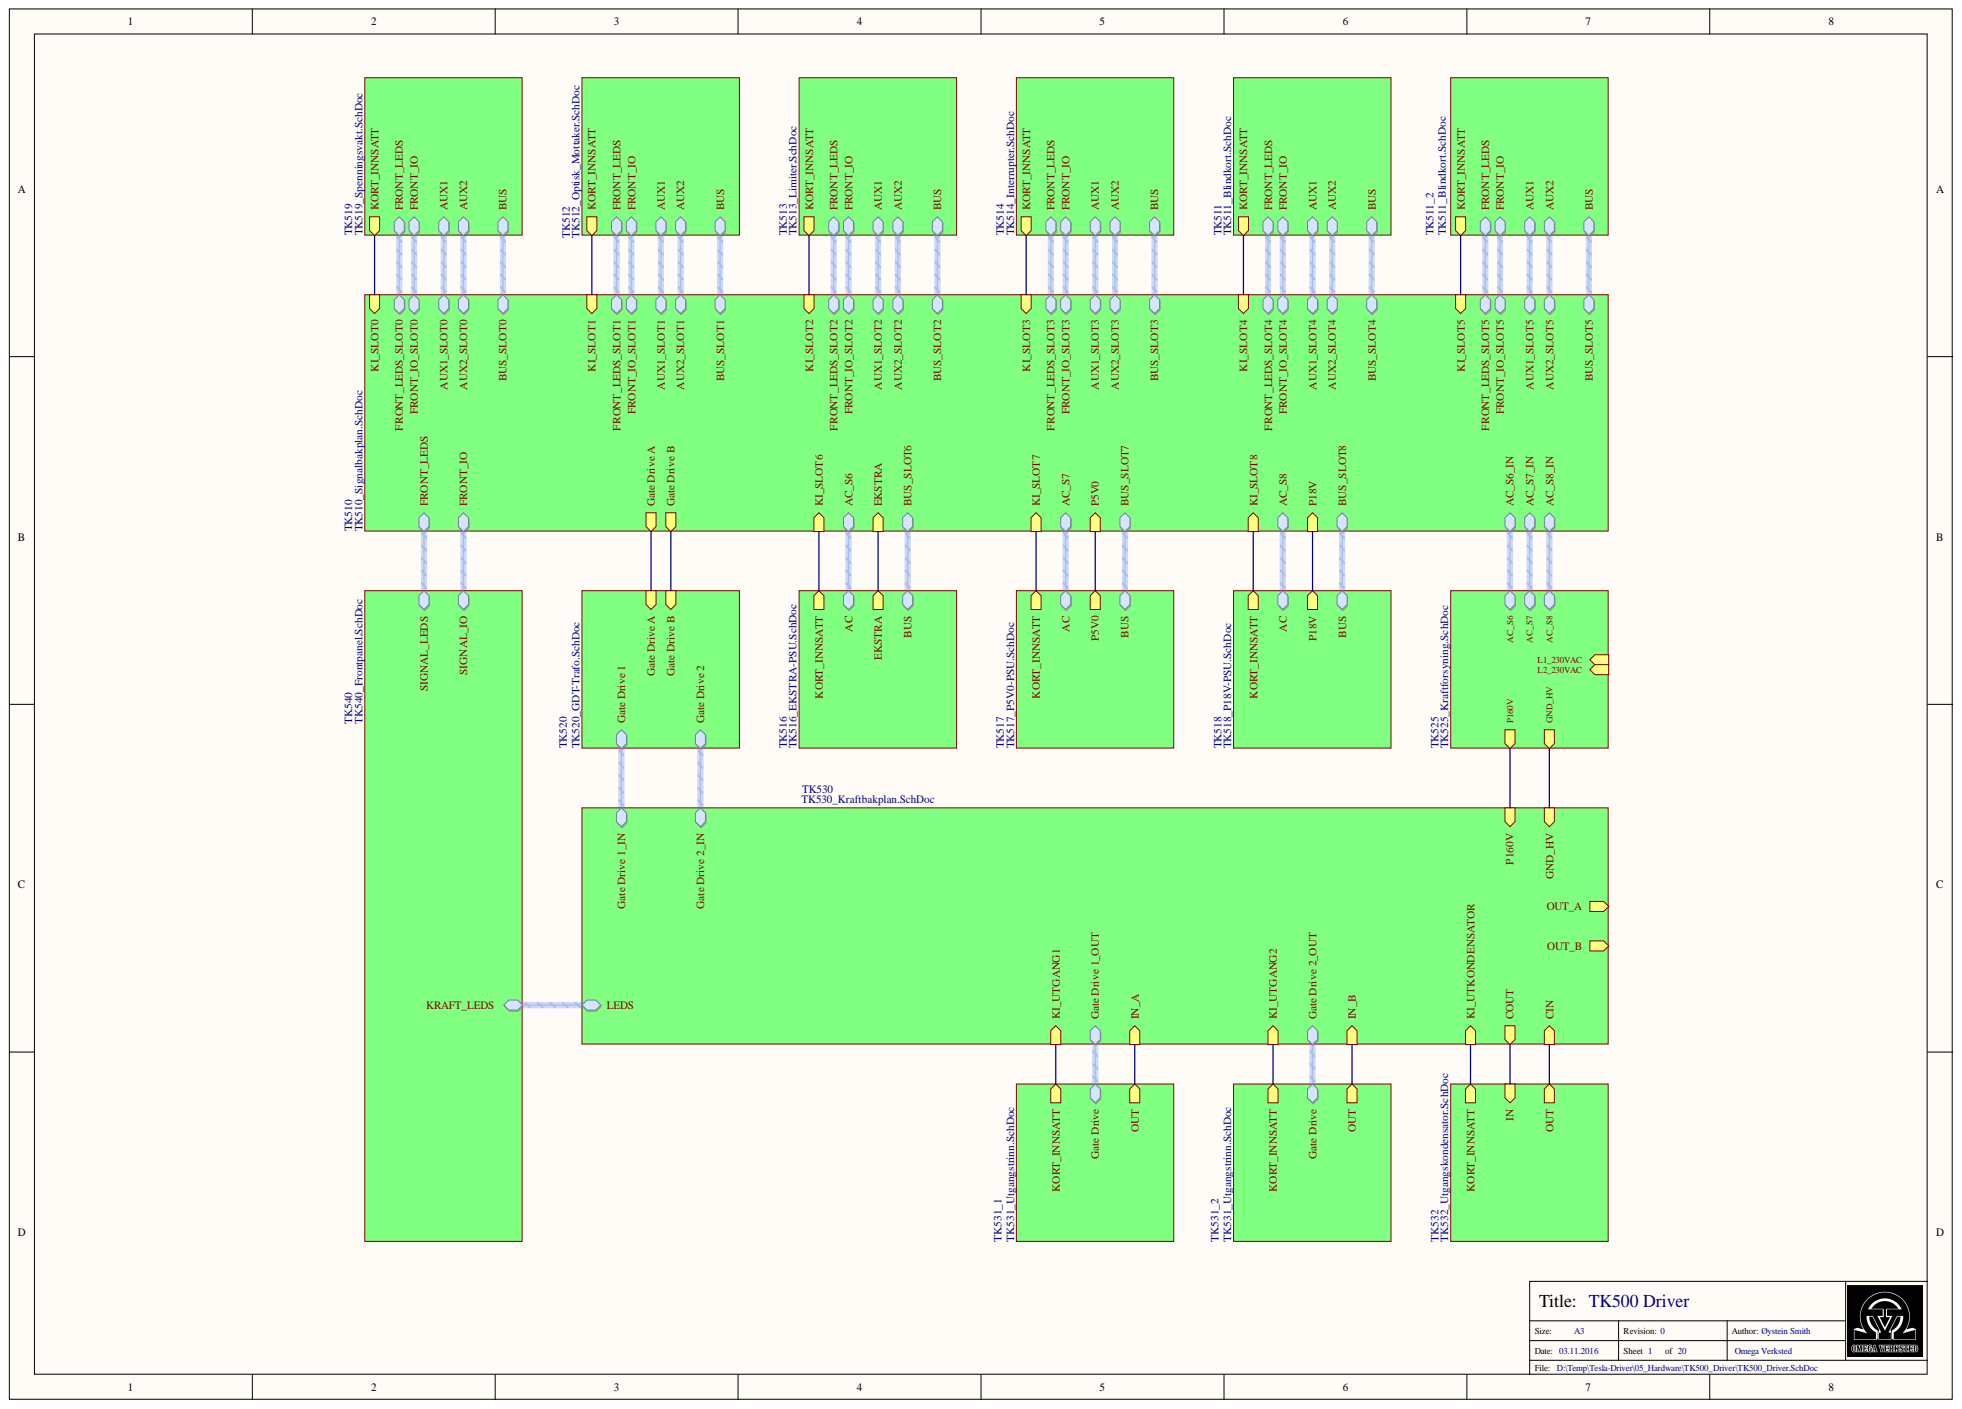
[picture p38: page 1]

Title: TK500 Driver

Size: A3 | Revision: 0 | Author: Øystein Smith

Date: 03.11.2016 | Sheet 1 of 20 | Omega Verksted

D:\Temp\Tesla-Driver\05_Hardware\TK500_Driver\TK500_Driver.SchDoc

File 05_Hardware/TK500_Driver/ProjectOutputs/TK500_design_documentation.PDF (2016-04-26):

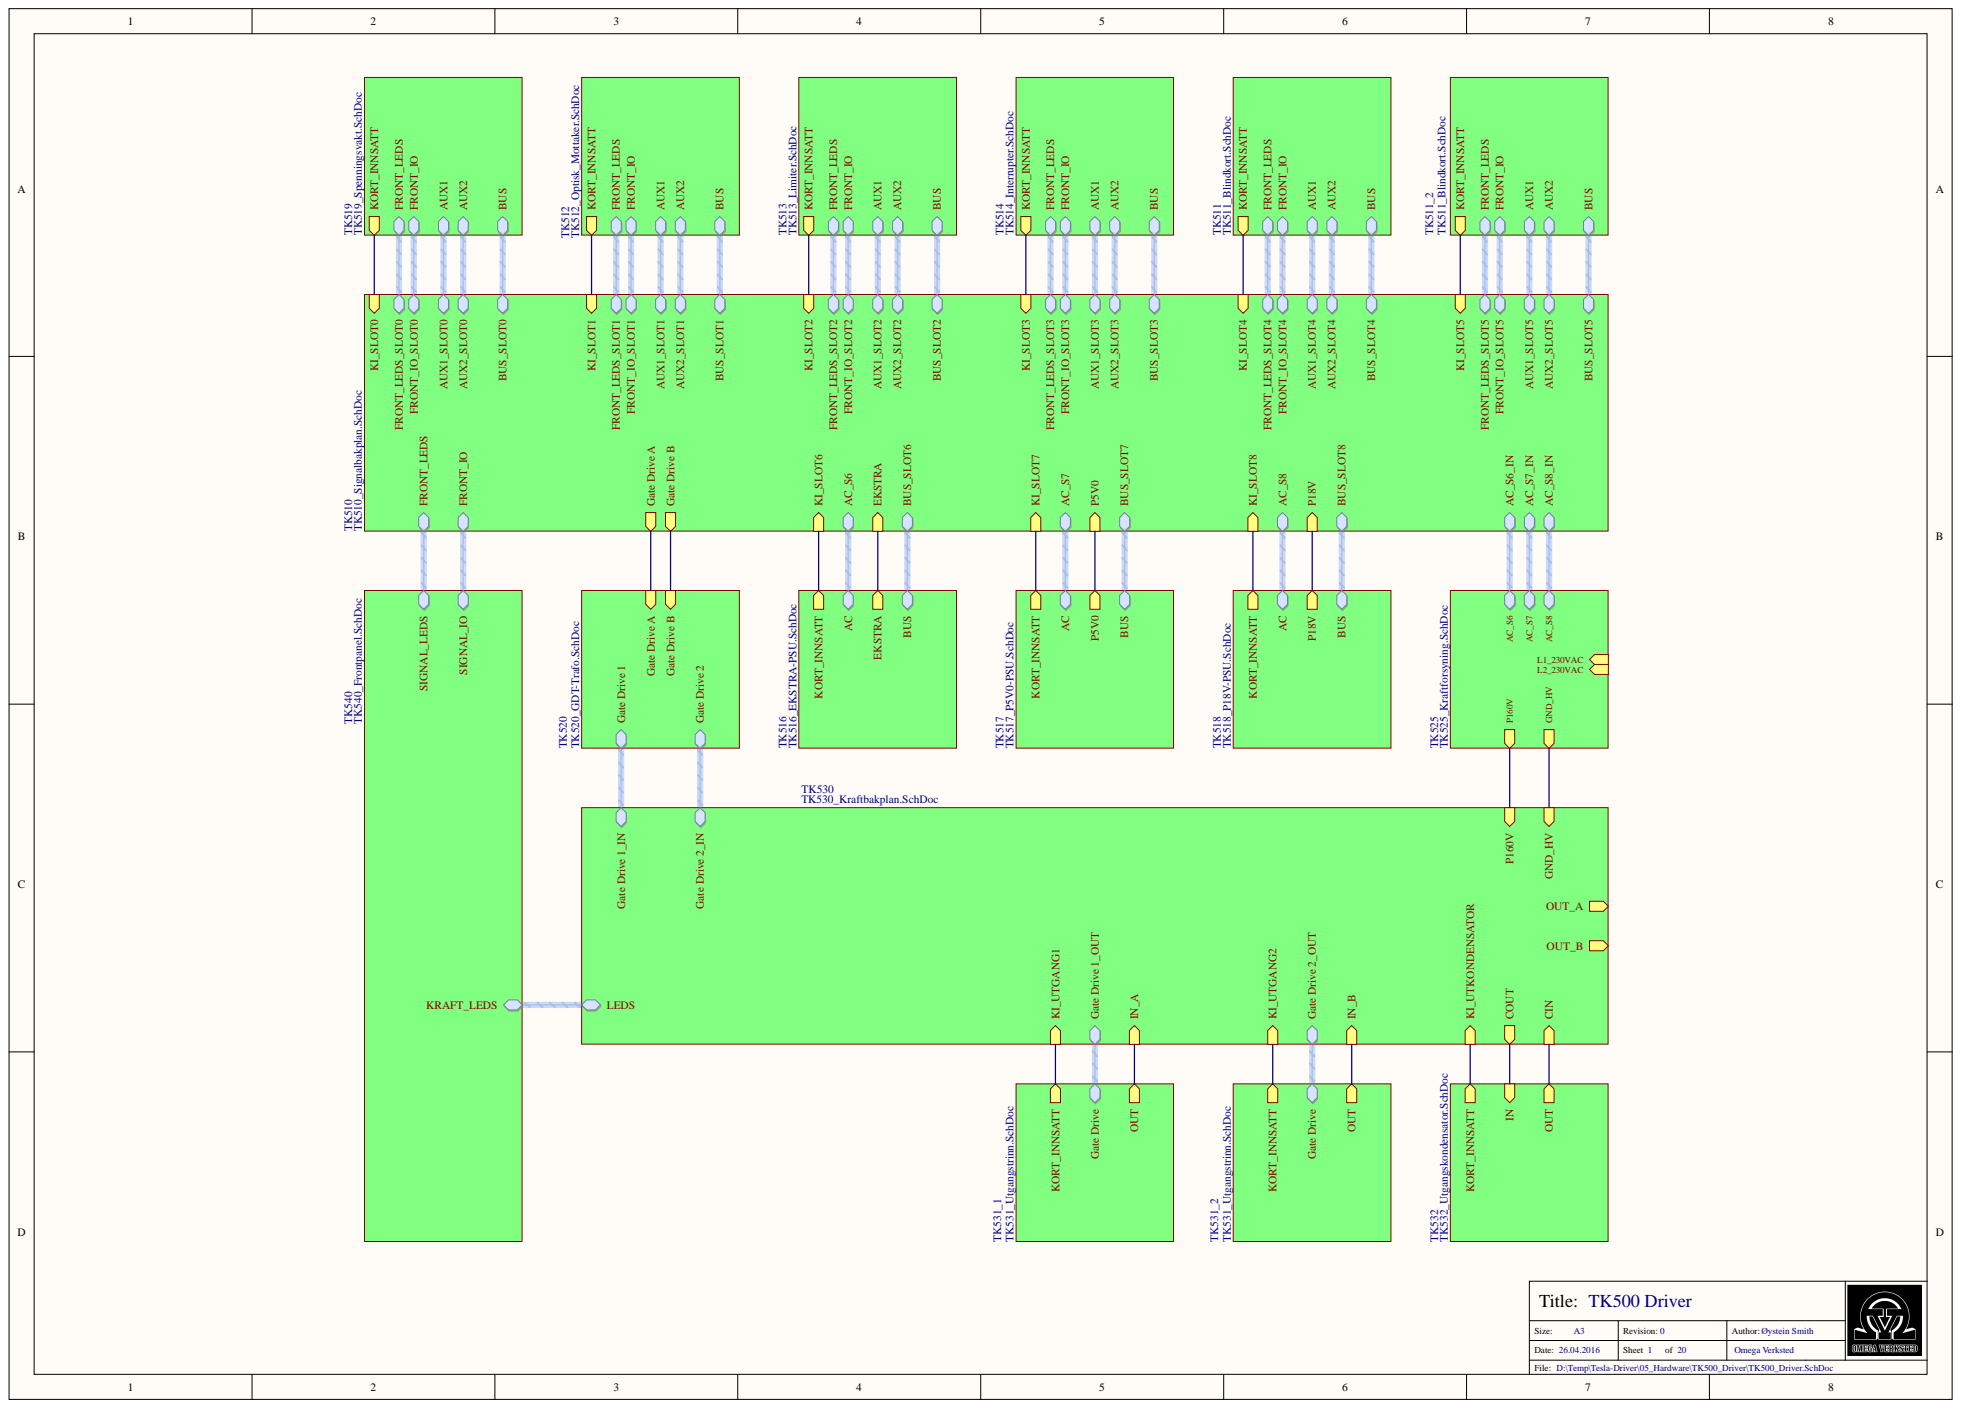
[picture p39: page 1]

Title: TK500 Driver

Size: A3 | Revision: 0 | Author: Øystein Smith

Date: 26.04.2016 | Sheet of | Omega Verksted

D:\Temp\Tesla-Driver\05_Hardware\TK500_Driver\TK500_Driver.SchDoc

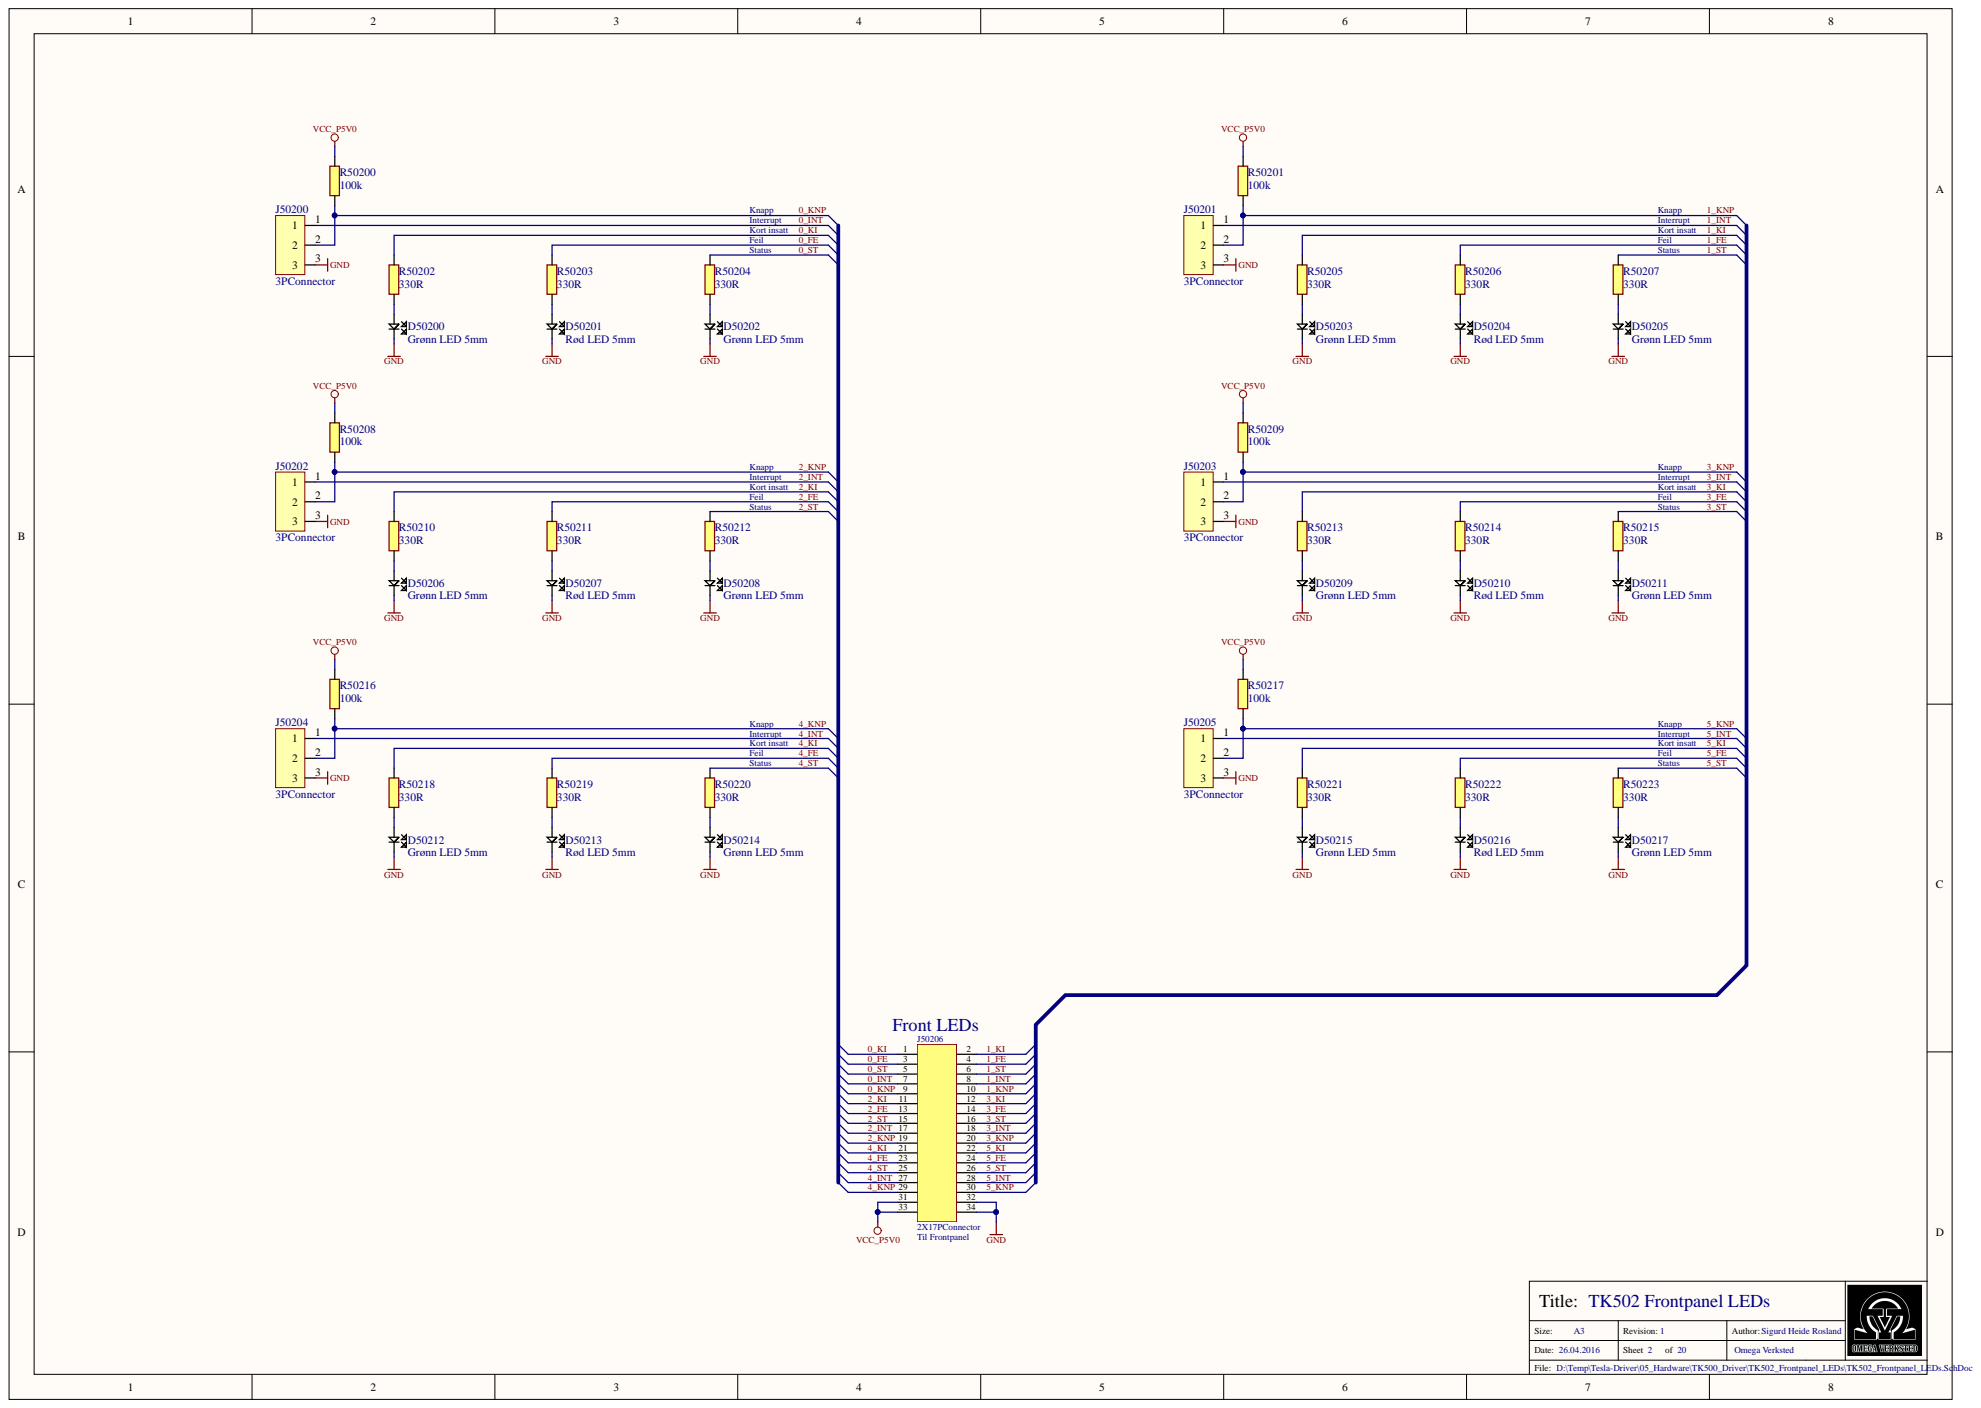
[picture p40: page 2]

TK502 Frontpanel LEDs

1 | Sigurd Heide Rosland

D:\Temp\Tesla-Driver\05_Hardware\TK500_Driver\TK502_Frontpanel_LEDs\TK502_Frontpanel_LEDs.SchDoc

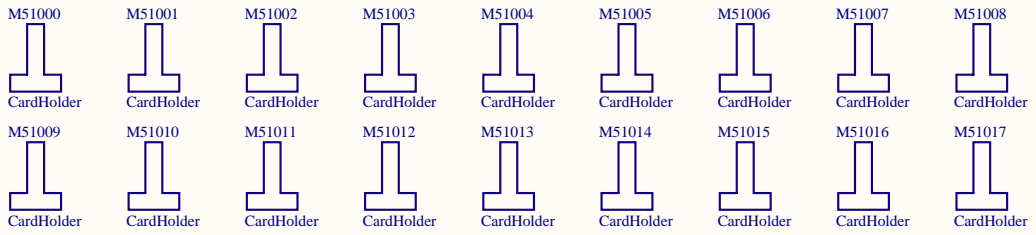
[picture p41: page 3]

D:\Temp\Tesla-Driver\05_Hardware\TK500_Driver\TK510_Signalbakplan\TK510_Mekanisk.SchDoc

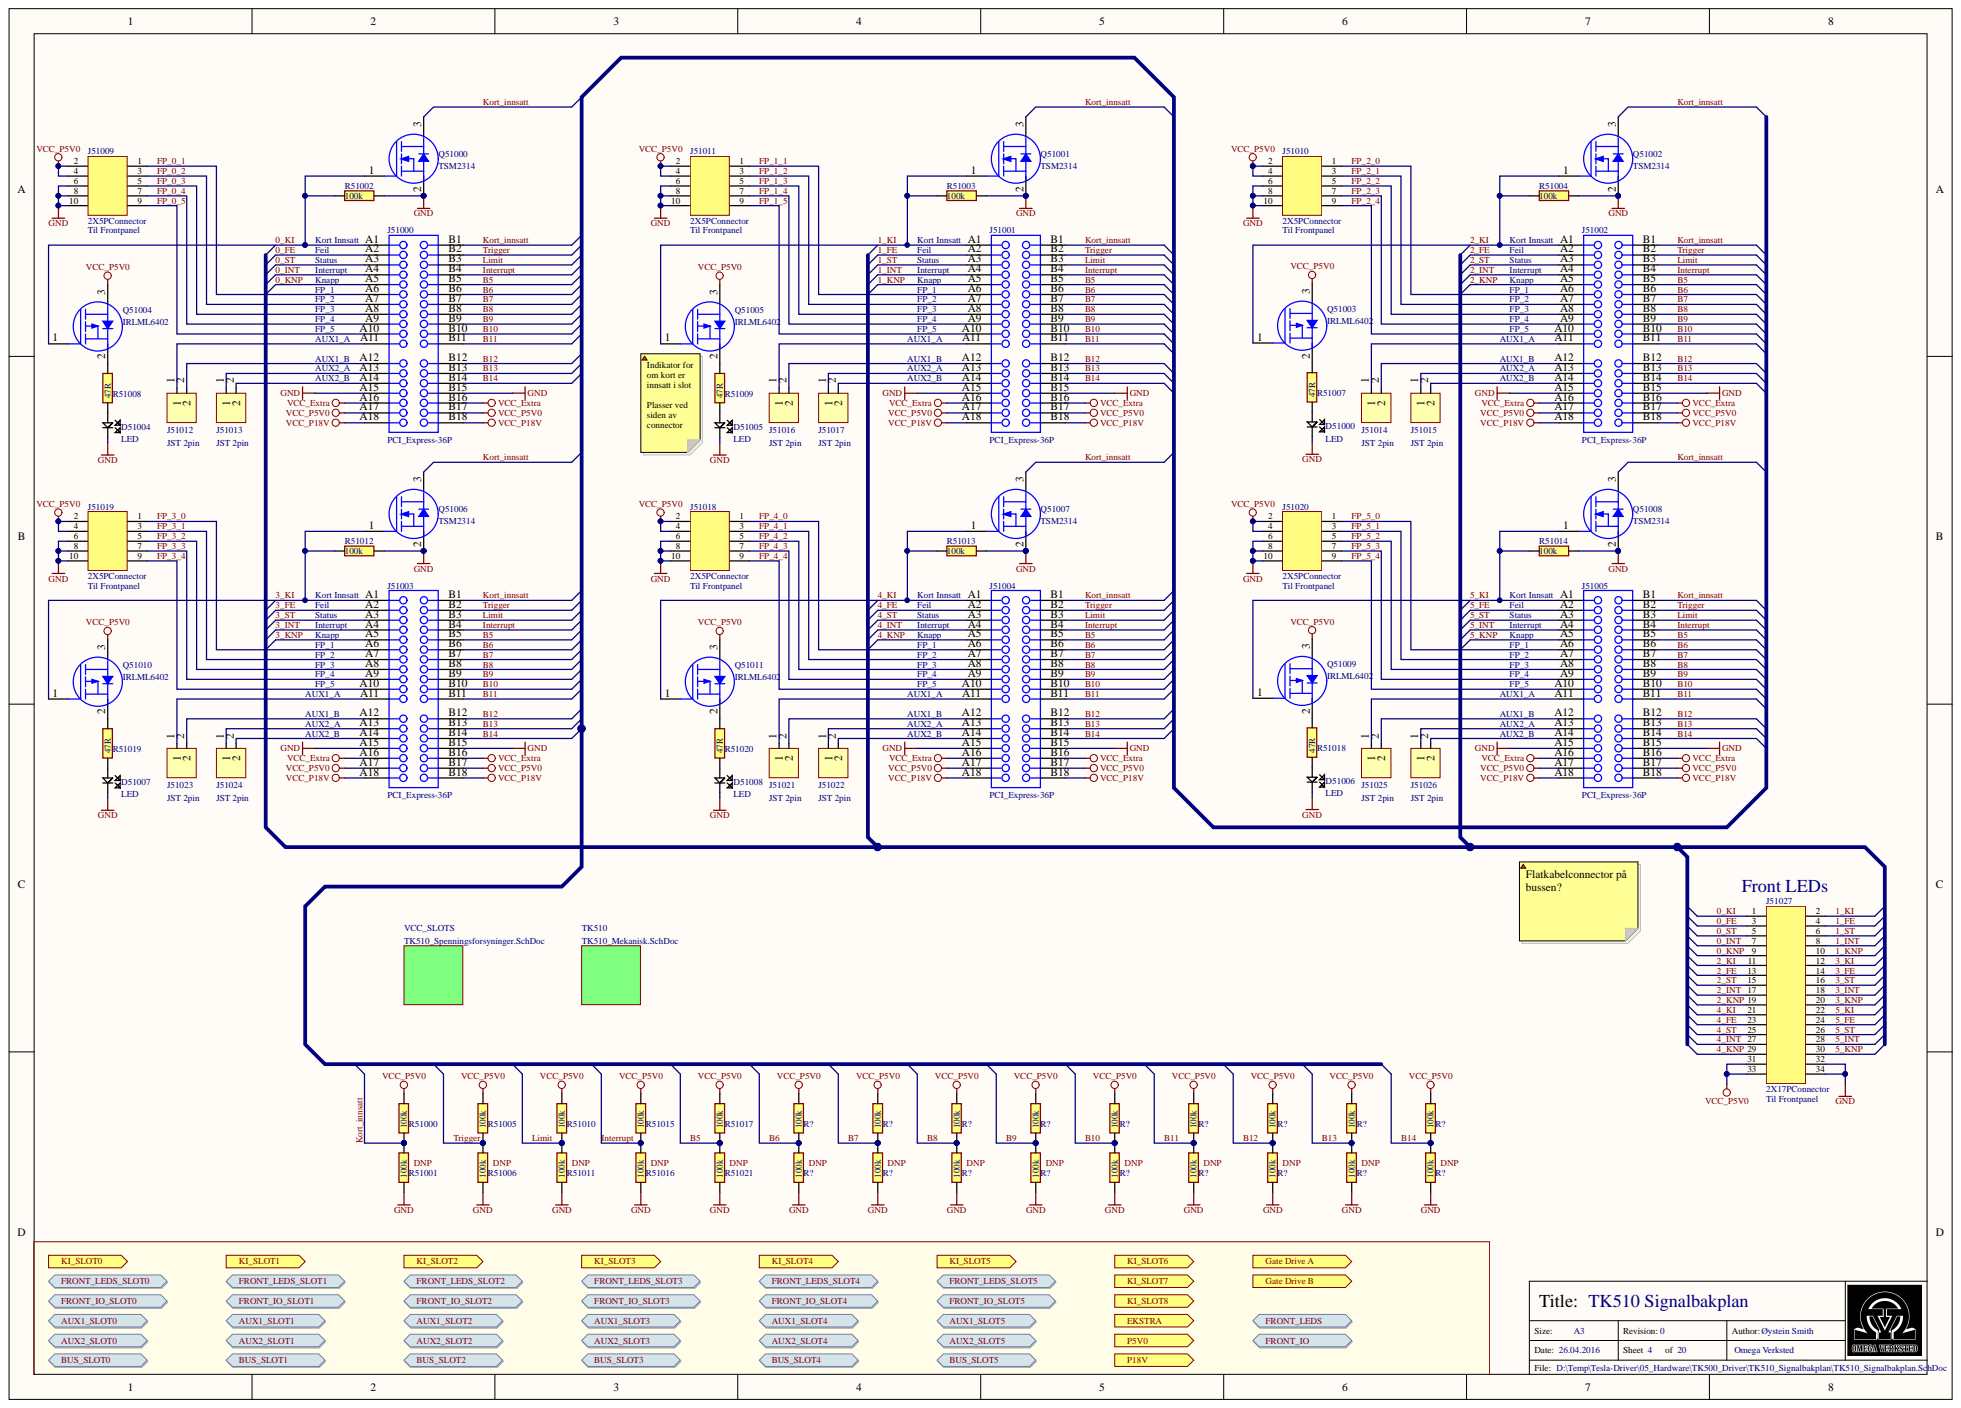
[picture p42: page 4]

D:\Temp\Tesla-Driver\05_Hardware\TK500_Driver\TK510_Signalbakplan\TK510_Signalbakplan.SchDoc


D:\Temp\Tesla-Driver\05_Hardware\TK500_Driver\TK511_Blindkort\TK511_Blindkort.SchDoc


D:\Temp\Tesla-Driver\05_Hardware\TK500_Driver\TK512_Optisk_Mottaker\TK512_Optisk_Mottaker.SchDoc


D:\Temp\Tesla-Driver\05_Hardware\TK500_Driver\TK513_Limiter\TK513_Limiter.SchDoc


Gate drive IC'er
Flytte til eget kort? Lettere å bytte

Lavpassfilter med fg=362Hz
koblet til reset på latchen

D:\Temp\Tesla-Driver\05_Hardware\TK500_Driver\TK514_Interrupter\TK514_Interrupter.SchDoc


TK516 EKSTRA-PSU

D:\Temp\Tesla-Driver\05_Hardware\TK500_Driver\TK516_EKSTRA-PSU.SchDoc


TK517 P5V0-PSU

D:\Temp\Tesla-Driver\05_Hardware\TK500_Driver\TK517_P5V0-PSU\TK517_P5V0-PSU.SchDoc


TK518 P18V-PSU

D:\Temp\Tesla-Driver\05_Hardware\TK500_Driver\TK518_P18V-PSU\TK518_P18V-PSU.SchDoc


TK519 Spenningsvakt

D:\Temp\Tesla-Driver\05_Hardware\TK500_Driver\TK519_Spenningsvakt\TK519_Spenningsvakt.SchDoc


Dual Gate Drive Transformer

D:\Temp\Tesla-Driver\05_Hardware\TK500_Driver\TK520_GDT-Trafo\TK520_GDT-Trafo.SchDoc


D:\Temp\Tesla-Driver\05_Hardware\TK500_Driver\TK525_Hovedstrom.SchDoc


TK525 HVDC

A3 | 15 20 0 | Author : Øystein Smith

Omega Verksted

D:\Temp\Tesla-Driver\05_Hardware\TK500_Driver\TK525_HVDC.SchDoc


TK525 Kraftforsyning

A3 | 16 20 0 | Author : Øystein Smith

Omega Verksted


D:\Temp\Tesla-Driver\05_Hardware\TK500_Driver\TK530_Kraftbakplan\TK530_Kraftbakplan.SchDoc


Feil og OK signal koblet
direkte til VC
(Kan gj

res fancy ting med)

GDT_B 2
GDT_A2

TK531 Utgangstrinn

A3 | 18 20 2 | Author : Øystein Smith

Omega Verksted

D:\Temp\Tesla-Driver\05_Hardware\TK500_Driver\TK531_Utgangstrinn\TK531_Utgangstrinn.SchDoc


TK540 Frontpanel

D:\Temp\Tesla-Driver\05_Hardware\TK500_Driver\TK540_Frontpanel.SchDoc


Feil og OK signal koblet
direkte til VC
(Kan gj

res fancy ting med)

TK532 Kondensatorkort

A3 | | Author : Øystein Smith

* * | Omega Verksted

D:\Temp\Tesla-Driver\05_Hardware\TK500_Driver\TK532_Kondensatorkort\TK532_Kondensatorkort.SchDoc


Designator | Quantity | Value | Description

U51300, U51404 | | 2
U51201, U51302, U51401, U51406 | | 4

T52000, T52001 | | 2
S52500, S52501, S52502, S52503, S52512 | | 5 | Kraftig

R53100_TK531_1, R53100_TK531_2, R53101_TK531_1, R53101_TK531_2 | | 4 | 0.25W 1% Generic resistor

R52502 | | 1 | 0.25W 1% Generic resistor

R51406 | | 1 20k | 20K 0.125W 1% 0805 (2012 Metric) SMD

R51401 | | 1 10R | 10R 0.125W 5% 0805 (2012 Metric) SMD

R51400 | | 1 1k | 1K 0.125W 1% 0805 (2012 Metric) SMD

R51306 | | 1 100k | 330R 0.125W 5% 0805 (2012 Metric) SMD

R51304 | | 1 1k | 1K 0.125W 5% 0805 (2012 Metric) SMD

R51303, R51305 | | 2 330R | 330R 0.125W 5% 0805 (2012 Metric) SMD

R51301 | | 1 10R | 330R 0.125W 5% 0805 (2012 Metric) SMD

R51300, R51302 | | 2 1K | 330R 0.125W 5% 0805 (2012 Metric) SMD

R51200, R51201, R51202, R51203, R51204 | | 5 330.00 Ohm | 330R 0.125W 5% 0805 (2012 Metric) SMD

R50202, R50203, R50204, R50205, R50206, R50207, R50210, R50211, R50212, R50213, R50214, R50215, R50218, R50219, R50220, R50221, R50222, R50223 | 18 | | 0.1W 1% Thick film resistor
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

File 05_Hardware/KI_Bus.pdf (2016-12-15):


Title: *

Siz e : A3 | R evision: * | Author : *

Date : | She e t * of * | *

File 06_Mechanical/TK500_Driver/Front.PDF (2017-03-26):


SOLIDWORKS Educational Product. For Instructional Use Only

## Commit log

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2014-01-13 Rename Utlegg2014/IGBT_Driver.SchDoc til Utlegg2014/Interrupter.SchDoc Lagt til en ic til med schmitt triggere
    [IGBT_Driver.PrjPCB, IGBT_Driver_Stage.PcbDoc, IGBT_Driver_Stage.SchDoc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]
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2014-02-27 Endret motstanden i paralell med potmeteret i limiteren fra 10R til 100k. at denne var 10R gjorde at limiteren ikke fungerte.
    [Limiter.SchDoc]
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2014-06-26 Lget en noenlunde fornuftig mappestruktur Laget forslag til navning Ryddet litt i altiumprosjektstruktur
    [DF01S.PcbLib, DF01S.SchLib, Deleliste.ods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]
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2014-07-08 Jobbet litt med signalbakplan Satt samme grid på alle skjemaene (1mm, 2mm synlig, 1mm electrical)
    [A5.SchLib, Micro3.PcbLib, TK500_Driver.SchDoc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]
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2014-07-12 Jobbet med signalbakplan, begynner å bli bra, på tide med review Lagt til template outjobs
    [Bill of Materials Fitted-TK500_Driver.xls, TK500_Driver.SchDoc, TK510_Mekanisk.SchDoc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]
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2014-07-13 Lagt til LED, og etset ny optisk mottaker rev 0.2 (Gammelt kortformat)
    [Panel.PcbDoc, TK510_Signalbakplan.PrjPcb, TK512_Optisk_Mottaker.PcbDoc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]
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2015-02-06 Rotet rundt på bakplanskortene Lagt til kontakter for spenning ut fra signalbakplanet Usikker på om fila blir med nå???
    [TK510_Mekanisk.SchDoc, TK510_Signalbakplan.PcbDoc, TK510_Signalbakplan.PrjPcb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]
2015-02-17 Lekt litt med outjobs og oppdatert BOM i regneark. Meningen å automatisere en komplett BOM med priser og bestillingsinfo
    [Deleliste_bla.ods, TK511_DC-PSU.PrjPcb, TK511_DC-PSU.SchDoc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]
2015-02-20 Flippet Signalbakplanutlegget (skal stå på venstre side)
    [TK510_Signalbakplan.PcbDoc]
2015-02-20 ferdig? med utlegg til kraftbakplan rotet rundt i signalbakplan (flippa komponenter o.l.)
    [TK510_Signalbakplan.PcbDoc, TK530_Kraftbakplan.PcbDoc, TK530_Kraftbakplan.PrjPcb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]
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2015-04-02 Revidert OLD_DC_PSU lagt til flere plugger ut og andre småting i utlegget
    [TK511_DC-PSU.PcbDoc, TK511_DC-PSU.PrjPcb, TK511_DC-PSU.SchDoc]
2015-06-07 Jobbet med utgangstrinn Satt på connector Oppdatert komponenter med 3D modell Sourcet kjøleribbe
    [TK511_DC-PSU.step, TK513_Limiter.step, TK514_Interrupter.PcbDoc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]
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2015-06-20 Fixed missing GND connection on feedback input
    [TK513_Limiter.SchDoc]
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2015-06-23 Lagt til keepoutsoner Lagt til en decoupling cap (trenger flere) Lagt til monteringshull i hjørnene
    [TK530_Kraftbakplan.PcbDoc, TK530_Kraftbakplan.SchDoc]
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2015-07-05 Tegnet på kraftforsyning Komponentene er ikke nødvendigvis de som er brukt eller har riktig kjøpsinfo
    [TK500_Driver.SchDoc, TK525_HVDC.SchDoc, TK525_Hovedstrom.SchDoc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]
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2015-07-05 Fixed wrong resistor value
    [TK511_DC-PSU.SchDoc]
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2016-04-28 Cleaned up files wich should not be versioned, plus generated output (need to revise folder name)
    [Assembly Testpoint Report for TK510_Signalbakplan.csv, Bill of Materials Fitted-TK510_Signalbakplan.xls, Fabrication Testpoint Report for TK510_Signalbakplan.c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]
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2016-04-29 Fixed issues from review on 115&230V circuit
    [TK520_GDT-Trafo.PcbDoc, TK525_HVDC.SchDoc, TK525_Kraftforsyning.SchDoc]
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2016-05-09 La til navn og beskrivelse på bryter, pluss motstand på kort i serie med knappeLED.
    [TK502_Frontpanel_LEDs.SchDoc]
2016-05-09 Satte motstand i serie med knappeled tentativt til 0 (det er integrert motstand i knapp) + estetiske fixes
    [TK502_Frontpanel_LEDs.SchDoc]
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2016-09-14 Swapped two pins added notes
    [TK101_Tonegenerator_Hovedkort.SchDoc]
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2016-09-23 Fixed library links to OVLib due to updated linking field (a long time ago)
    [TK510_Mekanisk.SchDoc, TK510_Signalbakplan.SchDoc, TK512_Optisk_Mottaker.SchDoc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]
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2016-10-19 Added one via, added margin to edge of pcb, generated gerber and ordered pcb
    [TK101_Tonegenerator_Hovedkort.PcbDoc, TK101_Tonegenerator_Hovedkort.PrjPcb]
2016-10-19 Fixed errors on kraftbakplan generated gerbers
    [TK530_Kraftbakplan.PcbDoc, TK530_Kraftbakplan.PrjPcb, TK530_Kraftbakplan.SchDoc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]
2016-10-19 Done review fixed pmos on kraftbakplan
    [TK530_Kraftbakplan.PcbDoc, TK530_Kraftbakplan.PrjPcb, TK530_Kraftbakplan.SchDoc]
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2016-11-10 Fixed component links, and card inserted bus
    [TK510_Signalbakplan.PcbDoc, TK510_Signalbakplan.PrjPcb, TK510_Signalbakplan.SchDoc]
2016-11-14 Jobbet med utlegg på signalbakplan, endret pinout på header til frontpanel leds
    [TK502_Frontpanel_LEDs.SchDoc, TK510_Mekanisk.SchDoc, TK510_Signalbakplan.PcbDoc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]
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2017-01-09 Fixed Q51012
    [TK510_Signalbakplan.SchDoc]
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2017-01-11 Fixed stuff from review 110117
    [TK510_Signalbakplan.PrjPcb, TK510_Signalbakplan.SchDoc]
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2017-01-20 Fixed silk
    [TK512_Optisk_Mottaker.PcbDoc, TK512_Optisk_Mottaker.PrjPcb, TK512_Optisk_Mottaker.SchDoc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]
2017-02-10 Fixed stuff from review
    [TK512_Optisk_Mottaker.PcbDoc, TK512_Optisk_Mottaker.PrjPcb, TK512_Optisk_Mottaker.SchDoc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]
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2017-03-10 Fixed PBC widths, worked on interrupter
    [TK512_Optisk_Mottaker.SchDoc, TK513_Limiter.PcbDoc, TK513_Limiter.SchDoc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]
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2017-03-17 Fixed some desingators
    [TK511_Blindkort.SchDoc, TK525_HVDC.SchDoc, TK525_Hovedstrom.SchDoc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]
2017-03-20 Fixed outline
    [TK514_Interrupter.PcbDoc, TK514_Interrupter.PrjPcb]
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2017-03-22 Downloaded correct models
    [HBLFSNF5_b.sldprt, HFS5-2020-135.sldprt, HFS5-2020-400.sldprt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]
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2017-03-26 GND plane error
    [TK511_Blindkort.PcbDoc, TK511_Blindkort.PrjPcb]
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2017-06-20 Fixed voltage names
    [Spolerigg1.SchDoc, Spolerigg2.SchDoc, Spolerigg3.SchDoc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]
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2017-08-19 new file: 05_Hardware/TK500_Driver/TK517_P5V0-PSU/44268 Myrra Transformer.PcbLib new file: 05_Hardware/TK500_Driver/TK517_P5V0-PSU/44268 Myrra Transformer.SchLib new file: 05_Hardware/TK500_Driver/TK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
    [44268 Myrra Transformer.PcbLib, 44268 Myrra Transformer.SchLib, TK517_P5V0-PSU.PcbDoc]
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2017-08-19 modified: 05_Hardware/TK500_Driver/TK517_P5V0-PSU/TK517_P5V0-PSU.PcbDoc modified: 05_Hardware/TK500_Driver/TK517_P5V0-PSU/TK517_P5V0-PSU.PrjPcb modified: 05_Hardware/TK500_Driver/TK517_P5V0-PSU/TK517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
    [TK511_Blindkort.PrjPcb, TK513_Limiter.PrjPcb, TK517_P5V0-PSU.PcbDoc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]
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2017-08-31 new file: 05_Hardware/TK500_Driver/TK512_Optisk_Mottaker/Project Outputs/TK512_Optisk_Mottaker.PDF new file: 05_Hardware/TK500_Driver/TK517_P5V0-PSU/DBLS207G Rectifier.PcbLib new file: 05_Hardware/TK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
    [44268 Myrra Transformer.PcbLib, 44268 Myrra Transformer.SchLib, DBLS207G Rectifier.PcbLib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]
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2018-04-28 Lagt til flere hull i innerplate. Laget tegning med mål for innerplate.
    [Innerbunn.SLDDRW, Innerbunn.SLDPRT]
2018-04-29 Fixed assembly for new innerbunn dimensions
    [1182N117.SLDPRT, 19mm_vandal_alu.SLDPRT, 22S-2D.SLDPRT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]
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2018-10-10 flytting av LED, jumper lagt til for bruk med bare en regulator.
    [TK517_P5V0-PSU.PcbDoc, TK517_P5V0-PSU.SchDoc]
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2018-10-10 fix fra review
    [44268 Myrra Transformer.PcbLib, 44268 Myrra Transformer.SchLib, DBLS207G Rectifier.PcbLib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]
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2018-10-15 OutJob Regulator, outline fix
    [TK516_LINREG-PSU.PcbDoc, TK516_LINREG-PSU.step]
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2019-02-17 Added 0Ohm resistors to select right/left channel from mini-jack, changed pull ups after optocoupler to 4.7k
    [TK104_Pulsbegrenser_Eurorack.PcbDoc, TK104_Pulsbegrenser_Eurorack.SchDoc]
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2019-07-08 Fixed avstand mellom hull og bredde
    [TK106_Frontpanel.PcbDoc]
2019-07-09 Tweaked layout (moved minijack on line with other modules), added caps, done routing.
    [TK106_MIDI_Konnektorer.PcbDoc, TK106_MIDI_Konnektorer.PrjPCB, TK106_MIDI_Konnektorer.SchDoc]
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2019-12-20 Rail holes in front 3mm to far apart, holes for rails is M4 not M3, error in tab widths when changing material thickness
    [Eurorack_box_3U_1U_40HP.DXF, Eurorack_box_3U_1U_40HP.SLDPRT]
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2019-12-21 Removed some construction lines, moved parts to more compact layout, to ease flow from bugfixing to cutting
    [Eurorack_box_3U_1U_40HP.DXF, Eurorack_box_3U_1U_40HP.SLDPRT]
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2019-12-21 Tabs on backplate had wrong direction
    [Eurorack_box_3U_40HP.DXF, Eurorack_box_3U_40HP.SLDPRT]
2020-01-29 Fixed pinout in symbol of diodes that sublimates copper
    [TK531_Utgangstrinn.PcbDoc, TK531_Utgangstrinn.PrjPcb, TK531_Utgangstrinn.SchDoc]
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2020-01-31 Changed headers for OVLib headers, fixed pinout on buttons
    [TK106_MIDI_Konnektorer.PcbDoc, TK106_MIDI_Konnektorer.SchDoc]
2020-01-31 Changed headers on MCU card to female, changed RA bus beader to straight shrouded
    [TK106_MIDI.PcbDoc, TK106_MIDI.PrjPCB, TK106_MIDI.SchDoc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]
2020-01-31 Fixed databaselinks after databasemerge
    [TK106_MIDI_Konnektorer.PcbDoc, TK106_MIDI_Konnektorer.SchDoc]
2020-01-31 Fixed databaselinks after databasemerge + description=beskrivelse in library
    [TK105_Hodetelefonforsterker.PcbDoc, TK105_Hodetelefonforsterker.SchDoc]
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2020-07-22 Updated MIDI_Konnektorer with changes from latest review, changed pot to enc and add button
    [TK106_MIDI_Konnektorer.PcbDoc, TK106_MIDI_Konnektorer.PrjPCB, TK106_MIDI_Konnektorer.SchDoc]
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2021-11-06 Added both green and red led for KI bus, updated all designators, changed KI LED to green
    [TK510_Mekanisk.SchDoc, TK510_Signalbakplan.SchDoc, TK510_Spenningsforsyninger.SchDoc]
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
